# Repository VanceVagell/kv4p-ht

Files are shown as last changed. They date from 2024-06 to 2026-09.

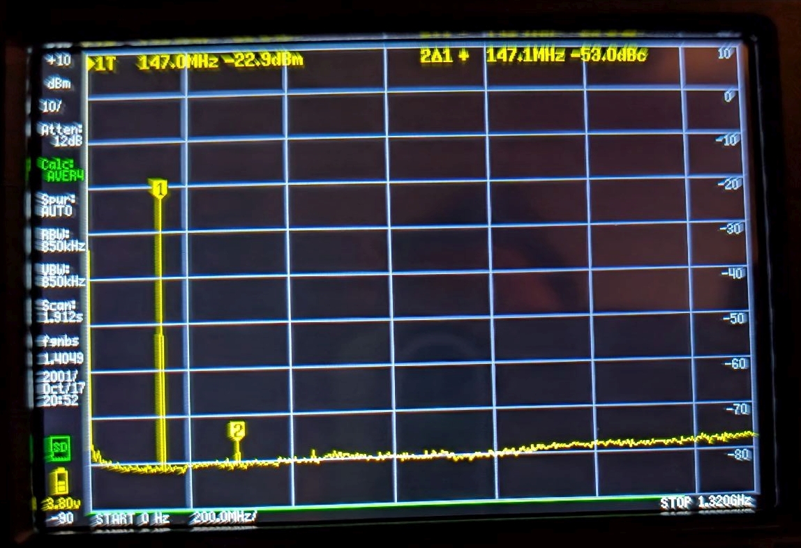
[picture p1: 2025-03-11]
website-src/img/spectral-purity-PCB-v1.8x.jpg

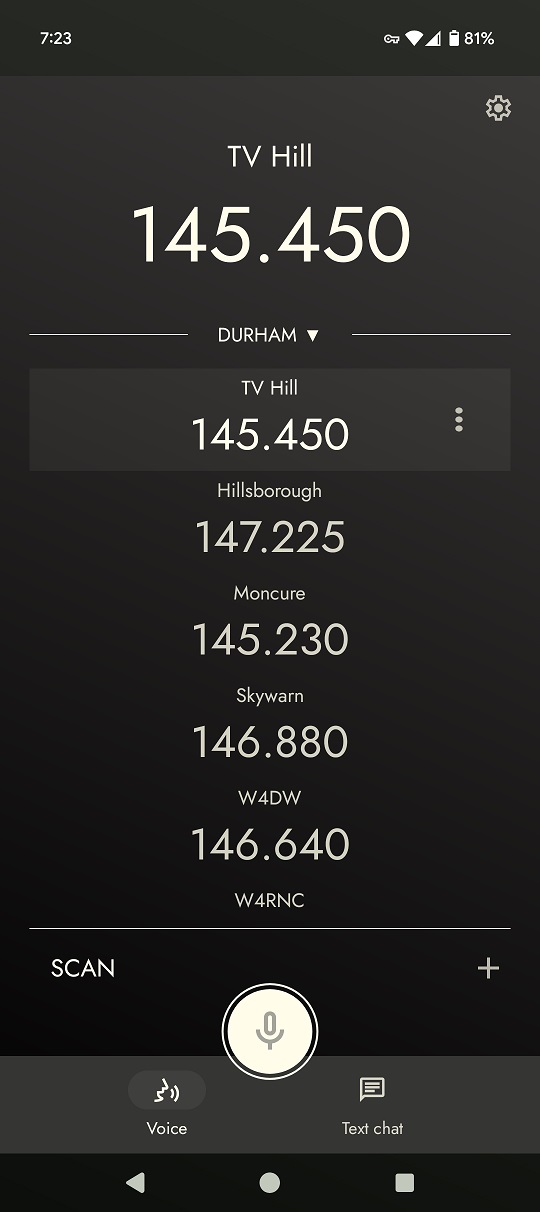
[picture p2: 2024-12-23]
website-src/img/kv4p-ht-voice.jpg

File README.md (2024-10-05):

# kv4p-ht
Open source handheld ham radio project kv4p HT

Please see the main project site: https://kv4p.com

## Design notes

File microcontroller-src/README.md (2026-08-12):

## Table of Contents

- [Table of Contents](#table-of-contents)
- [Getting Started](#getting-started)
   - [Install ESP32 Drivers](#install-esp32-drivers)
   - [Choose your build environment](#choose-your-build-environment )
- [Option 1: PlatformIO](#option-1-platformio)
   - [Install PlatformIO](#install-platformio)
   - [Opening the Project (PlatformIO)](#opening-the-project-platformio)
   - [Building the Project (PlatformIO)](#building-the-project-platformio)
   - [Uploading to the ESP32 (PlatformIO)](#uploading-to-the-esp32-platformio)
   - [PlatformIO Specific Notes](#platformio-specific-notes)
- [Option 2: Arduino IDE](#option-2-arduino-ide)
   - [Install Arduino IDE](#install-arduino-ide)
   - [Install ESP32 Board Support](#install-esp32-board-support)
   - [Install Required Libraries](#install-required-libraries)
   - [Opening the Project (Arduino IDE)](#opening-the-project-arduino-ide)
   - [Building the Project (Arduino IDE)](#building-the-project-arduino-ide)
   - [Uploading to the ESP32 (Arduino IDE)](#uploading-to-the-esp32-arduino-ide)
- [Additional Notes](#additional-notes)

## Getting Started

### Install ESP32 Drivers

1. **Download and Install the Appropriate Driver for Your System:**
   - **CP210x Drivers:** [Silicon Labs CP210x Drivers](https://www.silabs.com/developer-tools/usb-to-uart-bridge-vcp-drivers?tab=downloads)

   Ensure that the driver installation is successful:
   - **Windows:** Check the Device Manager for the COM port associated with your ESP32.
   - **macOS/Linux:** Verify the presence of `/dev/tty.*` devices corresponding to your ESP32.

### Choose Your Build Environment

You can use either Platform IO or Arduino IDE as your build environment. 

- **PlatformIO (Preferred):**
  - Our primary build environment, and the easiest way to get started.
  - Offers an integrated development environment with advanced features such as dependency management, project configuration, and integrated debugging.
  - Ideal for users who require more control and flexibility over their development workflow.
- **Arduino IDE:**
  - Provides a simpler interface that is beginner-friendly and widely used within the Arduino community.
  - Unfortunately for a larger project like `kv4p-ht`, the initial setup is less automated and more complex.

## Option 1: PlatformIO

### Install PlatformIO

1. **Download and Install VSCode:**
   - [Download VSCode](https://code.visualstudio.com/download) and follow the installation instructions for your operating system.

2. **Install PlatformIO Extension:**
   - Open VSCode.
   - Navigate to the Extensions view by clicking on the **Extensions** icon in the Activity Bar on the side of VSCode or pressing `Ctrl+Shift+X` (`Cmd+Shift+X` on macOS).
   - In the search bar, type **"PlatformIO IDE"**.
   - Locate the **PlatformIO IDE** extension by PlatformIO and click **Install**.

3. **Verify Installation:**
   - After installation, the **PlatformIO** icon (alien head) should appear in the VSCode sidebar.
   - Click the **PlatformIO** icon to open the PlatformIO Home interface.

### Opening the Project (PlatformIO)

1. **Open VSCode.**
2. **Open the Project Directory:**
   - Navigate to `kv4p-ht/microcontroller-src/`.
   - Open this directory in VSCode by selecting `File` > `Open Folder` and choosing the specified path.
   - Ensure that the directory contains the `platformio.ini` file to recognize it as a PlatformIO project.
   - *Note:* Opening the root directory may prevent VSCode from recognizing it as a PlatformIO project.
   - *Note:* After opening the project, if VSCode shows a notification bar at the top indicating restricted mode, click **Manage** and then **Trust** in the subsequent dialog to enable all capabilities.

### Building the Project (PlatformIO)

1. **Build the Project:**
   - Click the **Build** icon (checkmark) in the PlatformIO toolbar.
   - Alternatively, press `Ctrl+Alt+B` (`Cmd+Alt+B` on macOS).

2. **Monitor Build Process:**
   - The integrated terminal will display the compilation process.
   - Ensure there are no errors during the build.
   - A successful build will indicate that the firmware is ready for upload.

### Uploading to the ESP32 (PlatformIO)

1. **Connect Your ESP32:**
   - Use a USB cable to connect your ESP32 development board to your computer.
   - Ensure the board is recognized by your system:
     - **Windows:** Check the Device Manager for the COM port.
     - **macOS/Linux:** Check for `/dev/tty.*` devices.

2. **Select the Correct Serial Port:**
   - PlatformIO typically auto-detects the connected board.
   - If not detected, manually specify the serial port:
     - Click on the port icon in the PlatformIO toolbar.
     - Select the appropriate port from the list.

3. **Upload the Firmware:**
   - Click the **Upload** icon (right arrow) in the PlatformIO toolbar or press `Ctrl+Alt+U` (`Cmd+Alt+U` on macOS).
   - PlatformIO will compile (if not already built) and upload the firmware to the ESP32.

4. **Monitor Upload Process:**
   - Watch the terminal for messages indicating upload progress.
   - Upon successful upload, a confirmation message will appear.

### PlatformIO Specific Notes

- **Renaming the Main File for IntelliSense:**
   - ~~**For IntelliSense to work properly in PlatformIO**, rename the main project file from `.ino` to `.cpp`. For example, rename `kv4p_ht_esp32_wroom_32.ino` to `kv4p_ht_esp32_wroom_32.cpp`.~~
      - I don't think this is necessary anymore. My (@SmittyHalibut) PlatformIO does all the right things just editing a .ino file now (Jan 2025).
   - **Important:** Do **not** commit this renamed file to the repository. Keeping the file as `.ino` in the repository ensures compatibility with the Arduino IDE build process.
   - **Workflow Suggestion:**
      - When working locally in PlatformIO, perform the rename to benefit from IntelliSense.
      - Before committing changes, revert the file extension back to `.ino` to maintain Arduino IDE compatibility.

## Option 2: Arduino IDE

### Install Arduino IDE

1. **Download and Install Arduino IDE:**
   - Visit the [Arduino Software Page](https://www.arduino.cc/en/software) and download the latest version suitable for your operating system.
   - Follow the installation instructions provided on the website.

### Install ESP32 Board Support

1. **Open Arduino IDE.**

2. **Install ESP32 Boards:**
   - Go to `Tools` > `Board` > `Boards Manager`.
   - In the Boards Manager window, search for **"ESP32"**.
   - Find **"esp32"** by Espressif Systems.
   - Select version **2.0.17**. The code needs to be updated to support 3.X
   - Click **Install** and Wait for the installation to complete.

3. **Configure**
   - Go to `Tools` > `Events Run On` > Select `Core 0`
     - This is done so audio processing interrupts run on a separate thread for maximum stability.
   - Go to `Tools` > `Partition Scheme` > Select `Minimal SPIFFS (1.9MB APP with OTA/190KB SPIFFS)`
     - This optimizes partitions for large code.

### Install Required Libraries

1. Install DRA818:**

   > **Note:** The version of the DRA818 library available through the Arduino Library Manager is currently broken. To ensure proper functionality, you need to install it manually from the official GitHub release.

   - **Download the DRA818 Library ZIP:**
     - Visit this [commit of the DRA818 v1.0.1 library](https://github.com/fatpat/arduino-dra818.git#89582e3ef7bf3f31f1af149e32cec16c4b9e4cf2). It contains additional definitions needed for the `SA818_VHF` and `SA818_UHF` radio modules.
     - Click the green `Code` button and then `Download ZIP`.

   - **Add the DRA818 Library to Arduino IDE:**
     - Open the Arduino IDE.
     - Go to `Sketch` > `Include Library` > `Add .ZIP Library...`.
     - In the file dialog, navigate to the location where you downloaded the `arduino-dra818-master.zip` file.
     - Select the ZIP file and click **Open**.
     - A confirmation message should appear indicating that the library was added successfully.

2. **Install AudioTools:**

   - **Download the AudioTools Library ZIP:**
     - Visit the [AudioTools v1.2.3 Release Page](https://github.com/pschatzmann/arduino-audio-tools/releases/tag/v1.2.3).
     - Click on the **"Source code (zip)"** link to download the ZIP file of the library.

   - **Add the AudioTools Library to Arduino IDE:**
     - Open the Arduino IDE.
     - Go to `Sketch` > `Include Library` > `Add .ZIP Library...`.
     - In the file dialog, navigate to the location where you downloaded the `arduino-audiotools-1.2.3.zip` file.
     - Select the ZIP file and click **Open**.
     - A confirmation message should appear indicating that the library was added successfully.

3. **Install adpcm:**

   - **Download the adpcm Library ZIP:**
     - Visit the [adpcm v1.2.1 Release Page](https://github.com/pschatzmann/adpcm/releases/tag/v1.2.1).
     - Click on the **"Source code (zip)"** link to download the ZIP file of the library.

   - **Add the adpcm Library to Arduino IDE:**
     - Open the Arduino IDE.
     - Go to `Sketch` > `Include Library` > `Add .ZIP Library...`.
     - In the file dialog, navigate to the location where you downloaded the `codec-adpcm-1.2.1.zip` file.
     - Select the ZIP file and click **Open**.
     - A confirmation message should appear indicating that the library was added successfully.

4. **Install esp32-afsk:**

   - Navigate to `Sketch` > `Include Library` > `Manage Libraries`.
   - In the **Library Manager** window, enter **"esp32-afsk"** into the search bar.
   - Locate the **esp32-afsk** library by **Dmitry Kaukov** in the search results.
   - Click the **Install** button to add the library to your Arduino environment.

5. **Confirm All Libraries Are Installed:**

   - After completing the above steps, go to `Sketch` > `Include Library` and scroll down to the bottom where you will find the section labeled `Contributed Libraries` (light gray). Ensure that **adpcm**, **audio-tools**,  **DRA818** and **esp32-afk** are listed.
   - If any libraries are missing, revisit the installation steps to ensure they were added correctly.

### Opening the Project (Arduino IDE)

1. **Open the Project:**
   - Go to `File` > `Open`.
   - Navigate and open: `kv4p-ht/microcontroller-src/kv4p_ht_esp32_wroom_32/kv4p_ht_esp32_wroom_32.ino`.

### Building the Project (Arduino IDE)

1. **Select the ESP32 Board:**
   - Go to `Tools` > `Board` and select **"ESP32 Dev Module"**.

2. **Select the Correct Port:**
   - Connect your ESP32 to your computer via USB.
   - Go to `Tools` > `Port` and select the appropriate COM port (Windows) or `/dev/tty.*` device (macOS/Linux).

3. **Verify the Sketch:**
   - Click the **Verify** button (checkmark) in the Arduino toolbar or press `Ctrl+R` (`Cmd+R` on macOS).
   - The IDE will compile the sketch and display any errors or warnings in the output pane.
   - Ensure that the sketch compiles without errors.

### Uploading to the ESP32 (Arduino IDE)

1. **Upload the Firmware:**
   - Click the **Upload** button (right arrow) in the Arduino toolbar or press `Ctrl+U` (`Cmd+U` on macOS).
   - The Arduino IDE will compile (if not already done) and upload the firmware to the ESP32.
   - Monitor the output pane for upload progress and confirmation of success.

## Additional Notes

- **Consistent Project Structure:**
  - Ensure that any changes made in one environment (e.g., library installations, code modifications) are compatible with the other to maintain consistency across both build systems.

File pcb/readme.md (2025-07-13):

Build:
```
../scripts/nvs_partition_gen.py generate board-config.csv  board-config.bin 0x6000
```

Flash:
```
esptool.py  write_flash 0x9000 board-config.bin
```

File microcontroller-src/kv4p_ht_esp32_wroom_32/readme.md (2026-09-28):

# KV4P-HT Communication Protocol

## Overview

The KV4P-HT protocol defines the communication interface between the microcontroller and external systems. It specifies message structures and command types for data exchange.

## Protocol Changelog

### v2.0.0.2 (Unreleased, FW: 17)

* Live voice audio changed from Opus on command `0x07` to 16 kHz 4-bit ADPCM on command `0x0C`.
* Added FreeDV 2400B digital voice negotiation with `FEATURE_HAS_FREEDV_2400B` and `HOST_STATE_FREEDV_2400B`. When enabled, 7-byte Codec2 1300 frames use `COMMAND_HOST_TX_DIGITAL` and `COMMAND_RX_DIGITAL` (`0x0E`) instead of ADPCM audio.
* Added standard KISS `TXDELAY`, `PERSIST`, and `SLOTTIME` controls. Firmware performs CSMA/p-persistence channel access and queues up to two outbound AX.25 KISS DATA frames.
* Added `COMMAND_HOST_TX_AX25` (`0x0F`) for AX.25 transmission with a temporary TX frequency, bandwidth, and CTCSS configuration.

### v2.0.0.0 (FW: 17)

* Serial transport now uses KV4P KISS framing. The old `0xDEADBEEF` delimiter and top-level length field are removed.
* Standard KISS DATA frames carry AX.25 packets directly.
* kv4p-specific commands are carried in KISS SETHARDWARE vendor frames with payload prefix `"KV4P"` and protocol version `1`.
* `COMMAND_HELLO` now carries the version/status payload after firmware radio initialization completes.
* Android now sends `COMMAND_HOST_DESIRED_STATE` snapshots for radio config, filters, PTT, audio-open, high-power, and RSSI state.
* Firmware replies with `COMMAND_DEVICE_STATE` snapshots describing applied state.
* Legacy one-shot control commands were removed.

### v1.9.4 (FW: 14)

* Added `COMMAND_HOST_HL` (`0x08`) and `COMMAND_HOST_RSSI` (`0x09`).
* Changed the `COMMAND_HOST_CONFIG` payload from a radio-type byte to an `isHigh` boolean.
* Replaced the hardware field in the version payload with `rfModuleType` and a `features` bitmask.
* Added feature bits for high/low power control and physical PTT support.

### v1.8.0 (FW: 13)

* Introduced the unified framed host/firmware protocol and core command set in `protocol.h`.
* Frames use the four-byte `0xDEADBEEF` delimiter, a command byte, and a two-byte (`uint16_t`) payload length.
* Added `COMMAND_WINDOW_UPDATE` **(ESP32 → Android)**.
* The version payload includes firmware version, radio status, hardware version, and `windowSize`.
* Live voice audio uses Opus on command `0x07` in both directions.
* Window-based flow control applies to incoming commands.

## Packet Structure

Serial messages use KV4P KISS transport.

### AX.25 KISS DATA Frames

AX.25 packets are sent as standard KISS DATA frames:

```
FEND 0x00 <escaped AX.25 frame bytes> FEND
```

The AX.25 payload does not include a kv4p command byte, decoder ID, or top-level length field.

### KV4P Vendor Frames

Non-AX.25 kv4p commands are sent as KISS SETHARDWARE vendor frames:

```
FEND 0x06 "KV4P" 0x01 <kv4pCommand> <escaped command payload bytes> FEND
```

The payload prefix is ASCII `"KV4P"`, followed by `uint8 protocolVersion = 1`, the existing kv4p command byte, and the existing command payload bytes.

### Escaping

Inside KISS frame payloads, bytes are escaped as follows:

| Byte | Encoded as |
| ---- | --- |
| `0xC0` | `0xDB 0xDC` |
| `0xDB` | `0xDB 0xDD` |

All other bytes are written unchanged. The old `0xDEADBEEF` delimiter and top-level `uint16` length field are no longer present on the wire.

## Incoming KISS Frame Types (Android → ESP32)

| KISS Command | Name | Description |
| --- | --- | --- |
| `0x00` | KISS DATA frame | Transmit AX.25 packet bytes |
| `0x01` | KISS TXDELAY | Set TX lead time in 10 ms units |
| `0x02` | KISS PERSIST | Set p-persistence probability |
| `0x03` | KISS SLOTTIME | Set CSMA slot time in 10 ms units |
| `0x06` | KISS SETHARDWARE frame | Carry a kv4p vendor command frame |

Firmware queues exactly two outbound AX.25 jobs in FIFO order. A job waits for a clear carrier,
then immediately makes a PERSIST decision. A failed decision waits SLOTTIME before sensing again;
a busy channel restarts CSMA without blocking normal firmware work. A third job is dropped, so the
higher-level protocol/application must retry or pace traffic. Adjacent ordinary KISS DATA jobs are
sent under one PTT assertion after winning CSMA; frequency-override jobs are sent separately.
Defaults are TXDELAY 650 ms, PERSIST 63, and SLOTTIME 100 ms. TXDELAY currently uses the modem's
fixed flag preamble plus configurable carrier silence; the bundled esp32-afsk API cannot set a
variable flag preamble at runtime.
TXDELAY and SLOTTIME are one-byte 10 ms values (65 and 10 by default); PERSIST is a
one-byte p-persistence probability value from 0 to 255 (63 by default).

Channel busy is `ourTx || afskDcd || rfCarrierDetected`. `afskDcd` is the qualified AFSK flag
detector. `rfCarrierDetected` is SoftSQ's raw HF-noise decision, independent of CTCSS and UI
squelch settings.

## Incoming KV4P Vendor Commands (Android → ESP32)

Audio command ID `0x07` was used by the historical Opus voice stream. Current firmware uses `0x0C` for 4-bit ADPCM audio so hosts can keep compatibility code for both the old Opus stream and the current ADPCM stream.

| Command Code | Name | Description |
| --- | --- | --- |
| `0x0C` | `COMMAND_HOST_TX_AUDIO` | Receive Tx 4-bit ADPCM audio data (payload required, flow-controlled) |
| `0x0D` | `COMMAND_HOST_DESIRED_STATE` | Desired radio/control state snapshot |
| `0x0E` | `COMMAND_HOST_TX_DIGITAL` | Receive one 7-byte Codec2 1300 frame for FreeDV 2400B |
| `0x0F` | `COMMAND_HOST_TX_AX25` | Queue an AX.25 job with temporary TX configuration |

`COMMAND_HOST_TX_AX25` payload is packed as `float freqTx`, `uint8 bw`, `uint8 ctcssTx`, then
the AX.25 bytes. Before CSMA, firmware temporarily tunes both RX and TX to the target frequency,
waits 260 ms for the receiver and carrier detectors to settle, then senses and transmits on that
target. This preparation occurs only while the radio is idle and host TX remains allowed.
After its transmission, firmware restores the latest normal desired radio state.

## Outgoing KISS Frame Types (ESP32 → Android)

| KISS Command | Name | Description |
| --- | --- | --- |
| `0x00` | KISS DATA frame | Received AX.25 packet bytes |
| `0x06` | KISS SETHARDWARE frame | Carry a kv4p vendor command frame |

## Outgoing KV4P Vendor Commands (ESP32 → Android)

Audio command ID `0x07` was used by the historical Opus voice stream. Current firmware uses `0x0C` for 4-bit ADPCM audio so hosts can keep compatibility code for both the old Opus stream and the current ADPCM stream.

| Command Code | Name | Description |
| --- | --- | --- |
| `0x01` | `COMMAND_DEBUG_INFO` | Sends debug info message |
| `0x02` | `COMMAND_DEBUG_ERROR` | Sends debug error message |
| `0x03` | `COMMAND_DEBUG_WARN` | Sends debug warning message |
| `0x04` | `COMMAND_DEBUG_DEBUG` | Sends debug debug-level message |
| `0x05` | `COMMAND_DEBUG_TRACE` | Sends debug trace message |
| `0x06` | `COMMAND_HELLO` | Hello handshake message with version/status and initial device state |
| `0x0C` | `COMMAND_RX_AUDIO` | Sends Rx 4-bit ADPCM audio data (payload required) |
| `0x09` | `COMMAND_WINDOW_UPDATE` | Updates available receive window |
| `0x0B` | `COMMAND_DEVICE_STATE`  | Applied radio/control state snapshot |
| `0x0E` | `COMMAND_RX_DIGITAL` | Sends one demodulated 7-byte Codec2 1300 frame |

## Command Parameters

### `COMMAND_HELLO` Parameters

```c
struct version {
  uint16_t     ver;               // 2 bytes
  char         radioModuleStatus; // 1 byte
  uint32_t     windowSize;        // 4 bytes
  uint8_t      rfModuleType;      // 1 byte (enum)
  float        minRadioFreq;      // 4 bytes
  float        maxRadioFreq;      // 4 bytes
  uint8_t      features;          // 1 byte (bitmask)
} __attribute__((__packed__));
typedef struct version Version;

// features bitmask
#define FEATURE_HAS_HL      (1 << 0)
#define FEATURE_HAS_PHY_PTT (1 << 1)
#define FEATURE_HAS_ESP32_AFSK (1 << 2)
#define FEATURE_HAS_FREEDV_2400B (1 << 3)

struct hello {
  Version     version;
  DeviceState deviceState;
} __attribute__((__packed__));
typedef struct hello Hello;
```

Firmware sends `COMMAND_HELLO(Hello)` after boot-time radio initialization. Android validates the version/status fields, adopts `minRadioFreq`/`maxRadioFreq` as the module's usable RX range, and seeds its initial radio-module state from the appended `DeviceState`.

### `COMMAND_HOST_DESIRED_STATE` Parameters

```c
struct host_desired_state {
  uint32_t sequence;
  int32_t  memoryId; // -1 means VFO/no memory
  uint16_t flags;
  uint8_t  bw;
  float    freq_tx;
  float    freq_rx;
  uint8_t  ctcss_tx;
  uint8_t  squelch;
  uint8_t  ctcss_rx;
} __attribute__((__packed__));
typedef struct host_desired_state HostDesiredState;

#define HOST_STATE_RADIO_CONFIG_VALID (1 << 0)
#define HOST_STATE_PTT_REQUESTED      (1 << 1)
#define HOST_STATE_RX_AUDIO_OPEN      (1 << 2)
#define HOST_STATE_HIGH_POWER         (1 << 3)
#define HOST_STATE_RSSI_ENABLED       (1 << 4)
#define HOST_STATE_FILTER_PRE         (1 << 5)
#define HOST_STATE_FILTER_HIGH        (1 << 6)
#define HOST_STATE_FILTER_LOW         (1 << 7)
#define HOST_STATE_TX_ALLOWED          (1 << 11)
#define HOST_STATE_ENABLE_STATUS_REPORTS (1 << 12)
#define HOST_STATE_FREEDV_2400B          (1 << 13)
```

Android sends the full desired-state snapshot whenever one field changes. Firmware applies changed radio/filter/control fields, derives its mode, and marks device state dirty so `deviceStateLoop()` can report the result with `COMMAND_DEVICE_STATE`.

`HOST_STATE_TX_ALLOWED` is a persisted host-controlled safety flag that defaults off. Firmware only accepts transmit requests, including KISS DATA AX.25 frames and host PTT requests, while this flag is set.

`HOST_STATE_ENABLE_STATUS_REPORTS` is a non-persisted session flag that defaults off. kv4p HT Android sets it after HELLO so firmware sends `COMMAND_DEVICE_STATE`; generic KISS TNC hosts can leave it off to receive only standard KISS DATA frames.

`HOST_STATE_FREEDV_2400B` is a non-persisted global flag. When it and a session's `HOST_STATE_RX_AUDIO_OPEN` flag are set, firmware sends 7-byte Codec2 frames on `COMMAND_RX_DIGITAL` instead of ADPCM audio. During host-requested PTT, the host must continuously send 7-byte `COMMAND_HOST_TX_DIGITAL` frames. Each frame represents 320 speech samples at 8 kHz and 1,920 modem samples at 48 kHz (40 ms).

Android treats `DeviceState.appliedSequence` as the acknowledgement for the latest desired-state snapshot. If received device state does not match the last sent desired snapshot, Android may retry the exact same `HostDesiredState` with the same `sequence`. Retries are bounded; they are not new logical state changes and must not increment `sequence`.

### `COMMAND_DEVICE_STATE` Parameters

```c
struct device_state {
  uint32_t appliedSequence;
  int32_t  memoryId; // -1 means VFO/no memory
  uint16_t flags;
  uint8_t  bw;
  float    freq_tx;
  float    freq_rx;
  uint8_t  ctcss_tx;
  uint8_t  squelch;
  uint8_t  ctcss_rx;
  char     radioModuleStatus;
  uint8_t  mode;
  uint8_t  lastError;
  uint8_t  latestRssi;
} __attribute__((__packed__));
typedef struct device_state DeviceState;

#define DEVICE_STATE_PHYS_PTT_DOWN (1 << 8)
#define DEVICE_STATE_TX_ACTIVE     (1 << 9)
#define DEVICE_STATE_SQUELCHED     (1 << 10)
#define DEVICE_STATE_TX_ALLOWED     HOST_STATE_TX_ALLOWED
#define DEVICE_STATE_ENABLE_STATUS_REPORTS HOST_STATE_ENABLE_STATUS_REPORTS
```

When `HOST_STATE_ENABLE_STATUS_REPORTS` is set, firmware sends `COMMAND_DEVICE_STATE` from `deviceStateLoop()`. State producers such as desired-state reconciliation, RSSI changes, squelch changes, and physical PTT changes set a dirty flag instead of writing serial frames directly. The next loop pass flushes dirty state, so change reports are effectively immediate but still async and coalesced through one sender. Firmware also sends `COMMAND_DEVICE_STATE` every 500 ms as a heartbeat/state refresh while status reports are enabled. RSSI/S-meter data is reported through `latestRssi`; there is no separate S-meter report command.

Scanning remains Android-owned because Android owns the memory list, memory groups, skip-during-scan flags, offsets, and UI selection. Firmware reports the current squelch state with `DEVICE_STATE_SQUELCHED`; Android uses that received state to decide when to advance to the next memory.

Firmware persists stable radio settings in NVS and restores them on startup before sending `COMMAND_HELLO`: memory id, bandwidth, TX/RX frequencies, TX/RX tones, squelch level, high-power preference, RSSI preference, filter flags, and TX allowed. If NVS is empty, firmware loads safe defaults, marks radio config valid, and starts with TX disabled until the host sends an allowed TX frequency. If persisted TX/RX frequencies are outside the configured RF module's range, firmware clamps them into range and clears `memoryId` to `-1` before applying radio config. Transient state is not restored: sequence, PTT requested, RX audio open, and status-report enablement always start clear.

### `COMMAND_WINDOW_UPDATE` Parameters **(ESP32 → Android)**

```c
struct window_update {
  uint32_t windowSize; // 4 bytes
} __attribute__((__packed__));
typedef struct window_update WindowUpdate;
```

## Flow Control

A window-based flow control mechanism, inspired by HTTP/2, is used to regulate the amount of data sent from Android to the ESP32:

1. **Window Size Declaration**:

   * The ESP32 sends a "desired" initial window size in the `COMMAND_HELLO` payload.
   * This typically matches the size of its internal USB receive buffer.

2. **Window Consumption**:

   * Each incoming command from Android reduces the remaining window size by the size of the entire packet.
   * All commands, not just `COMMAND_HOST_TX_AUDIO`, are subject to this flow control.

3. **Blocking on Exhaustion**:

   * If the next packet does not fit in the remaining window, Android must wait until space is available.
   * Effectively, this blocks transmission when `windowSize < packet size`.

4. **Window Replenishment**:

   * Once the ESP32 finishes processing a packet, it sends a `COMMAND_WINDOW_UPDATE` message.
   * This increases the window size, allowing Android to resume transmission.

5. **Optional Implementation**:

   * Implementing flow control is optional.
   * A compliant implementation may ignore windowSize and COMMAND_WINDOW_UPDATE messages entirely.
   * This is primarily useful when dealing with fast data sources like APRS modems that can generate large amounts of audio data rapidly.
   * When audio is sourced from the ADC, it is inherently flow-controlled by the sampling hardware, making software flow control less necessary.

## Command Handling Strategy

* Android sends complete `COMMAND_HOST_DESIRED_STATE` snapshots instead of separate one-shot control commands.
* Firmware reports the applied runtime state through `COMMAND_DEVICE_STATE` snapshots.
* Firmware state producers mark device state dirty; only `deviceStateLoop()` sends `COMMAND_DEVICE_STATE`.
* Android compares desired and device state. If the device does not acknowledge the latest desired snapshot, Android may resend the same snapshot/sequence a small number of times.
* KISS DATA frames carry AX.25 packets directly, outside the kv4p vendor command namespace.
* Android-to-firmware vendor commands are subject to **window-based flow control**.

## Byte Order and Bit Significance

* All multi-byte fields are encoded in little-endian format.
* Bitmask values follow LSB-first ordering (bit 0 is the least significant).

## Example Packets

### Desired-state update

```
[ 0xC0, 0x06, 'K', 'V', '4', 'P', 0x01, 0x0D, ...state bytes..., 0xC0 ]
```

* `0xC0`: KISS FEND
* `0x06`: KISS SETHARDWARE
* `"KV4P" 0x01`: KV4P vendor prefix and protocol version
* `0x0D`: `COMMAND_HOST_DESIRED_STATE`

### Example Debug Message

```
[ 0xC0, 0x06, 'K', 'V', '4', 'P', 0x01, 0x01, 'E', 'r', 'r', 'o', 'r', 0xC0 ]
```

* `0x06`: KISS SETHARDWARE
* `"KV4P" 0x01`: KV4P vendor prefix and protocol version
* `0x01`: `COMMAND_DEBUG_INFO`
* `'Error'`: Debug message content

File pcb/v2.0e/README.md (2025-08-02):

# Ordering kv4p-HT v2 boards from JLCPCB

## Things you'll need:

Use Chrome.  For some reason, the JLCPCB order process is broken for me on FireFox.  Much sadness.

You'll need the following files:
* VHF:
  * <https://github.com/VanceVagell/kv4p-ht/blob/main/pcb/v2.0e/kv4p-ht/production-vhf/kv4p_HT_2.0e.zip>
  * <https://github.com/VanceVagell/kv4p-ht/blob/main/pcb/v2.0e/kv4p-ht/production-vhf/bom.csv>
  * <https://github.com/VanceVagell/kv4p-ht/blob/main/pcb/v2.0e/kv4p-ht/production-vhf/positions.csv>
* UHF:
  * <https://github.com/VanceVagell/kv4p-ht/blob/main/pcb/v2.0e/kv4p-ht/production-uhf/kv4p_HT_2.0e.zip>
  * <https://github.com/VanceVagell/kv4p-ht/blob/main/pcb/v2.0e/kv4p-ht/production-uhf/bom.csv>
  * <https://github.com/VanceVagell/kv4p-ht/blob/main/pcb/v2.0e/kv4p-ht/production-uhf/positions.csv>

## Order the PCB

* Go to <https://jlcpcb.com/>
* Click: "Add Gerber," and upload the `kv4p_HT_2.0e.zip` you downloaded before.
* JLCPCB will ask you a bunch of questions about the file.  The auto-loaded defaults are sufficient, but if you know you want to change something (solder mask color, etc) do it here.

**If all you want are the circuit boards** and you intend to **source all the parts and assemble it yourself**, then click Save To Cart here.  Check out, etc, you're done.

If you intend to use **JLCPCB to do assembly** for you (recommended), then **DO NOT (YET) CLICK Save To Cart** and proceed to the next section.

## Add PCB Assembly to the order

* Scroll to the bottom of the page, and toggle On the "PCB Assembly" option.
* I strongly recommend you click "Confirm Parts Placement: Yes".  You'll see why in a bit.  Otherwise, the defaults should be ok:
  * Economic
  * Top Side
  * 5 boards (or 2 if you want to save money on parts and only want 1 or 2 radios)
  * Tooling holes Added by JLCPCB
  * Parts selection by Customer
  * All the default "Advanced Options" are good too.
* NOW you click the big blue button, that now says "Next" instead of "Save to Cart." This enters the PCB Assembly stuff.

## Configure PCB Assembly

This next page has several tabs that you'll work your way through.

### PCB Tab

* There's not a lot here.  Feel free to look at the board and marvel at its tinyness, but really just click Next.

### Bill Of Material Tab

* Click "Add BOM File" and upload `bom.csv`
* Click "Add CPL File" and upload `positions.csv`
* Click "Process BOM & CPL".

This displays a list of parts, and quantities.  Scroll to the bottom; all the "problems" will be down there.

Things to look out for:
* "Parts Shortfall" and "Out of stock" means there aren't enough of this part in stock for your order.
  * Click on the Magnifier to search for a substitute part.  This is a complex topic that I won't try to cover here.
* Any part with a Yellow "!" is something you should look at.
  * It's known that SW3 and SW4 have !, you can ignore those (line items with the same part number.)
  * And J5 (USB-C) socket has a "special handling fee" because they're difficult to place.  This is also known.
* You can also leave a part completely unpopulated by un-checking it (far right column) if there's something you want to populate yourself for whatever reason.
* When the BOM looks good, click "Next".  If you left any parts unpopulated, it'll ask for confirmation.

### Component Placements Tab

This is the tricky part.  JLCPCB and KiCAD don't always agree on what "0 degrees" or "x=0, y=0" means for part placement.  So we need to nudge parts up/down/left/right, or rotate them, so JLCPCB knows how to assemble them correctly.

MOST passive parts don't require any adjustment.  But several ICs do, connectors typically do, and some polarized components (tantalum capacitors) do.

To use the tool on this page:

* You can zoom in and out using the scroll wheel.
* You can move the WHOLE BOARD around by right-clicking on it and dragging.
* You can select parts for adjustment by left-clicking on them, or clicking on the part in the BOM list on the right side of the screen.
* Once a component/components are selected, you can move them around using the arrow keys, and you can rotate them using the buttons along the top of the tool box.
* There are two pairs of Rotate buttons, one pair has a dot in the middle of it.  If you have multiple parts selected, use the rotate with the dot. Each part will rotate around its own axis.  The rotate without the dot will rotate everything around the group axis; almost certainly not what you want if you have multiple parts selected.
* For through-hole parts, position them by looking at the bottom of the board (Top and Bottom buttons in the upper right corner of the toolbox), and moving until the pins are lined up with the pads.  The pins will show through the board.

These are the parts that need adjustment, as of the time of this writing (2025-01-10):
* J1, the SMA.  90deg anti-clockwise.
* SW1, SW2, the PTT buttons. 180 deg, and line up pins to pads on bottom.
* J4, J6, the 2x pin headers: Rotate 90 deg.
* J5, USB-C: Line up pins and pads on bottom.
* U5, the ESP32.  90 deg clockwise, then line up pads.
* U4, USB serial chip: 90 deg clockwise. Purple dot by white arrow on board.
* C2, C16, tantalum caps: 180 deg.
* D1, the NeoPixel LED: 90 deg anti-clockwise. Purple plus by white plus on board.

Look around the board for any obviously mis-placed parts and fix them.  The black-and-white 2x2 checker board are parts that don't have 3D models.  Don't worry about these, JLCPCB will make sure they're placed right.  They also do a sanity check of the placements YOU make, and have caught mistakes I've made in the past. They're quite good.

When you're happy, click Next.

### Quote & Order tab

Here you see the costs, etc.

The only thing you need to select is "Product Description".  I usually use "Audio and Video Appliance" -> "Wireless Radio - HS Code 852990"

## Done

NOW you can click **Save To Cart**.  :-)

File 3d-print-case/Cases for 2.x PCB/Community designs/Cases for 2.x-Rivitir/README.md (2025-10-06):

> Filenames may vary—use the most recent release assets for printing.

---

## Case Options

### 1) Thin Case (full enclosure)

- **Purpose:** daily protection with a slim profile that still allows good grip and access to controls.
- **Lids:**  
  - **Solid Lid** (no magnets) — clean look, maximum rigidity.  
  - **Magnet Lid** — same geometry with Ø**12.5 mm** × **1.5 mm** pockets for disc magnets.
- **Fasteners:** **6× M3** screws into **M3 heat-set inserts** (install depth **5 mm**).
- **Access & cooling:** body shape preserves ventilation paths and control access (depends on radio model cutouts).

### 2) Cradle Case (radio + phone)

- **Purpose:** mount the HT and keep your **phone docked** for digital modes, logging, APRS maps, etc.
- **Radio interface:** same magnet pocket spec (Ø**12.5 mm**, **1.5 mm** depth) to attach to a radio-mounted backplate.
- **Phone shelf:** flat cradle surface with front lip; add thin foam or rubber tape for grip and to protect the phone.
- **Cable-friendly:** open edges accommodate common audio/PTT or data cables (model-dependent).

---

## Bill of Materials (per case)

| Item | Spec | Qty | Notes |
|---|---|---:|---|
| Heat-set inserts | M3, **5 mm** install depth (standard brass) | 6 | Thin Case only |
| Screws | M3×6–8 pan head | 6 | Match length to your printer’s fit |
| Magnets | Disc Ø**12.5 mm** × **1–1.5 mm** | up to pockets | Use N35–N52 neodymium |
| Adhesive for magnets | CA (super glue) or 5-min epoxy | — | CA is quick, epoxy is stronger |
| Foam/rubber tape (optional) | 1–2 mm thick | as needed | Phone shelf grip / anti-rattle |

> The magnet pockets are **1.5 mm deep**. If your magnets are 1.0 mm thick, add a thin CA layer or adhesive pad behind them to sit flush.

---

## Printing Guidelines

- **Material:** PETG recommended (tough and heat-resistant). ABS/ASA also good for outdoor use. PLA+ is acceptable indoors.
- **Layer height:** 0.20 mm (0.16–0.24 mm works).
- **Perimeters:** 3–4 walls for strength around inserts and magnets.
- **Infill:** 20–30% gyroid or grid (40% for the phone shelf if you prefer extra rigidity).
- **Top/Bottom:** 4–6 layers.
- **Supports:** Only if your printer struggles with the phone lip or specific overhangs (most parts are support-light).
- **Orientation:**  
  - **Thin Case body/lid:** print flat on the largest face.  
  - **Cradle body:** print flat on the backplate side; phone shelf flat.

---

## Assembly — Thin Case

1. **Test fit the printed parts.** Clean any brim/elephant’s foot so edges meet flush.
2. **Install heat-set inserts** (6× M3):  
   - Set a soldering iron to a temperature appropriate for your plastic (typ. **200–240 °C** for PETG; lower for PLA).  
   - Press inserts straight down to **5 mm** depth. Keep square—do not over-melt.
3. **(Optional) Install magnets** in the **magnet lid**:  
   - Dry-fit magnets into the Ø**12.5 mm** × **1.5 mm** pockets.  
   - **Mark polarity** before gluing so this lid matches your other magnet surfaces.  
   - Bond with a small drop of CA; press flush. Let cure.
4. **Mount the radio** in the case body; verify clearance for knobs, PTT, jacks, and battery latch.
5. **Fasten the lid** with M3×6–8 screws. Tighten snugly—no need to over-torque.

---

## Assembly — Cradle Case

1. **Dry fit** the cradle body and phone shelf; ensure your phone sits securely.
2. **Add grip**: apply 1–2 mm foam/rubber tape to the shelf to protect the phone and prevent sliding.
3. **Install magnets** (if used) in Ø**12.5 mm** × **1.5 mm** pockets. Keep polarity consistent with your radio backplate.
4. **Mate the cradle** to the magnetized radio backplate. Check cable clearance for your setup.

---

## Magnet Polarity Tips

- Choose a **standard**: e.g., “logo side = North.” Mark one face of all magnets before installation.
- Always **test polarity** against the mating part before gluing. Magnets are unforgiving once set.

---

## Compatibility & Remixes

- These enclosures are designed around the **KV4P open-source HT project version 2.0** geometry.
- PRs with alternate cutouts, belt-clip adapters, lanyard loops, or tripod-mount blocks are welcome.

---

## Case Types

- Phone Cradle Case - This design allows you to cradle your phone and gives you a pocket where you can place items such as your USB cable. Tested with a Google Pixel 5a phone.
- Thin Case - This is a case to fully enclose your radio while keeping the footprint as small as possible. Has built-in PTT switch that doesn't protrude.

---

## Hardware Needed

- 1.5 mm thick x 12mm diameter neodymium magnetic discs. This is needed if you want to use a magnet mount on the back of your phone. Example Part on Amazon: https://amzn.to/4mEPLiD
- M3 8mm long bolts with Button Heads - Example Part on Amazon https://amzn.to/4oXybrI
- M3x5x4.2 Heat inserts - Example Part On Amazon: https://amzn.to/41qj5kE

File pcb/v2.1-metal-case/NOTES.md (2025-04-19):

# Things to fix

v2.1a was the first version made for the metal case.  I removed some hardware, a bit too much.

## Metal Case Only:
* **DONE** Add pull-ups on the PTT switch pins, even though we don't have switches.  Means the software won't get errant PTT signals if it doesn't enable internal pull-ups.
  * I put buttons on them anyway, since we have the space on the board.  Might as well, it's all cheap parts.

* Move the SMA closer to the edge of the board.  Not enough of it sticks out the panel.

## Both Boards:
* The NeoPixel isn't lighting up, don't know why.  Yet.  Working on it.
  * **DONE** Metal Case
  * TODO Main board
  * R4, 100R, combined with C13, 2.2nF, probably rolled off the data.  Replacing R4 with 0R (like in HaliKey v2) makes it work again.
  * -3dB at 723kHz.  Yeah, that'll make a 400kHz square wave VERY round.  And an 800kHz basically gone.  It originally used 800kHz, but I dropped that to 400kHz to see if it worked.  It didn't.
  * Since removing both works in HaliKey v2, I'll do that.  Remove both R4 and C13.
  * Shoot.  The main board is this same way.  The LED on that one must be more tolerant.  I should probably fix those too.

* Put a CMCC on the USB line.  Reports from people that poorly shielded USB cables are getting RF into them and causing USB disconnects on transmit.
  * **DONE** Metal Case
  * TODO Main Board
  * https://www.we-online.com/components/products/datasheet/744232222.pdf looks like a decent part, and it's got plenty in stock.
  * We're operating at 12MHz, not 480MHz.

* Add LTCC footprint to LPF outline?
  * TODO Metal Case
  * TODO Main Board
  * Added LTCC between LPF and antenna port, with a 1206 0R to bypass it.
  * Added 0603 0R to bypass the discrete filter.
  * Documented which parts to DNP for which design.

* Add 220pF Murata tuned UHF filters.
  * TODO Metal Case
  * TODO Main Board
  * Document to DNP either VHF or UHF, depending on the build.

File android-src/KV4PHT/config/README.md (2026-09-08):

# CI debug signing key

`debug.keystore` is an intentionally public signing key used only for
PR and nightly debug APKs. Keeping this key stable lets one CI build update a
previous CI build without uninstalling the app first.

This key provides no authenticity: anyone with the repository can sign an APK
with it. Never use it for a production release, an app store upload, or any
build presented as trusted. Production signing keys must remain private.

- Store password: `android`
- Key alias: `kv4p-ci-debug`
- Key password: `android`
- SHA-256 certificate fingerprint:
  `24:5E:4C:B9:A6:AC:EA:30:C1:2F:8E:FA:11:2F:3B:64:EB:69:FD:E9:43:59:75:22:FA:24:F7:AA:FA:6E:B9:5C`

Gradle uses this key for every `debug` build, including Android Studio, PR, and
nightly builds. This shared certificate lets those builds update each other.

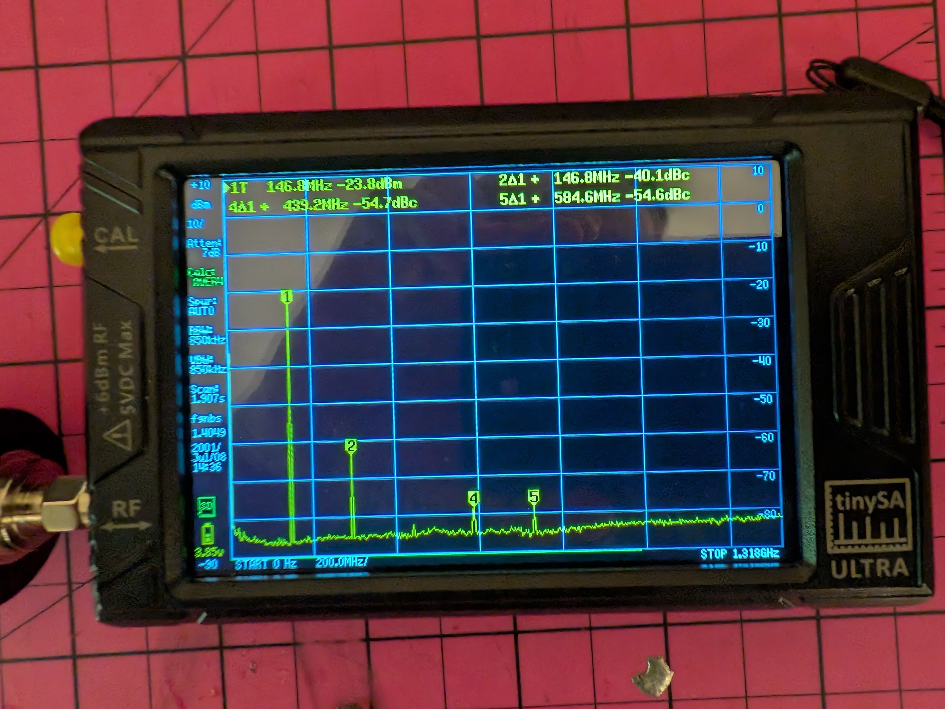
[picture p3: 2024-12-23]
website-src/img/tinysa-spurious.jpg

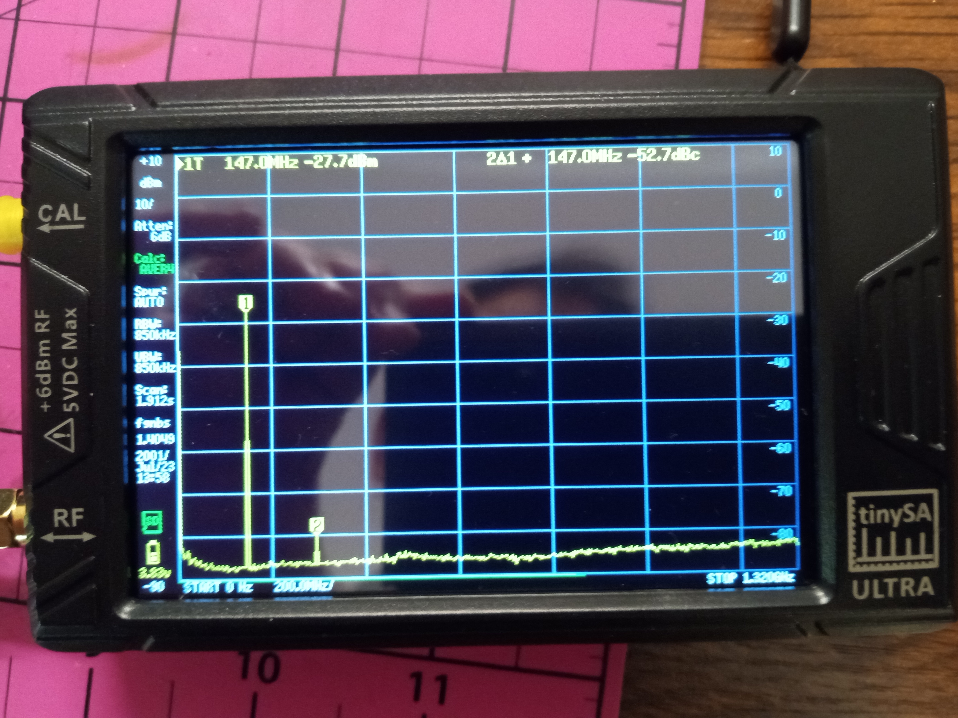
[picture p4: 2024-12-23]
website-src/img/tinysa-spurious-v1.7.jpg

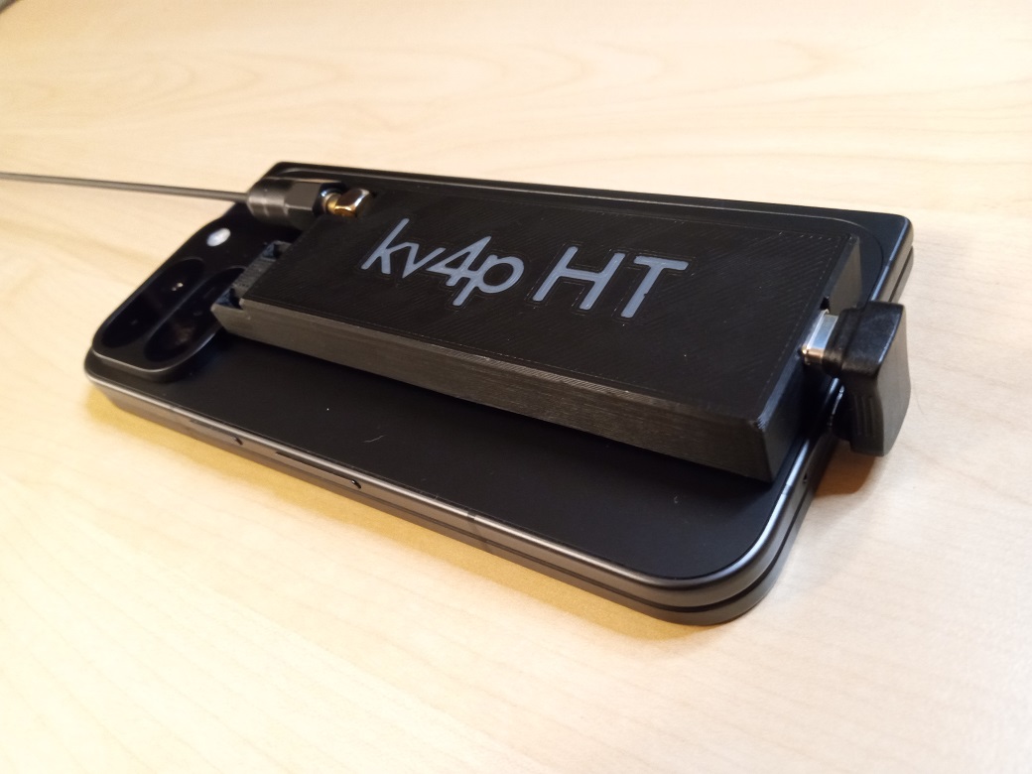
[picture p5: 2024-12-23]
website-src/img/kv4p-ht-on-desk.jpg

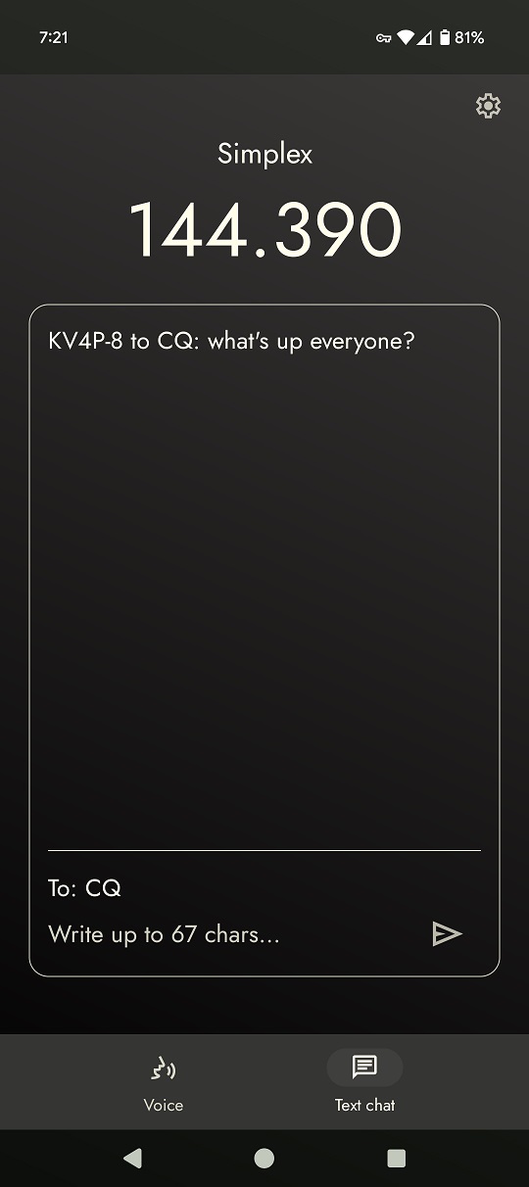
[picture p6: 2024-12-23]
website-src/img/kv4p-ht-chat.jpg

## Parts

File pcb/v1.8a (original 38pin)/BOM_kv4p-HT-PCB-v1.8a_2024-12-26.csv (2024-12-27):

ID | Name | Designator | Footprint | Quantity | Manufacturer Part | Manufacturer | Supplier | Supplier Part | Price
1 | SMA | J1 | CON-SMA-RA | 1
2 | DRA818V | U1 | DRA818V_DORJI_DRA818V | 1
3 | ESP32-WROOM-32 DEVELOPMENT BOARD | U5 | ESP32-WROOM-32 DEVELOPMENT BOARD | 1
4 | 1MΩ | R1 | R0805 | 1 | ERJ6ENF1004V | PANASONIC(松下) | LCSC | C413339 | 0.005
5 | 36pF | C3,C2 | C0603 | 2 | QCCP501Q360J1GV001T | Johanson Technology Inc. | Digi-Key | 712-QCCP501Q360J1GV001TTR-ND
6 | 20pF | C4,C1 | C0402 | 2 | GJM1555C1H200GB01D | Murata Electronics | Digi-Key | 490-8090-2-ND
7 | 62nH | L3,L1 | L1608 | 2 | HBWS1608-62NJ | Max Echo | Digi-Key | 5262-HBWS1608-62NJTR-ND
8 | 68nH | L2 | L1608 | 1 | HBWS1608-68NJ | Max Echo | Digi-Key | 5262-HBWS1608-68NJTR-ND

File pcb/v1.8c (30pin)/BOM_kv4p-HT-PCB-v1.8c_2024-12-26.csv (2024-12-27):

ID | Name | Designator | Footprint | Quantity | Manufacturer Part | Manufacturer | Supplier | Supplier Part | Price
1 | SMA | J1 | CON-SMA-RA | 1
2 | DRA818V | U1 | DRA818V_DORJI_DRA818V | 1
3 | 1MΩ | R1 | R0805 | 1 | ERJ6ENF1004V | PANASONIC(松下) | LCSC | C413339 | 0.005
4 | 36pF | C3,C2 | C0603 | 2 | QCCP501Q360J1GV001T | Johanson Technology Inc. | Digi-Key | 712-QCCP501Q360J1GV001TTR-ND
5 | 20pF | C4,C1 | C0402 | 2 | GJM1555C1H200GB01D | Murata Electronics | Digi-Key | 490-8090-2-ND
6 | 62nH | L3,L1 | L1608 | 2 | HBWS1608-62NJ | Max Echo | Digi-Key | 5262-HBWS1608-62NJTR-ND
7 | 68nH | L2 | L1608 | 1 | HBWS1608-68NJ | Max Echo | Digi-Key | 5262-HBWS1608-68NJTR-ND
8 | ESP_WROOM_32_30PIN | U2 | ESP32-WROOM-32-30PIN | 1

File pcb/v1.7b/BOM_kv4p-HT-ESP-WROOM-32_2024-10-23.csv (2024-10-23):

ID | Name | Designator | Footprint | Quantity | Manufacturer Part | Manufacturer | Supplier | Supplier Part | Price
1 | 24pF | C1,C4 | C0603 | 2 | 0603CG240J500NT | FH(风华) | LCSC | C1654 | 0.004
2 | 75nH | L1,L3 | L0402 | 2 | MLG1005S75NJT000 | TDK | LCSC | C880710 | 0.008
3 | 82nH | L2 | L0603 | 1 | SDCL1608C82NJTDF | Sunlord(顺络) | LCSC | C23473 | 0.009
4 | 43pF | C2,C3 | C0402 | 2 | GJM1555C1H430FB01D | muRata(村田) | LCSC | C415393 | 0.024
5 | SMA | J1 | CON-SMA-RA | 1
6 | DRA818V | U1 | DRA818V_DORJI_DRA818V | 1
7 | ESP32-WROOM-32 DEVELOPMENT BOARD | U5 | ESP32-WROOM-32 DEVELOPMENT BOARD | 1
8 | 1MΩ | R1 | R0805 | 1 | ERJ6ENF1004V | PANASONIC(松下) | LCSC | C413339 | 0.005

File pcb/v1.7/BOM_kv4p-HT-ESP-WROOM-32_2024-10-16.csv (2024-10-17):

ID | Name | Designator | Footprint | Quantity | Manufacturer Part | Manufacturer | Supplier | Supplier Part | Price
1 | 47pF | C1,C4 | C0603 | 2 | C1608NP0470JGTS | DARFON(达方) | LCSC | C725574 | 0.115
2 | 24pF | C5,C6 | C0402 | 2 | C1005NP0240JGTS | DARFON(达方) | LCSC | C147433 | 0.005
3 | 75nH | L1,L3 | IND-SMD_L2.9-W2.5 | 2 | HEC1008-75NJ-T | EMTEK(兆欣) | LCSC | C251931 | 0.104
4 | 82nH | L2 | IND-SMD_L2.9-W2.8 | 1 | FEC1008CP-82NG-LRH | PSA(信昌电陶) | LCSC | C346434 | 0.061
5 | SMA | J1 | CON-SMA-RA | 1
6 | DRA818V | U1 | DRA818V_DORJI_DRA818V | 1
7 | ESP32-WROOM-32 DEVELOPMENT BOARD | U5 | ESP32-WROOM-32 DEVELOPMENT BOARD | 1
8 | 1MΩ | R1 | R0805 | 1 | ERJ6ENF1004V | PANASONIC(松下) | LCSC | C413339 | 0.005

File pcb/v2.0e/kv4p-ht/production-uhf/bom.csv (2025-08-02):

Designator | Footprint | Quantity | Value | LCSC Part #
C10, C17, C9 | 0603 | 3 | 1uF | C15849
C11, C18, C7 | 0603 | 3 | 100nF | C14663
C13, C26, C28, C30, C32, C33, C34, C35, C37 | 0603 | 9 | 220pF Tune UHF | C388907
C16, C2 | CP_EIA-3528-21_Kemet-B | 2 | 100uF 6.3v | C16133
C19, C20 | 0805 | 2 | 10uF | C15850
C25, C36 | 0603 | 2 | 100pF | C14858
C38 | 0603 | 1 | 22nF | C21122
D1 | LED_WS2812B-2020_PLCC4_2.0x2.0mm | 1 | SK6812-EC20 | C2909058
D3, D4 | 0603 | 2 | Red | C2286
F1, F2 | 0603 | 2 | 100mA | C369142
FB1 | 0603 | 1 | Ferrite Bead, 1A | C160982
FL1 | Filter_Mini-Circuits_FV1206 | 1 | LFCN-490+ | C3008205
J1 | SMA_Amphenol_901-143_Horizontal | 1 | Antenna | C496551
J5 | USB_C_Receptacle_HCTL_HC-TYPE-C-16P-01A | 1 | USB-C Socket | C2894897
L7 | L_CommonMode_Wurth_WE-CNSW-1206 | 1 | CMCC | C5199874
Q1, Q2 | SOT-23 | 2 | SS8050 | C2150
Q3 | SOT-23 | 1 | AO3400A | C20917
R1, R16, R21 | 0603 | 3 | 100k | C25803
R10, R11, R12, R13, R14, R2, R20, R9 | 0603 | 8 | 10k | C25804
R15, R18, R19, R3 | 0603 | 4 | 1.2k | C22765
R17, R22, R4 | 0603 | 3 | 0R | C21189
R25 | 0805 | 1 | UHF | C17477
R5 | 0603 | 1 | 100R | C22775
R7, R8 | 0603 | 2 | 5.1k | C26000
SW1, SW2 | SW-Push-SPST-Horizontal-C455252 | 2 | PTT | C455252
SW3 | SW_SPST_TL3342 | 1 | Reset | C318884
SW4 | SW_SPST_TL3342 | 1 | Program | C318884
U2 | SOT-223-3_TabPin2 | 1 | AZ1117H-3.3TRG1 | C110474
U4 | QFN-24-1EP_4x4mm_P0.5mm_EP2.6x2.6mm | 1 | CP2102N-A02-GQFN24 | C969151
U5 | ESP32-WROOM-32D | 1 | ESP32-WROOM-32E-N4 | C701341

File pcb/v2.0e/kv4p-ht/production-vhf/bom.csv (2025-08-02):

Designator | Footprint | Quantity | Value | LCSC Part #
C1 | 0402 | 1 | 18pF | C1549
C10, C17, C9 | 0603 | 3 | 1uF | C15849
C11, C18, C7 | 0603 | 3 | 100nF | C14663
C12, C14, C15, C21, C22, C23, C24, C3, C8 | 0603 | 9 | 2.2nF Tuned VHF | C2168957
C16, C2 | CP_EIA-3528-21_Kemet-B | 2 | 100uF 6.3v | C16133
C19, C20 | 0805 | 2 | 10uF | C15850
C25, C36 | 0603 | 2 | 100pF | C14858
C27 | 0402 | 1 | 2.7pF | C1561
C29 | 0402 | 1 | 13pF | C393681
C31 | 0402 | 1 | 11pF | C527000
C38 | 0603 | 1 | 22nF | C21122
C4 | 0402 | 1 | 16pF | C77590
C5 | 0402 | 1 | 10pF | C32949
C6 | 0402 | 1 | 5.1pF | C60220
D1 | LED_WS2812B-2020_PLCC4_2.0x2.0mm | 1 | SK6812-EC20 | C2909058
D3, D4 | 0603 | 2 | Red | C2286
F1, F2 | 0603 | 2 | 100mA | C369142
FB1 | 0603 | 1 | Ferrite Bead, 1A | C160982
J1 | SMA_Amphenol_901-143_Horizontal | 1 | Antenna | C496551
J5 | USB_C_Receptacle_HCTL_HC-TYPE-C-16P-01A | 1 | USB-C Socket | C2894897
L1 | 0805 | 1 | 27nH | C1330812
L2 | 0805 | 1 | 30nH | C3221803
L3 | 0805 | 1 | 43nH | C1330253
L7 | L_CommonMode_Wurth_WE-CNSW-1206 | 1 | CMCC | C5199874
Q1, Q2 | SOT-23 | 2 | SS8050 | C2150
Q3 | SOT-23 | 1 | AO3400A | C20917
R1, R16, R21 | 0603 | 3 | 100k | C25803
R10, R11, R12, R13, R14, R2, R20, R9 | 0603 | 8 | 10k | C25804
R15, R18, R19, R3 | 0603 | 4 | 1.2k | C22765
R23 | 0805 | 1 | VHF | C17477
R24 | 1206 | 1 | 0R | C17888
R5 | 0603 | 1 | 100R | C22775
R7, R8 | 0603 | 2 | 5.1k | C26000
SW1, SW2 | SW-Push-SPST-Horizontal-C455252 | 2 | PTT | C455252
SW3 | SW_SPST_TL3342 | 1 | Reset | C318884
SW4 | SW_SPST_TL3342 | 1 | Program | C318884
U2 | SOT-223-3_TabPin2 | 1 | AZ1117H-3.3TRG1 | C110474
U4 | QFN-24-1EP_4x4mm_P0.5mm_EP2.6x2.6mm | 1 | CP2102N-A02-GQFN24 | C969151
U5 | ESP32-WROOM-32D | 1 | ESP32-WROOM-32E-N4 | C701341

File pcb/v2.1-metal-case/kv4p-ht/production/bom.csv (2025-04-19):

Designator | Footprint | Quantity | Value | LCSC Part #
C10, C17, C9 | 0603 | 3 | 1uF | C15849
C11, C18, C26, C7 | 0603 | 4 | 100nF | C14663
C13, C30, C32, C33, C34, C35, C36, C37, C39 | 0603 | 9 | 220pF Tune UHF | C388907
C14, C19, C20 | 0805 | 3 | 10uF | C15850
C15, C25 | 0603 | 2 | 100pF | C14858
C16, C2, C40 | CP_EIA-3528-21_Kemet-B | 3 | 100uF 6.3v | C16133
D1 | 0603 | 1 | Red | C2286
D2 | LED_SK6805_SIDE | 1 | SK6812SIDE-4020 | C5378721
F1, F2 | 0603 | 2 | 100mA | C369142
FB1 | 0603 | 1 | Ferrite Bead, 1A | C160982
FL1 | Filter_Mini-Circuits_FV1206 | 1 | LFCN-490+ | C3008205
J1 | Conn_SMA_Close-to-board-edge | 1 | Antenna | C496551
J2 | PinHeader_2x03_P2.54mm_Vertical_SMD | 1 | SAO v.69bis | C192301
J3 | PinHeader_2x04_P2.54mm_Vertical_SMD | 1 | GPIO Header | C192300
J5 | USB_C_Receptacle_HCTL_HC-TYPE-C-16P-01A | 1 | USB-C Socket | C2894897
L7 | L_CommonMode_Wurth_WE-CNSW-1206 | 1 | CMCC | C5199874
Q1, Q2 | SOT-23 | 2 | SS8050 | C2150
Q3 | SOT-23 | 1 | AO3400A | C20917
R1, R16, R21 | 0603 | 3 | 100k | C25803
R10, R11, R13, R15, R2, R5, R9 | 0603 | 7 | 10k | C25804
R12, R14, R17 | 0603 | 3 | 0R | C21189
R18, R19, R20, R3, R6 | 0603 | 5 | 1.2k | C22765
R23 | 1206 | 1 | UHF | C17888
R7, R8 | 0603 | 2 | 5.1k | C26000
SW1, SW2 | SW-Push-SPST-Horizontal-C455252 | 2 | PTT | C455252
SW3 | SW_SPST_TL3342 | 1 | Reset | C318884
SW4 | SW_SPST_TL3342 | 1 | Program | C318884
U2 | SOT-223-3_TabPin2 | 1 | AZ1117H-3.3TRG1 | C110474
U4 | QFN-24-1EP_4x4mm_P0.5mm_EP2.6x2.6mm | 1 | CP2102N-A02-GQFN24 | C969151
U5 | ESP32-WROOM-32D | 1 | ESP32-WROOM-32E-N4 | C701341

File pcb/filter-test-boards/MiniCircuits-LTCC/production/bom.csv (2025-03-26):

Designator | Footprint | Quantity | Value | LCSC Part #
FL1 | Filter_Mini-Circuits_FV1206 | 1 | LFCN-160 | C879890
FL2 | Filter_Mini-Circuits_FV1206 | 1 | LFCN-490+ | C5333288

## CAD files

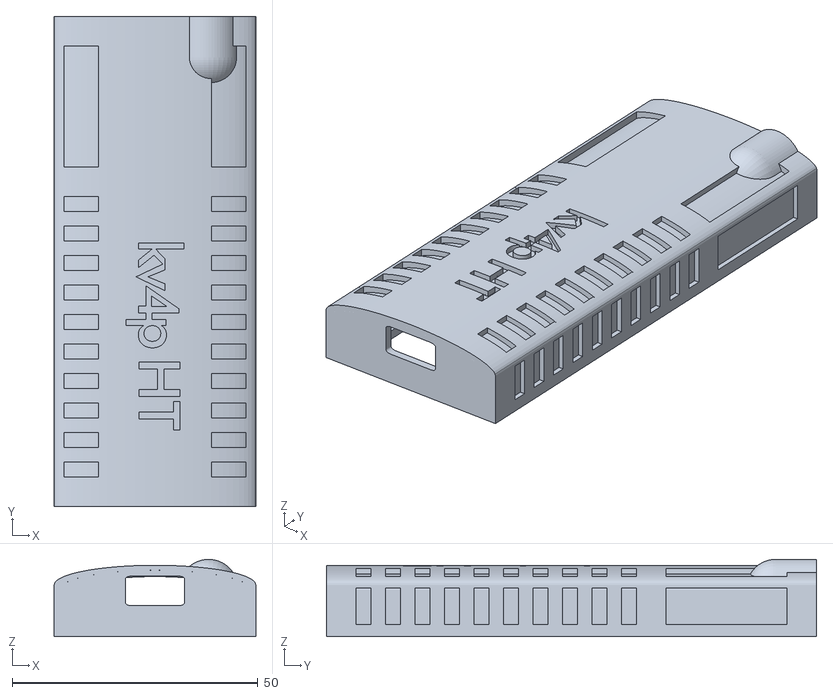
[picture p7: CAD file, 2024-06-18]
3d-print-case/Cases for 1.x PCB/alternate case designs/PCB slide-in case with stand/KV4P HT Case v1.6 - MAIN BODY.stl
41.0 x 99.6 x 15.7

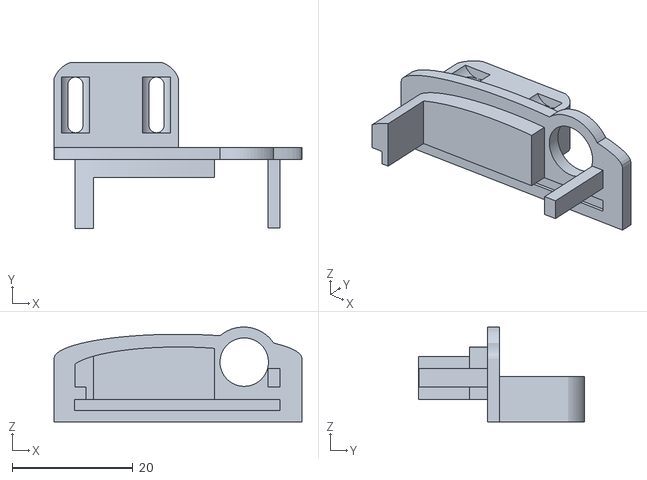
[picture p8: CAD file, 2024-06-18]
3d-print-case/Cases for 1.x PCB/alternate case designs/PCB slide-in case with stand/KV4P HT Case v1.6 - TOP.stl
41.0 x 27.4 x 15.7

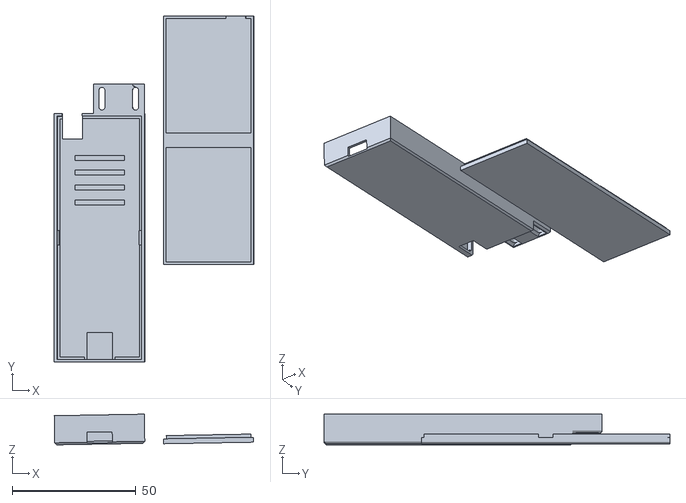
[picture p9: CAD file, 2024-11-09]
3d-print-case/Cases for 1.x PCB/alternate case designs/Quad lock case/KV4P-HT Quad Lock Add-Ons.stl
80.6 x 139.8 x 12.4

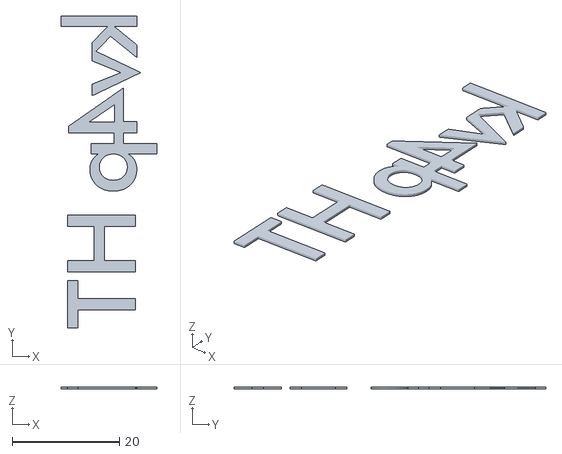
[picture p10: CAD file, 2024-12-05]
3d-print-case/Cases for 1.x PCB/alternate case designs/Sleek without USB connector holder/Sleek KV4P HT inlay.stl
18.0 x 58.3 x 0.4

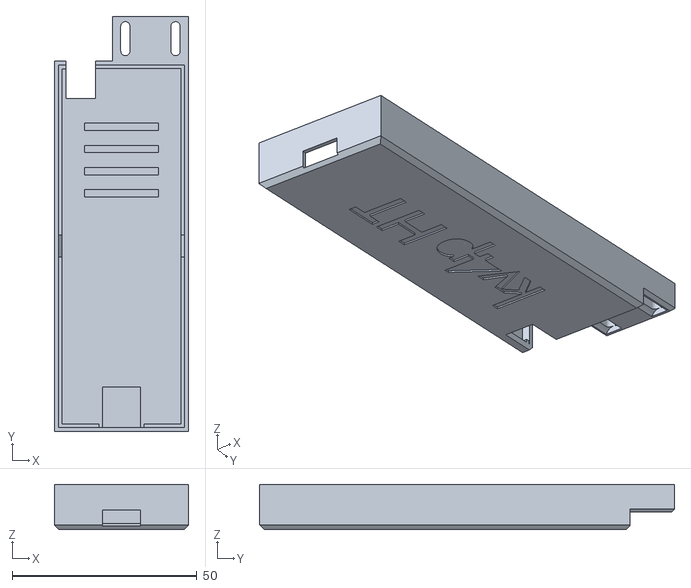
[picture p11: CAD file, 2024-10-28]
3d-print-case/Cases for 1.x PCB/alternate case designs/Thicker body (JLCPCB compliant)/KV4P HT Case Thicker Body.stl
36.4 x 112.4 x 12.2

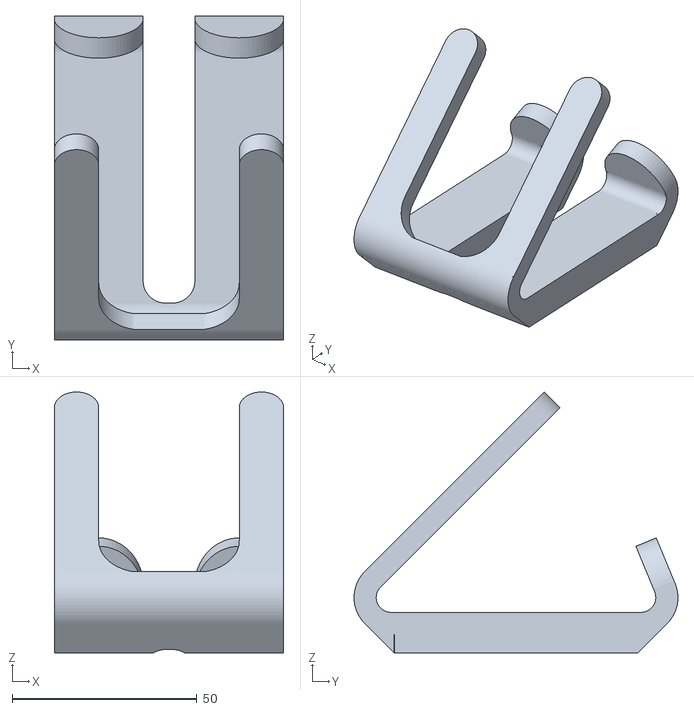
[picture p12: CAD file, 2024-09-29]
3d-print-case/Cases for 1.x PCB/Sleek KV4P HT stand.stl
62.0 x 87.6 x 70.6

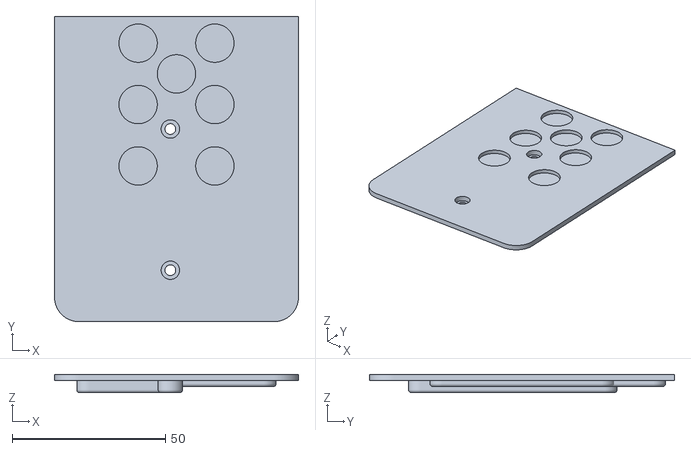
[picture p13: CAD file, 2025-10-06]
3d-print-case/Cases for 2.x PCB/Community designs/KB9VQQ Design/Phone Cradle Case/kv4p-Phone-Lid.stl
79.5 x 99.5 x 6.00

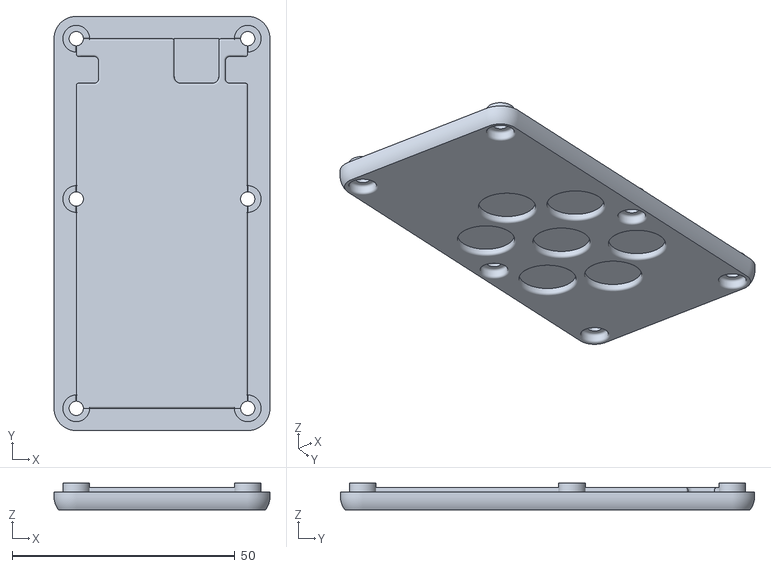
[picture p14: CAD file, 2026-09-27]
3d-print-case/Cases for 2.x PCB/Community designs/KB9VQQ Design/Thin Case/kv4p-ThinCase-Lid-Magnets.stl
48.5 x 93.0 x 6.00

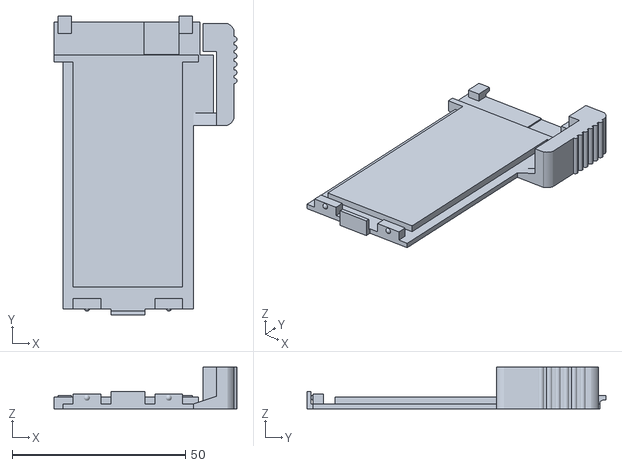
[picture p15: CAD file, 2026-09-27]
3d-print-case/Cases for 2.x PCB/Rugged (official)/Rugged KV4P HT case (for PCB 2.x) - front.stl
52.8 x 86.2 x 12.1

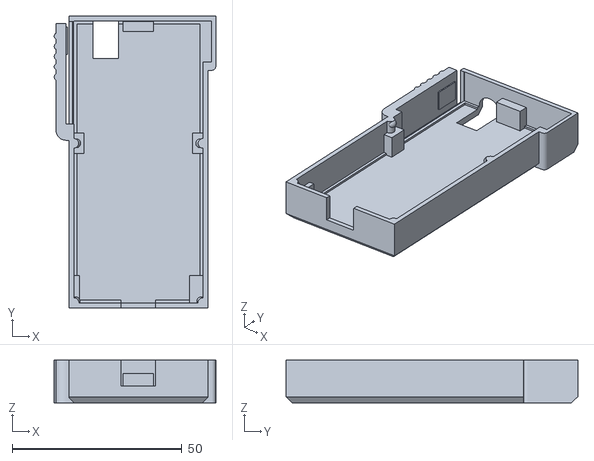
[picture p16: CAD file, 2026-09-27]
3d-print-case/Cases for 2.x PCB/Sleek (official)/Sleek KV4P HT case (for PCB 2.x) - case.stl
47.6 x 86.0 x 12.6

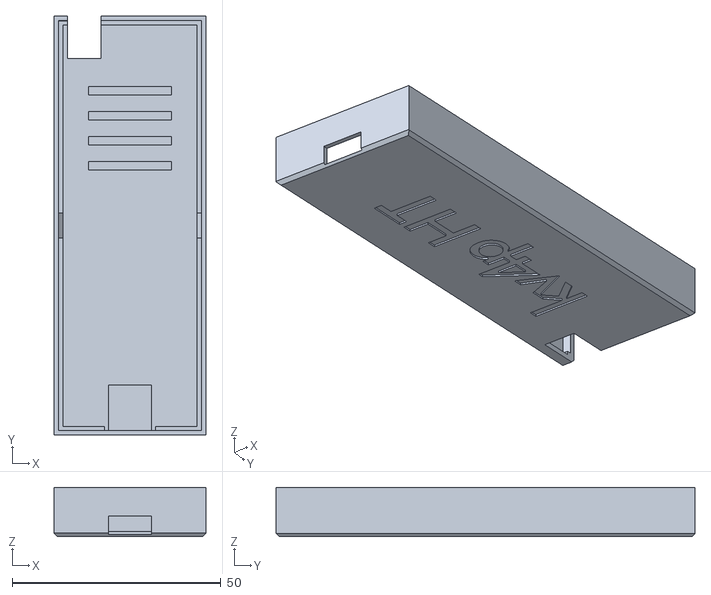
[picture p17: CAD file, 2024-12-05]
3d-print-case/Cases for 1.x PCB/alternate case designs/Sleek without USB connector holder/Sleek KV4P HT case.stl
36.4 x 100.4 x 11.8

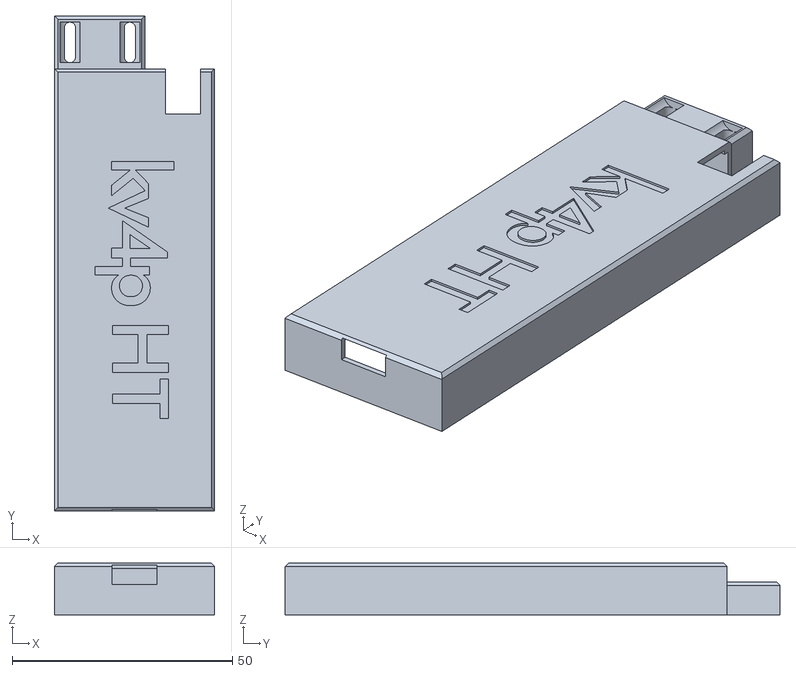
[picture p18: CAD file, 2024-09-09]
3d-print-case/Cases for 1.x PCB/Sleek KV4P HT case - BODY.stl
36.4 x 112.4 x 11.8

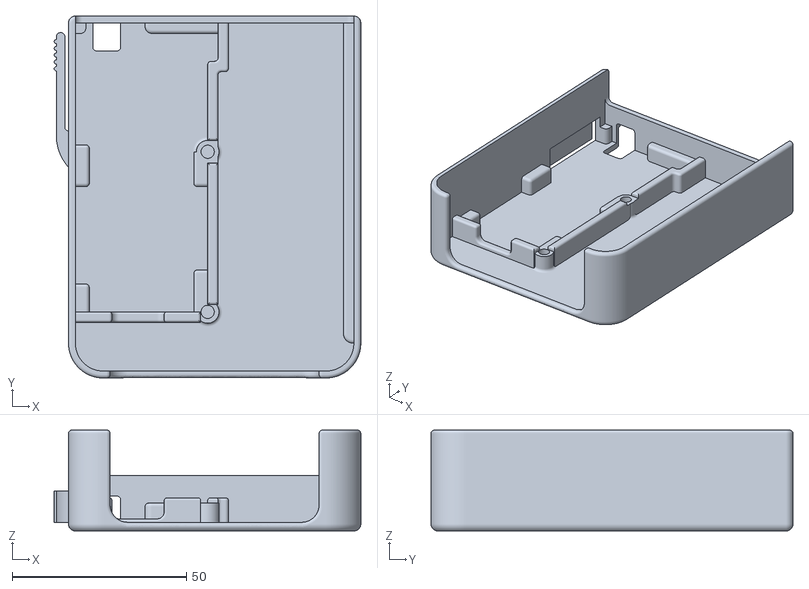
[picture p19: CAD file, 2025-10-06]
3d-print-case/Cases for 2.x PCB/Community designs/KB9VQQ Design/Phone Cradle Case/kv4p-Phone-Body.stl
88.1 x 104.0 x 29.0

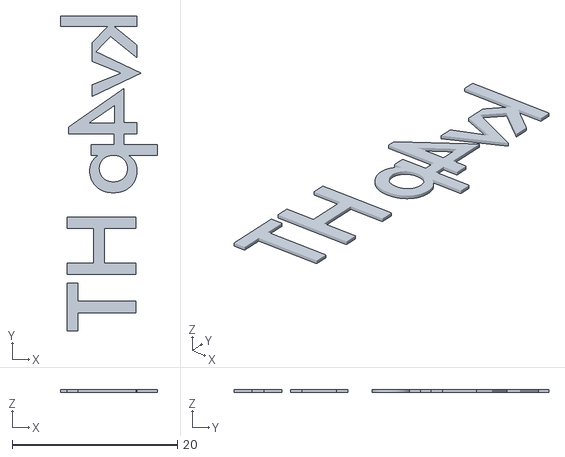
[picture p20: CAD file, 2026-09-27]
3d-print-case/Cases for 2.x PCB/Rugged (official)/Rugged KV4P HT case (for PCB 2.x) - logo inlay.stl
11.8 x 38.1 x 0.342

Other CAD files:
3d-print-case/Cases for 2.x PCB/Community designs/KB9VQQ Design/Thin Case/kv4p-ThinCase-Lid.stl
3d-print-case/Cases for 2.x PCB/Sleek (official)/Sleek KV4P HT case (for PCB 2.x) - logo inlay.stl
3d-print-case/Cases for 1.x PCB/alternate case designs/PCB slide-in case with stand/KV4P HT Stand.stl
3d-print-case/Cases for 1.x PCB/Sleek KV4P HT case - TEXT INLAY.stl
3d-print-case/Cases for 2.x PCB/Community designs/KB9VQQ Design/Thin Case/kv4p-ThinCase-Body.stl
3d-print-case/Cases for 2.x PCB/Rugged (official)/Rugged KV4P HT case (for PCB 2.x) - back.stl

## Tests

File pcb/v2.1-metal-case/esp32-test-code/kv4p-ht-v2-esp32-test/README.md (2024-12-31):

# Firmware burning automation

Requirements:

* You can build and upload code from PlatformIO to the ESP32 boards.  Both projects:
  * `pcb/KiCAD/esp32-test-code/kv4p-ht-v2-esp32-test/`
  * `microcontroller-src/`
* I think parts of `showmeconsole.ph` require a POSIX platform, specifically the `select()` call.  Unknown what this will do on a non-POSIX platform (looking at you, Windows)

## Burning firmware

### Configure the script

* Open `pcb/KiCAD/esp32-test-code/kv4p-ht-v2-esp32-test/scripts/program.sh` in your editor of choice.
  * If you use VScode, open `pcb/KiCAD/esp32-test-code/kv4p-ht-v2-esp32-test/` as a PlatformIO project.
* Update `KV4P_ROOT` to the path of the root of the [kv4p-ht git repo](https://github.com/VanceVagell/kv4p-ht) you have checked out on your system.
* You might need to update `PIO_BIN` to the path of your `platformio` executable if it can't be found with `which platformio`.

### Run the script

```bash
cd pcb/KiCAD/esp32-test-code/kv4p-ht-v2-esp32-test/scripts/
./program.sh
```

It does everything with absolute paths, so it shouldn't matter where you are when you run it.

It will:

* Find the first instance of `/dev/ttyUSB*`.  If you don't have a board plugged in yet, it retries.
* Program the test code to the ESP32.
* Go into test mode.
    * In this mode, the computer will:
        * Output from the ESP32 is shown on the screen.
        * Pressing `r<cr>` (r and Enter) will toggle RTS
        * Pressing `d<cr>` (d and Enter) will toggle DTR
        * Pressing `q<cr>` or just `<cr>` will exit test mode.
    * While in test mode, the ESP32 will:
        * Blink the "Main" LED, 500ms on, 500ms off.
        * Cycle the NeoPixel through its colors: Red, Green, Blue, dark, dark.  900ms per state (Intentionally not sync'd with the main LED.)
        * Print an approximate voltage reading of the +5v line, every 5 seconds.
        * If an SA818 is installed, it will print the RSSI every 5 seconds.
    * Pressing the different buttons will:
        * Print on the console that a button has been pressed, and which one.
        * Left PTT will light the Red LED on the NeoPixel
        * Right PTT will light the Green LED on the NeoPixel
        * Program will light the Blue LED on the NeoPixel
    * Watch for:
        * Boot up messages.
        * If an SA818 is installed, it will perform a Handshake and Group.  You'll see whether they succeed.
        * Messages when buttons are pressed.
        * A voltage reading every 5 seconds.  It should be somewhere around 5v, give or take 0.2v  (Turns out, the ADC on the ESP32 is not very linear at all!)
        * An RSSI reading every 5 seconds.
* If any tests fail:
    * Press Ctrl-C to quit `program.sh`
    * Document the failure on a post-it and stick it to the board, put the board aside.
    * Restart `program.sh` and move on to the next board.
* Assuming all tests succeed, press `<Enter>` to proceed.
* Program the production code to the ESP32.
* Go into test mode (again).
    * The computer operates the same as the test mode above, but the ESP32 behaves differently.
    * Wait 10 seconds.
    * The ESP32 watchdog timer will expire and cause a reboot.  You'll see the failure and restart messages.
    * Yes, a "ZOMG WDT EXPIRED FAIL!" is a success criteria here.  It means the new code is programmed and running.  It won't stop rebooting until both an SA818 is connected, and the Android app is running to give it commands.
* Assuming all tests succeed, press `<Enter>` to proceed.
    * It will sleep for 15 seconds before starting again, to give you a chance to remove the programmed board and reconnect a new fresh board.
* Loop around to the beginning and do it all again.

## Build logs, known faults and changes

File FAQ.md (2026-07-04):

# Q: My radio works, but when I transmit it crashes. How do I fix this?
**A:** This is almost always because RFI is getting into the USB cable or connector. If you have a dummy load, transmit into that and if it doesn't crash you've confirmed that's the problem. Here are ways people have fixed this:

  - Try a different antenna.
  - Add a ferrite bead to the USB cable.
  - Switch to a better-shielded higher-quality USB cable.
  - Reduce tx power from "High" to "Low" in settings.
# Q: The kv4p HT Android app flashed new firmware onto my radio but it still says it needs to flash the firmware. What's wrong?
**A:** Sometimes it's as simple as closing the kv4p HT app completely, unplugging the kv4p HT radio, and plugging it back in. A full reboot of everything sometimes causes the new firmware to be detected. If that doesn't work, try installing the firmware via the web-based firmware flasher tool, this almost always works:

  - Open the [Firmware page on kv4p.com](https://kv4p.com/firmware.html) in your computer's web browser (not your phone's)
  - Plug your kv4p HT into your computer's USB port
  - Follow the steps on the page

If it doesn't detect your device while trying to flash, you may need to hold down the "Reset" button on the front of your PCB as it looks for your device. You can release the button once your device is detected and flashing begins. 
# Q: Is there an iPhone version of kv4p HT?
**A:** No, and the core contributors of this project don't currently have the skillset to build one. However, several community members have expressed interest in working on this, and have started exploring what's possible. The main sticking-point (besides iOS app programming skills) is that iPhone does not allow USB devices to just work, you have to pay an expensive licensing fee, and since this is a free open source project that's not going to happen! The people looking into this are working on getting the kv4p HT device to connect via Bluetooth instead of USB. If you're interested in helping with this, please hop into contributors and share your skills!

**Update:** Some people working on it and they have a working prototype,they're updating the [firmware to use Bluetooth instead of USB](https://github.com/VanceVagell/kv4p-ht/issues/107).
# Q: When I plug my kv4p HT into my phone, none of the lights turn on and it doesn't seem to work. The kv4p HT app asks if the radio is plugged in. What gives?
**A:** This is most common with v1.x versions of kv4p HT, since the ESP32 dev boards available on the market are often missing a couple resistors that tell Android to power it (computers ignore this and just send power). The most common solutions:

* Try plugging your USB cable or adapter the other way around. OTG cables are directional, meaning one side is for the host and one is for the device (sometimes the wire or connector will actually say this on each plug).
* You might be using a USB c to USB c cable that's not an OTG cable. Try a different cable, or buy one that's known to be an OTG cable (people in [#General on Discord](https://discord.com/channels/1290074006908829746/1290074006908829749) can recommend some).
* Upgrade to a v2.x version of the PCB, which permanently fixed this issue by not using an ESP32 dev board.
# Q: I paid money for this, and I'm frustrated it doesn't work the way I expected. What's the deal?
**A:** This Discord is for the free open source version of the project, filled with thousands of people who use or contribute to kv4p HT because of their passion for ham radio, and they want to help make something cool. If you paid money for a kit or pre-built kv4p HT, it was not from this community, it was from either a company or an individual selling kits to make it easier for people to get started. 

You should first reach out to any merchant you bought it from explaining your issue, and they might be able to help or send a replacement. If that doesn't work, the community here would be happy to help figure it out too, but please be kind and be aware we're all volunteers here in this Discord, doing this for free!
# Q: APRS doesn't decode consistently, or at all. How can I improve this?
**A:** APRS works best when you disable squelch, and turn off all 3 audio filters. This ensures that the full over-the-air audio reaches the APRS decoding logic. You can turn your phone's volume down and it will still work (you don't need to listen to the static!).
# Q: How can I improve the sensitivity of my kv4p HT? It doesn't seem as good as my other radios.
**A:** You can dramatically improve the sensitivity of your radio by adding a full-length antenna (such as a 19.5" whip like the Signal Stick linked on the [KV4P site](https://kv4p.com/)). You can improve it even more by using a 3 foot (1 meter) USB cable instead of a short cable or connector. When doubled-back on itself, a 3 foot USB cable is a nicely-tuned VHF counterpoise! Personally, if I'm out-and-about and just want basic radio usage I don't bother with a big antenna or long wire. But if I'm sitting down to play around with APRS, I usually go with both and I get a ton more decodes. 
# Q: The VHF/UHF setting in the Android app disappeared, how do I get my UHF kv4p HT radio to work again?
**A:** This happened because we changed how the Android app determines if the device is VHF or UHF. Instead of configuring it manually in settings, the manufacturer of the kit or homebrew builder of the device needs to do a one-time Non-Volatile Storage (NVS) flash to the device.

This NVS tracks not just VHF/UHF but which features are on the board, such as the presence or absense of a physical PTT button, and so we can add new things in the future without the Android app getting really complicated.

You can find and install the appropriate NVS for your device at the bottom of this page, just plug your kv4p HT into your computer and use the [web flasher](https://kv4p.com/firmware.html).
# Q: The kv4p HT app can't find my radio, and I also use the RepeaterBook app, what's wrong?
**A:** The RepeaterBook app tries to access the kv4p HT radio's serial connection to your phone, and this prevents the kv4p HT app from making a connection. You might see a dialog like the attached image, when this happens. If you see this dialog, select "Cancel", which may be enough to get your kv4p HT radio to connect properly.

If not, as a temporary workaround, you may need to uninstall the RepeaterBook app to properly use your kv4p HT. We've contacted the RepeaterBook developers to alert them to this conflict, and hope to have a fix in the future.
RepeaterBook requesting access to KV4P HT

# Q: My kv4p HT won't flash and/or works inconsistently, what's wrong?
**A:** Some unknown manufacturers of kv4p HT modified the hardware design and their changes do not work properly. If your kv4p HT PCB looks like the photo attached here, you have one of these problematic units. The telltale signs are: a giant QR code with a thin plus-sign overlaid on it, and the kv4p HT logo is squished and surrounded by a thick white border. The official PCB design does not look like this.

Unfortunately, the best option is to build or buy a kv4p HT that uses the official design. You can always find the official design (and trusted kit manufacturers who are using it) onthe [KV4P site](https://kv4p.com/).

A problematic PCB

# Q: I think I have a dual band kv4p HT, why can I only use VHF or UHF and not both?
**A:** There are no dual band kv4p HTs, they are all either VHF or UHF but never both. 

Some vendors who sell the kits or pre-made units have misleading titles for their products, such as "kv4p HT VHF/UHF", which they intend to mean "you can choose either VHF or UHF when you buy it" but many people take to mean "dual band". If you don't notice the drop-down to choose the band you want, it's easy to make this mistake when ordering.

Confirm whether you have a VHF or UHF unit from the receipt of where you bought it, and ensure you have the appropriate non-volatile storage (NVS) flashed onto it, using the [web flasher](https://kv4p.com/firmware.html), so that your radio shows up on the proper band in the kv4p HT app. If you attempt to transmit on the incorrect band, you may damage your radio.

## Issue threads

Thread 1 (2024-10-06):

[PCB] Explore smaller ESP32 options

puterboy, 2024-10-06:
1. For smaller size, you might want to consider the ESP32-Devkit module which has only 30 pins vs. 38 pins on the ESP32-WROOM. I thinks it's also a little cheaper.
This should require only a trivial change to the PCB since presumably you are only using a small subset of the GPIOs anyway.

2. Even better, how about designing a board that avoids the module and just uses the ESP32-S3 chip plus the CP2102 USB chip plus/minus a couple of other passive components to make an even smaller device. The assembly would be a little harder and you might not even save on cost, but you would have a more compact/integrated board.

3. Finally, how about adding an option to the firmware to use wireless connectivity between the phone and the ESP32 using the ESP32 in AP-mode. Then you wouldn't need to use a USB connector and could place the PCB board anywhere. This could be especially useful if you want to use a larger fixed antenna.

VanceVagell, 2024-10-06:
Thanks for the ideas, puterboy! I'd welcome any PCB design contributions, as I'm very new at that and it took a lot of experimentation and learning to reach the point the project is at.

That said, I did have several earlier prototypes, which used different ESP32 modules. The smallest was Adafruit QT Py ESP32-S2, which is really rather tiny. I did get it to work, but it wasn't up to par with what I wanted the project to do -- in particular it does not have a hardware UART and the software one failed unpredictably. Also, the audio was limited to 8kHz because the processor was just too slow, and single-core. I also built an earlier version around the DORHEA ESP32 D1 Mini NodeMCU, which is a bit more compact but it doesn't have pin headers for easy soldering so it's harder for people to work with.

In terms of #3, one major goal is to keep the kv4p HT battery-less, since a major benefit is just throwing it in a bag or glove compartment or whatever and knowing that as long as your phone is charged you can use it (don't have some other battery you need to keep topped-off). That's why I didn't go with something like a Bluetooth link to the phone (also, there are other radios that have this). But again, if you're interested in contributing a variant that has those features, I'd love to include it!

One thing related to #3 I do really want to offer, is to update the Android app to allow you to pair your phone to a laptop, and use the kv4p HT as a modem so you can do whatever arbitrary amateur radio data experiments you want, like SSTV etc. I actually think this would be fairly easy.

Thanks for the ideas!

puterboy, 2024-10-07:
Here is an Amazon link to the 30 pin devkit ESP32 module
https://www.amazon.com/AITRIP-ESP-WROOM-32-Development-Microcontroller-Integrated/dp/B0CR5Y2JVD

It has the same power & functionality of the 38 pin model -- just smaller/fewer pin so it is missing a couple of the GPIOs which obviously are not needed in your project.

Adopting your project to the smaller board should be almost trivial.

Also, if you want to really cut the price suggest that people look on Aliexpress - you can get the ESP32 modules for about $3.50 . You can probably get all the parts for not much more than $10-$15 max. Shipping is free if you spend more than $10 in Choice Delivery items. Delivery times is under 2 weeks to the US.

wolrah, 2024-10-12:
> One thing related to #3 I do really want to offer, is to update the Android app to allow you to pair your phone to a laptop, and use the kv4p HT as a modem so you can do whatever arbitrary amateur radio data experiments you want, like SSTV etc. I actually think this would be fairly easy.

Would it perhaps be simpler to directly connect the unit to the laptop over USB?  As I understand it the hardware is basically operating as a SDR, so maybe a SoapySDR driver could be implemented without any changed to the microcontroller side, or alternatively maybe a "sound card SDR" mode that has the microcontroller expose a USB Audio Class device and a serial port device for control.

esev, 2024-10-12:
For #3, could the app be entirely web-based and hosted on the esp32? Then it wouldn't be tied to any one platform (Android).

thekalinga, 2024-10-14:
I have no knowledge about micro controllers & radio perse, but if not tying software portion to any platform, kotlin-multiplatform (or) flutter are two options I am aware of.

VanceVagell, 2024-10-16:
I'm updating this to focus on the smaller ESP32 recommendations. If you're interested in the other ideas, could you please file them as separate enhancement requests, one per idea? Thanks!

seanauff, 2024-10-16:
Looking at the Espressif [comparison table](https://products.espressif.com/#/product-selector?names=&filter={%22Status%22:[%22Mass%20Production%22],%22Core%22:[%22Dual%20Core%22]}), the only ESP32 variant that meets the requirements of this project is the original ESP32, assuming the requirements are:

- Dual Core
- Hardware UART
- ADC
- DAC

The ESP32-S3 has everything but the DAC, and is available in a small form factor from [Wemos](https://www.wemos.cc/en/latest/s3/s3_mini.html). Looks like there is a [workaround](https://www.atomic14.com/2024/01/05/esp32-s3-no-pins) for the lack of DAC, though it requires some more external components.

I agree it would be nice to have this in a smaller size but might not be worth it if the PCB design gets more complicated as a result.

puterboy, 2024-10-16:
The module I mentioned above, the 30-pin ESP32-Devkit is identical to the model currently being used (same ESP chip) but 8 fewer pins so about 20% smaller. Should require only very trivial changes to the PCB design since only a few GPIO pins are used anyway.

seanauff, 2024-10-16:
I just found 2 even smaller options, both with the Pico variant of the ESP32 chip. The differences look minor.

https://shop.pimoroni.com/products/tinypico-v2?variant=39285089534035

https://www.adafruit.com/product/5395

The Adafruit looks by far the smallest

puterboy, 2024-10-19:
Not sur how popular the Pico variant is.
The 30-pin devkit one I mention is very common - arguably more common than the 38 pin one that the current model uses (based on Amazon and Aliexpress purchases)

Jonty, 2024-10-20:
A quick note about Bluetooth: I don't think you need to worry about changing the hardware to support this, it's reasonable to say that the module must receive power from a USB battery bank or similar if not connected to a phone. This is purely a matter of implementing the ability to connect to the ESP32 serial interface over Bluetooth instead of USB.

Having worked with ESP32 Bluetooth serial before this should be relatively straightforward, my only concern might be if it can support a baud rate high enough for your needs!

Given you lack a screen to display a pin, I'd suggest that the way to implement this would be to automatically go into bluetooth pairing mode if there is no USB data connection and use a default pin, then turn that off once a connection has been established.

DrFrankReade, 2024-10-21:
I'll add that soldering castellated vias is a very easy thing to do with even basic soldering equipment, and you can also include thru-holes for people who want to do headers. Castellated vias allows a really shallow build and a flat back to the PCB. Nothing but your SMA sticking out the back, and even that's up for debate.  As to which ESP is better, I can't say. I just love me some castellated vias. I have no attachment to the board below.
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

SmittyHalibut, 2024-10-31:
In #63 I intend to do away with the dev boards entirely and put an ESP32 directly on the main board.

m1geo, 2024-11-02:
Finding it hard to get 38 pin ESP32 WROOM boards that fit the PCB. I've brought several including those linked on the project page, but, the ESP32 board is too narrow! 😕

I'd suggest just adding the parts to the main PCB as then whoever makes the PCB with the LPF can just make the entire thing.

SmittyHalibut, 2024-11-04:
# NOTE: Must be ESP32, NOT ESP32-[extension]

I started working on an ESP32-S3 on-board direct replacement for these dev modules and @VanceVagell correctly pointed out that it doesn't have an on-board DAC.  It appears that only the original ESP32 does.

Yes, adding an off-ship I2S CODEC is an option, but @VanceVagell has requested we not do that now.  That's something we can work on at a later date/revision.  For now, I'm going to stick to ESP32 (no extension) modules.

SmittyHalibut, 2024-11-04:
https://products.espressif.com/#/product-selector?names=&filter={%22Wi-Fi%22:[%222.4%20GHz%20802.11%20b/g/n%22,%222.4%20GHz%20802.11%20ax%22],%22Bluetooth%22:[%22BR/EDR%20+%20Bluetooth%20LE%20v4.2%22,%22Bluetooth%20LE%20v5.0%22,%22Bluetooth%20LE%20v5.0%20(v5.3%20certified)%22],%22Products%22:[%22Module%22],%22Status%22:[%22Mass%20Production%22],%22Core%22:[%22Dual%20Core%22],%22Antenna%22:[%22PCB%22,%22Solder%20pad%20for%20external%20monopole%20antenna%22]}

Looks like we have 17 options, and really only:
* ESP32-WROOM-32E with various memory/flash options
* ESP32-WROVER-E with various memory/flash options
* ESP32-MINI, ESP32-PICO, and ESP32-PICO-MINI

All previous development has been done with ESP32-WROOM, so I'll go with that.  I'll make sure not to use the PSRAM pins so any memory option remains available, and swappable/upgradable in the future.

Proceeding with https://jlcpcb.com/partdetail/EspressifSystems-ESP32_WROOM_32EN4/C701341

SmittyHalibut, 2024-11-05:
> Finding it hard to get 38 pin ESP32 WROOM boards that fit the PCB. I've brought several including those linked on the project page, but, the ESP32 board is too narrow! 😕
>
> I'd suggest just adding the parts to the main PCB as then whoever makes the PCB with the LPF can just make the entire thing.

See #63 This is done for v2.0 that I'm working on now.

I'm pretty sure the footprint for that board was ... off...

Magnum164, 2024-11-05:
So question. Can the board be split into 2 parts?

The main board simply having a connector for pin outs to a daughter pcb
holding the ESP32?

My eps32 is shy width wise for the 1.7b. I plan to simply run wires from
the pcb to a separate device board holding the  esp32.

Yea, different case but it is still just a open source project.

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

SmittyHalibut, 2024-11-09:
It can? But that's kinda what the ESP dev boards already do. Adding yet another layer of abstraction seems overkill.

VanceVagell, 2024-11-17:
Tracking this in issue #59 going forward

Closed 2024-11-17.

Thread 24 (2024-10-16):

[PCB] Improve VHF harmonic suppression

VanceVagell, 2024-10-16:
Improve the VHF filtering, I'd like the second harmonic to be even more supressed (currently it's just over -40dB, which is the minimum for part 97).

VanceVagell, 2024-10-16:
I already have a v1.6 design that is meant to fix this, should have test boards soon to confirm.

nhendin, 2024-10-16:
I've just ordered a v 1.6 PCB,  and have access to decent spectrum analyzers at work.  (Keysight portable as well as an Rohde & Schwarz FSV3 series).

What's your test setup?  I assume it's  just transmit into an appropriate attenuator (or coupler to a dummy load) and measure 2nd harmonic suppression?

I can attempt to duplicate the test that when I get my boards and parts set up (I just ordered a set of stuff from Amazon / Aliexpress / Signal Stuff) yesterday so it will be a little while.

VanceVagell, 2024-10-16:
Thanks for the offer, more testing is always welcome. I test with a TinySA spectrum analyzer, transmitting through a 30dB attenuator (the TinySA usually adds a few more dB of attenuation as it figures out the graph, something like 37dB total usually). I'm expecting the v1.6 PCBs to be delivered today and will update here after my own testing.

If you have any PCB design experience, I'd really love any help improving it overall. I suspect there are many RF-related improvements that could be made (e.g. better via stitching, impedence matched traces, etc.). I'm fairly new to PCB design.

nhendin, 2024-10-16:
What's the spec you are trying to hit for harmonic suppression?
If it's relative (like -40dBc) then the total attenuation doesn't matter as
long as the level is low enough to not cause non-linearities (e.g. more
harmonics) in the spectrum analyzer itself.
If it's an absolute spec, (e.g. less than -45 dBm) then calibration of the
attenuation might matter.

--Neil.

On Wed, Oct 16, 2024 at 10:39 AM VanceVagell ***@***.***>
wrote:

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

nhendin, 2024-10-16:
AFAIK, it looks like 47 CFR, Chapter I, subchapter  D, part 97, section 307(e) is the relevant document:

_The mean power of any spurious emission from a station transmitter or external RF power amplifier transmitting on a frequency between 30-225 MHz must be at least 60 dB below the mean power of the fundamental. For a transmitter having a mean power of 25 W or less, the mean power of any spurious emission supplied to the antenna transmission line must not exceed 25 µW and must be at least 40 dB below the mean power of the fundamental emission, but need not be reduced below the power of 10 µW. A transmitter built before April 15, 1977, or first marketed before January 1, 1978, is exempt from this requirement._

[Link](https://www.ecfr.gov/current/title-47/section-97.307)

VanceVagell, 2024-10-16:
@nhendin I just tested the v1.6 PCB design and unfortunately the 7th-order Chebyshev lowpass filter I designed is barely working at all, it's FAR worse than the v1.5 PCB design. The new filter is only around -11dB from the first harmonic which is atrocious.

Could you please take a look and see if you can help figure out what's wrong, and how to properly improve filtering?

I used this modeling tool:
https://markimicrowave.com/technical-resources/tools/lc-filter-design-tool/

Attached is a screenshot of the values for the filter I designed, and I confirmed the BOM matches these.
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

So I'm not sure why there's such a major discrepency from the model and what I'm measuring. Could it be something about the actual component layout, e.g. the inductors too close together or something? Seems unlikely...

nhendin, 2024-10-16:
I'd have to take a look at the layout.  Do you have access to a network analyzer?  We could measure the filter frequency response by itself -- I don't have my boards yet.

nhendin, 2024-10-16:
Not having the board, the things I could think are possible, are coupling across the PCB that is bypassing the filter, parasitcs from the PCB changing the values, though the caps are large enough that I would not think that was a  factor.

A VNA measurement of just the filter response would be really interesting.

kiavash-at-home, 2024-10-18:
The frequency of the 7th order harmonic is high enough that the parasitic capacitance of the inductors may start to impact the response. It is possible to simulate the design including these parasitic values and compare with the measurements.

SmittyHalibut, 2024-10-23:
I'm looking at this a bit today.  I used Elsie to model the filter in https://github.com/VanceVagell/kv4p-ht/pull/50 (which are the same values as in https://github.com/VanceVagell/kv4p-ht/issues/24#issuecomment-2417839814).

The other thing to note is that the attenuation at the harmonic in the filter is ON TOP OF the attenuation in the transmitter itself.  So even if the filter is only -30dB, if the harmonic coming out of the radio is -35dBc, that's -65dBc total.

I have simulated a better filter in Elsie, but let me pick some actual Murata components, download their s2p files, and simulate the Real filter in Qucs.  (I really should be working right now, but this is way more fun.)

SmittyHalibut, 2024-10-23:
Simulation:
* Cap input lowpass
* Chebyshev
* Cutoff: 150MHz
* 7 order
* 50ohm term
* Passband ripple: 0.1dB

Perfect values:
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

Real values:
* C1, C4: 24pF, GQM1875C2E240GB12D C2336887
* C2, C3: 43pF, GQM1875C2E430GB12D C2336730
* L1, L3: 75nH, LQW18AN75NG8Z C2042760
* L2: 83nH, LQW18AN83NG80D C2050394

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

Not quite as good as the exact values, but not terrible. SWR is below 1.2 for the pass band, and the 2nd harmonic is down 53dB or more.  That's pretty good.

SmittyHalibut, 2024-10-23:
Qucs, using the S2P files from Murata for those very components.  This isn't NEARLY as pretty as "perfect" components.  Go figure...

Schematic:
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

Simulation:
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

SmittyHalibut, 2024-10-23:
For component selection: https://ds.murata.co.jp/simsurfing/mlcc.html?lcid=en-us&jis=false

You can pick components from their parameters, then see their |Z| and R+jX graphs right on the web page to pick components that are self resonant at useful frequencies, like picking decoupling capacitors that resonate (lowest impedance) at specific values you want to remove from power.

You can also download S2P files for components for use when simulating filters.  If you use Qucs, go to File Components and put 2-Port components into your schematic and point it at the S2P file you downloaded for that component.  Make sure you ground the "third" pin of your 2-port device (the one sticking out the bottom; see above for an example.)

In this way, you can iterate on the design until you optimize the parameters you care about and get as close to a perfect filter as possible.

kiavash-at-home, 2024-10-23:
Excellent amount of RF investigation, both in this post and #50. I totally and fully agree with improvements suggested at https://github.com/VanceVagell/kv4p-ht/pull/50#issuecomment-2433150162 .

> Qucs, using the S2P files from Murata for those very components. This isn't NEARLY as pretty as "perfect" components. Go figure...

The lower inband S21 is caused by the Q of the inductors. Instead of using downloaded S-paramets, I used QUCS with SRF/Q data from the datasheet and got very similar results as yours with S2P files. Especially, the inductors used in v1.6 boards have SRF=1GHz which impact the filter response in higher frequency (7th harmonic issue). As @SmittyHalibut recommended, this LPF filter needs high quality LC components (Murata/Coilcraft come to my mind) or an RF ceramic filter. Low Quality (pun intended) inductors won't cut it at the higher frequency.

SmittyHalibut, 2024-10-23:
Coilcraft are fantastic parts, but somewhat awkward values.  If there are Coilcraft parts at the values we need, I recommend those over the Murata equivalents where possible.

Though, not sure what JLCPCB has for Coilcraft.

VanceVagell, 2024-10-24:
Resolving this bug because commit a49a82e8b16274b702f880dea71af087a66782ba addresses this issue for the immediate need of new users. Here are the harmonic suppression results of v1.7 (which should also apply to v1.7b which has same layout, but more readily available components):

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

More substantial updates to future-proof the PCB design are being worked on in issue #50 by community members with professional electronics engineering experience.

SmittyHalibut, 2024-10-31:
Even though you've closed the ticket, I'm still planning to use my design above (which isn't much different than your design) in the 2.0 board.

Closed 2024-10-24.

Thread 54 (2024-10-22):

[PCB] Add extra LED(s)

VegaDeftwing, 2024-10-22:
Copied from discord

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

VegaDeftwing, 2024-10-23:
This may relate to #1 to be sure that the pins are still accessible on other boards.

SmittyHalibut, 2024-10-26:
I'll add this in the work I'm doing.  See #63

Bakermonitor1932, 2024-10-27:
RGB smd mount and header pin breakout for relocating to another location with strip light or a discrete version.

SmittyHalibut, 2024-10-28:
Fun Fact:  All the Neopixel style RGB LEDs are spec'd for 5v power, even if they're 3.3v tolerant on the data line.

I have used WS2812s successfully on 3x AAA batteries, even after the batteries sag, so probably closer to 3.7 to 4v.

I'll put a WS2812 on this board to test how well it does.  I'll also jumper it so it can be powered from the Vin on the ESP32, but Vin is only available on one of the two ESP32 variants (the other one, Vin is one of the pins hanging off the bottom of the board.)

I'll also put a normal 0805 diode outline on the data pin so if the WS2812 doesn't work out, we can easily swap it out for a single color LED.

SmittyHalibut, 2024-10-31:
I'm doing away with the dev boards, and putting USB-C directly on our board.  See #63

This means we'll definitely have access to 5v, which makes this a lot easier.

SmittyHalibut, 2024-11-09:
This is done in #86.

Closed 2024-11-26.

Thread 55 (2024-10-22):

[PCB] Bring out spare GPIO

VegaDeftwing, 2024-10-22:
Bringing out some of the unused GPIO - especially a pair of I2C lines - would be great for hackability so people can experiment with adding things like small OLED screens, extra buttons, etc. This probably just means bringing a trace out from the header and leaving some unpopulated holes. Maybe just steal the [SAO](https://hackaday.com/2019/03/20/introducing-the-shitty-add-on-v1-69bis-standard/) standard?

CSSvcarlson, 2024-10-22:
This may be related to #37 as well, since it may be possible to attach a second board with a LORA module via this interface.

VegaDeftwing, 2024-10-22:
This may be related to #37 as well, as you should be able to use these pins for a seperate LORA board.

VegaDeftwing, 2024-10-22:
This also may need to spawn a new issue to add a method of sending arbitrary commands to the pins that are brought out. I don't know what support in the app would look like for this. Most likely anybody wanting anything beyond a simple glowing light on these pins would have to maintain their own fork, but that sounds reasonable to me.

VegaDeftwing, 2024-10-23:
This may relate to #1 to be sure that the pins are still accessible on other boards.

VegaDeftwing, 2024-10-28:
Yeah, this looks like a good solution to make it much more hackable. I still would've liked to see a [SAO](https://hackaday.com/2019/03/20/introducing-the-shitty-add-on-v1-69bis-standard/) header, as I think it would be fun but it looks like the board is pretty packed already now.

VegaDeftwing, 2024-10-29:
Being handled in #63

SmittyHalibut, 2024-10-31:
This is becoming more relevant as I'm planning to do away with the dev boards and put an ESP32 directly on the board.  I'll bring out unused pins to headers, and also make an SAO header.

SmittyHalibut, 2024-11-08:
Done in #86.  Resolve please (it won't let me.)

Closed 2024-11-09.

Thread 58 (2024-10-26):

Case not 3D Printable by JLC3DP

m1geo, 2024-10-26:
As I was having a batch of PCBs made for my radio club, I figured I'd get JLCPCB 3DP to SLA print nice cases. However, they are unable to print the cases.

I know this isn't the intended use case, but thought others may try and so it may be worth collating their feedback.

Below is the JLCPCB 3DP email reply:

[QUOTE]

Hello,

Hope this email finds you well.

Sorry to bother you, but there are some details that we need to confirm with you about your 3D printing order before proceeding.

1, As shown below, several separate shells are detected in your file, sorry to tell you that each file can only support 1 shell (1 model) print.

The different shells are shown in Green color. Please kindly unify all the separate shells into one shell.

Sorry for the inconvenience, but please advice, shall we activate the replace file button or you can cancel it?

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

2, The wall thickness of the indicated red area is not enough which has a high risk of deformation, crack and loss, could you please kindly increase it to be at least 0.8mm to proceed? 1.5mm will be much better for the final print.

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

3, The depth of the texts are not enough, which could not be fully printed out and the texts could be very blurry.

Could you please kindly increase the depth of the texts to be more than 0.8mm to get a better print?

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

Your early reply will be highly appreciated !

Best Regards

JLC3DP Team

[END QUOTE]

Cheers for a cool project!
George M1GEO.

Magnum164, 2024-10-26:
I volunteered with ASME on the 3D printing standard a few years back and a
lot of these comments are not uncommon.

For #1 the shells, they appear to be drawn in the CAD software as separate
objects and should be extruded and joined together. generally that is not
an issue but it is a reject for most certified 3D printing mfg sites. It
does indicate there is a gap between the solids.

#2 Really is picky and impacts design intent. With a .4mm nozzle .2mm is
not uncommon for a single slice. Not sure what the thickness is as I had my
friend print the case and can't find where I hid it right now. Their
concern may be it curling on them during printing and the cost of remakes,
which again goes to the machines they have, not the design and they should
have clarified that.

#3 again, you can respond that it has been printed fine, I did not see any
issues with the printed text on the ones we made.

It's been a long time since I was a Technical  Drawing Checker, But I have
no idea what the Concentricity Datum they have shown means on a flat
surface. Generally that surface since it is on the bed of the machine would
simply be Datum A. I would have to ask my experts if I am missing something
there.  https://www.gdandtbasics.com/concentricity/

If there are native files though for Fusion 360 they can easily be fixed.
For me I am ordering a new machine next week or I would offer to print and
send one to you.

Randy KB4CQ

On Fri, Oct 25, 2024 at 9:37 PM Dr. George Smart ***@***.***>
wrote:

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

Magnum164, 2024-10-27:
Have you contacted JLCP on this? As an update someone else has recently ordered the case and if approved by JCL would give a better understanding if this is just a new person who doesn't understand, or they truly do have an issue.

But so far have not heard any issues ordering the case, have you tried PCBway? I can print my own cases, but I just placed an order for giggles and they approved the STL file.

Magnum164, 2024-10-28:
I made a new version of the case and uploaded. It provides a thicker top that is 1.6mm and deeper text that is about .8mm, which is what the requirements for JCLP needs. So hopefully once it is approved you can submit the new case.

VanceVagell, 2024-10-28:
Should be fixed by PR #65

d3m3vilurr, 2024-10-30:
I try to order a case to JLC.
- stl is https://www.thingiverse.com/thing:6813368 and i pretty sure it could be same as pr version.

sadly, they are still rejected.

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

d3m3vilurr, 2024-10-30:
I agree. contribution is not free.

If you can provide a fixed design file to me, I'll volunteer testing & ordering to JLC

I also have 3d printing experience long time ago, I can't understand why commercial printing service doesn't accept it.
so.. I have a plan to buy new 3d print as soon as possible.
imo, this would be better solution in current time that multiple HAMs design multiple good cases :)

73
SU, DS1UFX

Magnum164, 2024-10-30:
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

Yea, I was involved in the Commercial Standards for 3D printing, which helped create these checking tools. had these designs gone through a traditional Drawing review cycle (Model Based Definition Requirement) they would have been rejected as well. I just didn;t think I needed to go that far into checking on a standard non-commercial file where no stress and you are not worried about it bringing an airplane down.

Can you do me a flavor? Can you create a new PR report with this new info so we can track that?

d3m3vilurr, 2024-10-30:
> Can you do me a flavor? Can you create a new PR report with this new info so we can track that?

I just ordered default SLA option and usually just use PLA filaments.(no flavor? :p)
anyway I made a new issue for this #67

thank you for supporting!

Closed 2024-10-28.

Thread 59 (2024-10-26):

[PCB] Design several variants of PCB for different size ESP32-WROOM dev boards

VanceVagell, 2024-10-26:
Some are 30-pin, some are 38-pin, and even within those there are narrow and wider widths.

It would be good to have 3 or 4 variants of the PCB that support all of these (with an associated list of known ESP32 vendors each one supports). Amazon has started selling out of the original ESP32 dev kit we've been using, so we need to offer some options.

SmittyHalibut, 2024-10-26:
Post links to the pinouts of the modules you want to support.

VanceVagell, 2024-10-26:
Here are the modules we should probably support, for ease of building / giving people options:

1. https://www.amazon.com/gp/product/B0CDRLLTHD (this is the existing one used in the PCB design, including it for completeness)
2. https://www.amazon.com/dp/B0CNYK7WT2 (this is very similar to above, but slightly narrower. I measure 25.6mm from center of pin on left to center of pin on right)
3. https://www.amazon.com/AITRIP-ESP-WROOM-32-Development-Microcontroller-Integrated/dp/B0CR5Y2JVD (this one is a 30 pin variant, instead of 38 pin -- the PCB for this can be shorter and this might even be the new preferred mcu because of that)

The pinout for 1 and 2 are identical.
I've attached an image of what I believe is the correct pinout for 3, although I can't be 100% sure. It has same chip layout.
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

VanceVagell, 2024-10-26:
I edited my prior comment, the space between the pins on the 2nd ESP32 module is actually 23mm from center of pin to center of pin (I just re-measured).

SmittyHalibut, 2024-10-26:
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
Looks like the first one isn't available anymore?  I suppose that's why you also include the second one.  :-)

SmittyHalibut, 2024-10-26:
>  I've attached an image of what I believe is the correct pinout for 3, although I can't be 100% sure. It has same chip layout.

It matches the silkscreen in the pictures on the Amazon product page, so I'm going with it.

SmittyHalibut, 2024-10-26:
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

That's the pinout of the other two modules.  Now we have both outlines to match up.  On it.

SmittyHalibut, 2024-10-26:
This isn't going to work, not with a single board.  It'll take multiple variants of the board to make this work.

This is what a single footprint would look like with the pins in the easiest-to-route position:
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

That makes the USB-C not centered, and not at the bottom edge of the board, but the pins are as close to their counterparts as possible.

This one, they're all centered, but the pins are WAY too close to other pins that would be far too easy to solder bridge:
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

I have one more thing I want to try, but I suspect we'll have to make multiple boards.

SmittyHalibut, 2024-10-26:
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

Ok, this worked.  The bottom of the 38pin module hangs off the bottom of the board, but the 30pin module is flush.  And wiring isn't a complete disaster.

loopmasta, 2024-10-28:
Great work. But I still can't see the layout for variant 2.  https://docs.ai-thinker.com/en/esp32/boards/nodemcu_32s
38 pins, exact same pin layout, but with 22. 86mm width. Am I missing something?

SmittyHalibut, 2024-10-28:
Woop!  Thank you @loopmasta for pointing this out.  I had the spacings reversed.  The 38pin module is only 1.0" wide, 0.9" pin spacing.  The 30pin module is 1.1" wide, 1.0" pin spacing.

I have updated the outline accordingly.  Again, thank you for catching this.

SmittyHalibut, 2024-10-31:
@VanceVagell Is this ticket still relevant?  I'm intending to do away with the dev boards, and put the ESP32 module and support hardware directly on the board, on the assumption that JLCPCB is doing the board assembly.  Do you want me to make sure to ALSO support these dev boards?  Or should I just remove their outlines entirely?

SmittyHalibut, 2024-11-04:
# NOTE: Must be ESP32, NOT ESP32-[extension]

I started working on an ESP32-S3 on-board direct replacement for these dev modules and @VanceVagell correctly pointed out that it doesn't have an on-board DAC.  It appears that only the original ESP32 does.

Yes, adding an off-ship I2S CODEC is an option, but @VanceVagell has requested we not do that now.  That's something we can work on at a later date/revision.  For now, I'm going to stick to ESP32 (no extension) modules.

SmittyHalibut, 2024-11-08:
Done in #86.  Resolve please (it won't let me.)

VanceVagell, 2024-11-09:
I would like to continue supporting the 1.7 line for people who want to build it themselves. I don't think #86 adds support for these other dev board sizes, it just obsoletes them if you use the all-in-one board, right?

If so, we'll leave this open and I'd like to update 1.7 to have one or two variants for the other size dev boards of ESP32-WROOM.

SmittyHalibut, 2024-11-09:
Correct. Very good, that's reasonable.

You can see the KiCAD libraries in the new stuff for a footprint that accepts multiple different dev boards, like pictured above.

SmittyHalibut, 2024-11-19:
I'll work on a v1.7c (or would you prefer v1.8?)

roberthadow, 2024-12-22:
The proposal is "Design several variants of PCB for different size ESP32-WROOM dev boards"

I reject this proposal. Here's why.

One KV4P project design principal is that there will be a single main branch of released code.  This implies that every new PCB design supports the latest code release. Conversely, if a new PCB design includes a new hardware feature, the hardware designer must negotiate with, and get the approval of the software developer.  For now, KV4P promises backward compatitbility of code to older HW configurations.  This will not always be the case.   Eventually, users with old boards will have to stop upgrading software or see features on-screen that they cannot use.

From a user's perspective (the owner of PCB v x.x), the latest software from the Play Store will have three conditions:
*  the latest SW fully exercises my radio [full support]
*  the latest software works in my radio, but some features are not available [limited support]
*  the latest software does not work in my radio [EOL]

Different PCBs with different numbers of pin headers will inevitably require lots of switch case constructs in the code.  This will lead to lots of code that should be redacted once a particular board is EOL. When a software developer is faced with a new version, there is twice the work: developing the new feature and dumping the old code, less the code length tends to infinity.

Worse is the issue of clone boards that _**almost**_ copy the Espressif reference.  We are having enough trouble today getting 38-pin boards to work.  Some have 5.1 k ohm resistors to negotiate USB power, others don't.

The design right now implies a 38-pin ESP32 module. Is there a compelling reason to support a 30-pin module?  I can't see it.

On a related topic, there is a request to develop an IOS version.  That one I also reject.  The design rule is One Branch of Production software.  Unless there is a compile-time switch for IOS or Android, the code will be different.  That's a violation.  I understand that there are plenty of iPhones out there.  The decision was already made to support Android.

VanceVagell, 2024-12-22:
The 30 pin dev boards have the same GPIO numbering as the 38 pin boards.
The "lost" pins are redundant power and ground, so we can certainly support
30 pin with no code modifications (PCB only).

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

roberthadow, 2024-12-22:
I stand corrected that a 30-pin board would require code changes. My apologies.

I ordered 38-pin modules from Samirob as suggested by the quck_start page.  Just now I looked carefully at the photos in the AliExpress listing. I got exactly what the photo shows: between the SILABS CP2102 chip and the USB jack is one K24 device.  The photo of the 30-pin type-C module shows two devices between the SILABs CP2102 chip and the USB jack.

My assertion about the value of accomodating 30-pin boards stands.  The difference in price is pennies.  Yes, it will make for a smaller footprint.  A 30-pin board requires another Kicad project.  It will require a new case design for 3-D printing.

This is an example of scope creep that diverts us from the key mission, building a KV4P radio that works and then improving it.

SmittyHalibut, 2024-12-22:
The 30 pin and 38 pin boards are functionally equivalent in every way that matters. The code can’t even tell the difference between them. The reason to support the 30 pin dev board is to give the user options when sourcing parts. Having said that, we need to design a SINGLE variant that supports ALL the boards. There’s a ticket for that somewhere. On Dec 22, 2024, at 6:17 AM, Robert Hadow ***@***.***> wrote:
I stand corrected that a 30-pin board would require code changes. My apologies.
I ordered 38-pin modules from Samirob as suggested by the quck_start page.  Just now I looked carefully at the photos in the AliExpress listing. I got exactly what the photo shows: between the SILABS CP2102 chip and the USB jack is one K24 device.  The photo of the 30-pin type-C module shows two devices between the SILABs CP2102 chip and the USB jack.
My assertion about the value of accomodating 30-pin boards stands.  The difference in price is pennies.  Yes, it will make for a smaller footprint.  A 30-pin board requires another Kicad project.  It will require a new case design for 3-D printing.
This is an example of scope creep that diverts us from the key mission, building a KV4P radio that works and then improving it.

—Reply to this email directly, view it on GitHub, or unsubscribe.You are receiving this because you were assigned.Message ID: ***@***.***>

VanceVagell, 2025-01-26:
This is done with the v1.8x PCBs, which are now available on the Quick Start page of kv4p.com.

And Bill (N8KHN) is working on v1.9 which is a unified PCB for all ESP32 footprints, which will be cool.

Closed 2025-01-26.

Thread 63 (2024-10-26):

[PCB] Board v2.0

SmittyHalibut, 2024-10-26:
Taking notes of what else needs doing.

This is in addition to
* https://github.com/VanceVagell/kv4p-ht/issues/20 (RF best practices)
* https://github.com/VanceVagell/kv4p-ht/issues/24 (Improve harmonic suppression)
* https://github.com/VanceVagell/kv4p-ht/pull/50 (PR for the two above)
* https://github.com/VanceVagell/kv4p-ht/issues/59 (ESP32 variants)
* https://github.com/VanceVagell/kv4p-ht/issues/55 (Expose unused GPIO pins for hacking)

TODO:
* **DONE** Add physical PTT button
* **DONE** Add WS2812 for RGB indication
* **DONE** Do the DC blocking caps in pull/50
* **DONE** Add MOSFET to H/L power pin.
* **DONE** Switch to 4 layer, optimize layout.
* **DONE** GPIOs to SAO
* **DONE** Connect LED to 13 or 23.
* **DONE** Add Reset and Program buttons.
* **DONE** Add Via stitching around RF paths, and general ground stitching.
  * **DONE** +5v via stitching (inner layers)
* **DONE** Add headers for unused GPIO (optional; we've already got the SAO.)
* **DONE** Clean up silkscreen.
* ADD MORE HERE

SmittyHalibut, 2024-10-26:
Used the tuned Murata 2.2nF for the DC blocking RF cap.  It's got the lowest |Z| at 146MHz.

SmittyHalibut, 2024-10-26:
# WIP
## Schematic
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

## Board
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

Breaking for now, there's BBQ to be had.

DefProc, 2024-10-27:
What's the width of the board with the 818 module rotated? A new board size will need a revised enclosure, so it's worth specifiing this size so any other layouts can fit (as much as possible) to the same outline.

Is it worth adding some mounting holes, now there's a little more space around the ESP32? I prefer to put these on whole mm spacings in the corners. I like M3 (or M2.5) but I haven't looked at space/clearance here.

If you're adding a WS2812, make sure you add a low pass RC filter to the Din and Dout lines. These are known to be noisy from the square wave signal, and transmit data on the Dout even when it's unconnected.

The two long unconnected pads on the 818 short edge are connected to the module GND and the top shield. I'd choose to connect these to ground instead of leaving them unconnected.

Similarly, if the via array in the square under the module is for heat transfer, it will conduct heat better if the is uncovered. It also looks to be connected to module ground, and is exposed copper.

SmittyHalibut, 2024-10-27:
@DefProc:
It is not the same dimension, I'll get you new dimensions in a bit.

Mounting holes: Ooo, good idea.  I'll see what I can fit in there.  Might need to be M2.5 or M2. It's still pretty tight.

RC Filter on WS2812: Good call, will do.

I know those pads are connected to shield on the SA868 (I've measured them), but the documentation doesn't say this.  Is it safe to assume that they are on ALL of the variants of this module?  This question stands for both the two skinny ones at the end, and the heat sink.

bseidenberg, 2024-10-28:
I have a DRA818 off of EBay at home that arrived yesterday - I can try to do a continuity test tonight, otherwise tomorrow night.

SmittyHalibut, 2024-10-28:
https://github.com/VanceVagell/kv4p-ht/issues/55  I'd argue that the alternate footprint for the two different ESP32 modules accomplishes this (bringing out unused GPIO to headers for hacking.)

VanceVagell, 2024-10-29:
A few (mainly silkscreen) feedback items here:
https://docs.google.com/presentation/d/11wXF1arb39-JXauc_9uMlvpnXMmWPpcHpaZTU2xlOMI/edit?usp=sharing

bseidenberg, 2024-10-29:
> I have a DRA818 off of EBay at home that arrived yesterday - I can try to do a continuity test tonight, otherwise tomorrow night.

I can confirm that the continuity meter says there is "BEEEEP" between the pad on the bottom, the case, pins 9 and 10, plus a few other pins.

adoeller, 2024-10-29:
Are PTT buttons to the side the right design, if the pcb is smaller than the phone and connected to it via a hard u-shaped adapter?

SmittyHalibut, 2024-10-29:
That’s a question for Vance. I’m just implementing a request. On Oct 29, 2024, at 3:14 AM, adoeller ***@***.***> wrote:
Are PTT buttons to the side the right design, if the pcb is smaller than the phone and connected to it via a hard u-shaped adapter?

—Reply to this email directly, view it on GitHub, or unsubscribe.You are receiving this because you authored the thread.Message ID: ***@***.***>

SmittyHalibut, 2024-10-30:
I've pushed my CURRENT changes to my Fork: https://github.com/VanceVagell/kv4p-ht/commit/c2e4d8ef30743d2d082a17083104f3358ebfe66d

Paging @Magnum164 ^^

The board is likely to stay roughly the same size, and the sticky-uppy bits (apologies to Sam Collins) will be in roughly the same locations, though I reserve the right to adjust things if necessary.  In fact, I'm nearly 100% sure the SAO header (currently lower right corner) will move, and likely no longer be sideways like that.  Everything else will be roughly where it is now.

After talking with @VanceVagell, my intention is to go all the way with this redesign:
* 4 layer board.  (It's not much more expensive, and will clean up the layout A WHOLE LOT)
* All 0603 components.  If we aren't assembling by hand, there's no reason not to go small.
* Probably do away with the separate ESP32 modules, and just have JLCPCB assemble an ESP32 directly to the board, with all the support hardware: Vreg, USB interface, etc.

Given all those changes, this is likely to be become 2.0 instead of 1.9.

Having said that, I'm on the road for the rest of this week and weekend.  I'll be "back at work" on Monday, November 4th, and intend to work on this then.  So don't expect a lot of progress between now and Nov 4.

puterboy, 2024-11-01:
I think it would still be nice to allow hand assembly... 805's are not that much bigger...

SmittyHalibut, 2024-11-01:
@VanceVagell This is the ESP32 I'm planning to use, unless you tell me otherwise:

https://wmsc.lcsc.com/wmsc/upload/file/pdf/v2/lcsc/2310071156_Espressif-Systems-ESP32-S3-WROOM-1-N4_C2913197.pdf

gx1400, 2024-11-04:
the SAO is a silly addition, bravo

i like the edge mount SMA as well

SmittyHalibut, 2024-11-04:
# NOTE: Must be ESP32, NOT ESP32-[extension]

I started working on an ESP32-S3 on-board direct replacement for these dev modules and @VanceVagell correctly pointed out that it doesn't have an on-board DAC.  It appears that only the original ESP32 does.

Yes, adding an off-ship I2S CODEC is an option, but @VanceVagell has requested we not do that now.  That's something we can work on at a later date/revision.  For now, I'm going to stick to ESP32 (no extension) modules.

SmittyHalibut, 2024-11-05:
Work in progress.  The schematic is pretty much done, except for the extra headers for hacking (#55).  Started work on the board, but have to break for the evening.  I suspect the board layout will keep me occupied tomorrow... *sigh*

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

SmittyHalibut, 2024-11-05:
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

Not ready to order boards just yet, but getting a lot closer.

SmittyHalibut, 2024-11-05:
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

SmittyHalibut, 2024-11-05:
Updated the original post with new **DONE** and Todo items.

SmittyHalibut, 2024-11-05:
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

This morning's progress:
* Added Reset and Program buttons
* Added Power LED, and GPIO2 LED (from the dev board modules, just for feature parity.)
* Added a GPIO header that exposes all unused GPIOs, and also the NeoPixel Data output, with +5 and Ground surrounding it.  So the top-left three pins of the 2x4 header is: +5, Data Out, Gnd, which is a common pinout for NeoPixel strips.

Still a fair bit of cleanup work to do.

gx1400, 2024-11-05:
@SmittyHalibut could putting the PTT buttons right next to the RF transmission line and RF connector possibly result in some coupling?

SmittyHalibut, 2024-11-05:
Yes.  HOwever, note that they have decoupling caps immediately next to them.  Those are the 2.2nF Murata caps with a self resonant frequency of 145MHz, with a |Z| of below 0.05ohm.  ie: They're optimized to decouple the 2m ham band.  The whole thing will look like ground to 145MHz RF.

Spoiler: The 220pF version of the same line of caps is resonant at 436MHz, 0.1ohm.  :-)

Reference: https://ds.murata.co.jp/simsurfing/mlcc.html?lcid=en-us&jis=false   Search for GCM1885C1H222, click Frequency Characteristic, and look at the |Z| graph.
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

And GCM1885C1H221:
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

SmittyHalibut, 2024-11-05:
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

Something I'm willing to put a "v2.0a" on.

SmittyHalibut, 2024-11-05:
> A few (mainly silkscreen) feedback items here: https://docs.google.com/presentation/d/11wXF1arb39-JXauc_9uMlvpnXMmWPpcHpaZTU2xlOMI/edit?usp=sharing

The only one that's still relevant is the "RF GOES HERE" comment.  Do you want me to remove it?  Same question for the "Write your secrets here" text under the 818 module.  Yes, they're just for the chuckle.

SmittyHalibut, 2024-11-06:
When ordering 5 boards, with only one part not available:
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

So we're still around $20 per board, including the ESP32, NOT including the 818, SMA, or case.

SmittyHalibut, 2024-11-06:
Option: Add tabs for a non-USB-C power source.

SmittyHalibut, 2024-11-06:
Updated issue title to be more representative of what I'm actually doing.

SmittyHalibut, 2024-11-06:
Feedback from @trainman419 after design review:
* **DONE** Add Test points.
* **DONE** Move the 2812 bypass 0R to skip the second filter.
* **DONE** Length match on USB
* **DONE** Rotate bypass cap between Vreg and ESP32.

SmittyHalibut, 2024-11-08:
PR: #86 accepted.
#88 is where any future work will be done.  Resolving this ticket.

Closed 2024-11-08.

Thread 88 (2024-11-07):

[PCB] Test v2.0b and improve v2.0c boards

SmittyHalibut, 2024-11-07:
Receive prototypes from #63 and test.  Find any changes needed.

Also: Add any additional feature requests here:
* **DONE** Current limiting/fusing on GPIO and SAO headers power pins
* **DONE** Pull-ups on I2C bus.  Oops.
* **DONE** Add board revision detection. I'm REALLY mad I didn't get that in v2.0.  Bleh.
* **VERIFYING** Raise cutoff frequency of LPF, lower insertion loss.
* **DONE** More sturdy PTT buttons
* **DONE** Add M3 scallops on the board edge.
* **DONE** Add a voltage detector to the VBUS from USB.
  * It's on GPIO15, with a 100k/100k voltage divider. So 5v will stay in range, and the pin can be used for other things instead if you don't care about measuring voltage.
* ADD MORE HERE (or, if you can't edit, just post to this ticket.)

SmittyHalibut, 2024-11-19:
Received boards from JLCPCB!  On to testing.

adoeller, 2024-11-22:
> On to testing.

did it explode? could you fill us in on the progress?

SmittyHalibut, 2024-11-22:
I'm keeping a list of things that need changing on the next revision in the top post of this thread.  So far, it's just fusing/current limiting some things, and adding pull-ups on the I2C bus on the SAO.  Nothing that impacts the functionality of the radio.

SmittyHalibut, 2024-11-23:
* Added 1.2k pull-ups on I2C
* Added 100mA resettable fuses to +5v on headers.
* Added 10k pull-downs on Sensor_VP and _VN, GPIO36 and GPIO39 for version detection pins.

SmittyHalibut, 2024-11-26:
Last thing I want to do is look at the LPF.

too long, didn't document: I want to switch from a Cheb to Cauer filter.  This involves adding capacitors in parallel with the series inductors.  Not a huge change, but it is a change to the board.  So now's the time to do it.  It's also a backwards compatible change; if you want to stick with the current design, just leave the caps unpopulated.

Using SVC Filter Designer https://tonnesoftware.com/svcfilter.html, I went with these design parameters:
* Order: 7
* Inductor Q: 30   (doesn't impact the design, only how realistic the simulation is.)
* Bandwidth (ripple): 208MHz   (aka, the cut off frequency.  See below for why this frequency exactly.)
* Impedance: 50
* Topology: C-input lowpass
* Family: Cauer
* Passband ripple: 0.01dB
* Stopband depth: 40dB

Produces the following:
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

A few things to note:

The cursor is hovering over the top of the 2m band, and shows less than 0.5dB insertion loss.

The resonant frequency of the third filter element is 292MHz, which is right at the first harmonic of the 2m band: 144-148 -> 288-296.  That's what causes that dip in the graph at that frequency, providing ~50dB of attenuation of the second harmonic.

This is a result of how Cauer filters are calculated, and is based on the "bandwidth" (aka cut-off frequency.)  I found this configuration by trial and error.  I played with several cut-offs: 160, 170, 180, and 200.  At 200MHz, I noticed that one of the resonant dips was CLOSE to the harmonic, so I fiddled with the "Down 1%" and "Up 1%" buttons until I landed at 208, which a resonant dip at 292MHz.

SO!  We are going with the following values, in order from left to right:
* Shunt Capacitors: 10pF, 18pF, 16pF, 5.1pF
* Series Inductors: 43nH, 30nH, 27nH
* Series Capacitors: 2.7pF, 13pF, 11pF

SmittyHalibut, 2024-11-26:
I simulated the above design in Qucs to verify voltage and current maximums.  This is simulated at 5W:
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

The absolute maximums over 100MHz to 200MHz, into a 50+j0 load, are 41.4v, and 1.1A.  That doesn't give me warm fuzzies with 50v capacitors.

Dropping that to 1W makes things more reasonable:
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

18.2V and 483mA.  I'm using those, and hoping for some overhead, when spec'ing components.

SmittyHalibut, 2024-11-26:
Ok.  So.  Capacitors are easy to find in 50v (hard to find in less than 50v).

Inductors are a little different.  I'm specing: LQW2BANxxN (where xx is the inductance in nH) which are good for at least 1.5A (depending on the value.)  Most other small inductors in this inductance are in the 200mA to 600mA range, which is cutting it awfully close for comfort.

Having said that, the 43nH and 30nH aren't in stock right now.  I've pre-ordered them, and one has been quoted; still waiting on the other quote.  So hopefully I can use the real components when I go to a production run.

For the v2.1a prototypes, I'm going with alternate components with 600mA limits.  They'll WORK, they just won't be ideal.

SmittyHalibut, 2024-11-27:
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

Really the only change that I feel needs testing is the LPF design.  So I'm ordering test boards for just the new LPF design, which is a whole lot cheaper than ordering 5 whole v2.1 boards.  Once I validate the LPF design, then I'll order a larger quantity of v2.1 boards.

My hope is to design a UHF filter tomorrow and get those boards ordered too.  Lets see if I can actually make that happen or not.

SmittyHalibut, 2024-12-05:
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

[2024-12-05 v1.0a 001 1M to 2G.s2p.txt](https://github.com/user-attachments/files/18029605/2024-12-05.v1.0a.001.1M.to.2G.s2p.txt)

That's looking pretty good!

SmittyHalibut, 2024-12-05:
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

Scallops.

SmittyHalibut, 2024-12-06:
https://github.com/VanceVagell/kv4p-ht/pull/129 is a thing now.  :-)

adoeller, 2024-12-06:
Nice.

Please provide the production files so Santa can bring one on time.

SmittyHalibut, 2024-12-06:
> Nice.
>
> Please provide the production files so Santa can bring one on time.

https://github.com/VanceVagell/kv4p-ht/pull/129

SmittyHalibut, 2024-12-11:
Bloody hell, I didn't update the LCSC column for the new PTT buttons.  New PR incoming.

gx1400, 2024-12-18:
Suggestions for next revision:
1. Change SAO header to thru hole (a cantilevered SAO could break off copper pads). Feedback from BadgePirates
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
SmittyHalibut, 2024-12-22:
v2.0 already has an ESP32 (with internal DAC) and serial chip. That’s not likely to change. It has the fewest changes from existing v1 boards and is functionally equivalent. v2.1 or v3 is likely to be an ESP32-S3 with an external I2S CODEC (there are MANY options.) Ideally using the native USB interface on the -S3 to the phone instead of an external serial chip. The only thing that’s likely to change here is the ESP32. We aren’t using any of the features that make the ESP32 unique and might be able to swap it for something smaller and less expensive, but that’s not the biggest priority.On Dec 21, 2024, at 8:29 PM, gx1400 ***@***.***> wrote:

The ESP32-S3 features native USB support, I guess it doesn't have a DAC - somebody's hacked a PDM pulse density modulation scheme to do audio output, but given the (apparently?) ugly state of serial chips, why not use an I2S DAC? You'd be getting rid of the CH340.
Tangent: As for the CM108, yeah it works more or less in radios, I brought this up in the APRSDroid repository because the AIOC (All In One Cable) people use the CM108 and it works great in Direwolf TNC, but PTT doesn't work in APRSdroid, and there's some howling that it never will unless the phone is rooted. People have feelings. Nothing was done about it as far as I know.

For what its worth the AIOC doesn't use a CM108, it implements a stm32 that presents itself as an HID device that looks like a CM108 and responds to CM108 GPIO control commands for toggling IO for PTT
I want to experiment with an esp32s3 and the tinyusb libraries to see if I can get an esp32s3 to appear like either two VCPs (one for command & control, one for audio) or one VCP and one audio interface
I thought the Everest ES8388 looks like a usable codec chip

—Reply to this email directly, view it on GitHub, or unsubscribe.You are receiving this because you were mentioned.Message ID: ***@***.***>

SmittyHalibut, 2024-12-29:
Received v2.0c boards today.  Initial testing of two modules shows that the NeoPixel is ... fragile.  Both of them failed very quickly on the two boards I pulled first.  I'm not optimistic with the components selected.  These are a completely new feature, so we might just ignore them.  At least for this version.  Dunno.

SmittyHalibut, 2024-12-31:
Update: Nope!  NeoPixels were fine!  Some software issue or other.  I had problems today with RTS and DTR in indeterminate states, keeping the ESP32 in Reset.  My GUESS is that this is what I saw the other day.

(RTS = True, DTR = False) will hold the ESP32 in reset.  Changing either one releases reset.  Ask me how I know.  ;-)

I wrote some scripts to help the automation of programming these boards (commit incoming.)  These scripts EVOLVED over the day, and show it.  If I knew all the requirements going into it, I'd probably have started in Python and stayed there.  As it is, its a BASH script that does a lot of the process logic and calls out to PlatformIO to do the actual programming, and a Python script that talks to the Serial ports, called by the BASH script.  (You'd think there was a utility that does this already, but I couldn't find it.)

Anyway.  I have 46/50 boards programmed, tested working (as well as my test code can test anyway), and wrapped ready for shipment (almost.)

There were 4 (of 50) bad boards:
* 3 had loose USB-C connectors.  Wiggling the cable caused the connection to drop.
* 1 had a bad NeoPixel.  Truly!  Not the "bad" from the previous post!  :-)

8% failure rate isn't far off from expected.  I usually expect somewhere between 5 and 10%.

VanceVagell, 2025-01-20:
@SmittyHalibut I think this one is done? If so, could you please close it?

Closed 2025-01-21.

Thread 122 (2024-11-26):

[ESP32] Detect board version, and adjust config accordingly

SmittyHalibut, 2024-11-26:
With v2, I've added a way for the ESP32 to detect which version of the board it's running on.  This allows you to build a single image that will work on multiple boards.

The detection pins are GPIO36 and GPIO39 (aka: Sensor_VP and Sensor_VN).
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

Each pin can be in one of three Config States:
* LOW: tied to ground
* HIGH: tied to Vcc
* Hi-Z: completely disconnected.

The code detects which state each pin is in by configuring the pin with an internal pull-up, and read its state.  Then configure it with an internal pull-down, and read its state again.  The mapping from Pin State to Config State is:

| Config State | Pull-Up Pin State | Pull-Down Pin State |
|--------------|-------------------|---------------------|
| LOW | LOW | LOW |
| HIGH | HIGH | HIGH |
| Hi-Z | HIGH | LOW |
| *error* | LOW | HIGH |

The Board Version is a 2-digit base-3 number, for a total of 9 trackable versions.  The only valid Board Versions right now are:

| Board Version | GPIO36 | GPIO39 | Comment |
|---------------|--------|--------|---------|
| v1.x | Hi-Z | Hi-Z | All old versions did nothing with the Sense pins |
| v2.0b | HIGH | HIGH | v2.0b requires a bodge: pins 4 and 5 on ESP to immediately adjacent 3.3v test pad. |
| v2.0c | HIGH | HIGH | The first board with this actually implemented in the board. Electrically similar to v2.0b, so same Board Version. |

We'll add more to that table as we make more boards that require software changes.

Let me know if you have any questions.

SmittyHalibut, 2024-12-03:
Shoot.  Hi-Z/Hi-Z will make v2.0 indifferentiable from v1.x.

OK.  SO.  Here's the plan.  We only need to support v2.0b for a short time.  Once v2.0c is verified, we can send all our v2.0b hardware to the e-waste, so we don't need to support it long term going forward.

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

Pins 4 and 5 are the sense pins.  Currently, they're shown disconnected, Hi-Z state.  This is what's on the v2.0b boards.  This is electrically the same as the v1.x boards, hence the problem.

My proposal for v2.0b is to bodge pins 4 and 5 to the immediately adjacent 3.3v test point.  I'll connect v2.0c to GND.  This will make the following table:

* v1.x: Hi-Z/Hi-Z
* v2.0b: HIGH/HIGH
* v2.0c: LOW/LOW

Once v2.0c is stable and we move on to v2.1 or whatever, when we're willing to ditch support v2.0b hardware, then we can reclaim the HIGH/HIGH state for another hardware rev.

I'll update the table above with the current values.

dwillmore, 2024-12-03:
There are other options as well. You can put a resistor/cap combo with different time constants on the pins and use the pullup/pulldowns to test them.  That gives you a very wide range of values.  If these pins can be analog inputs, you can use a resistor ladder to generate a variety of voltage which the A/D can sample.  You can get quite a few bits that way.

This is one of those problems that woke me up at 4am one day and filled a page in my bedside notebook.

SmittyHalibut, 2024-12-03:
Hehe.  All very true, and the sense pins can be analog inputs as well.  They're specifically designed to be a precise differential analog input, so we're well suited for options in the future.

For now though, 9 non-backward-compatible board revisions are enough to get us started.  We can add more options in the future as necessary.  KISS.

VanceVagell, 2025-01-25:
I don't think I need to do anything with this enhancement request, right? Closing. Please reopen if something is needed.

SmittyHalibut, 2025-01-28:
Dang it!  I knew there were already issues for these things I've been doing!  Yes, this is duplicate of https://github.com/VanceVagell/kv4p-ht/issues/203

Closed 2025-01-25.

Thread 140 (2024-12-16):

Clicking and processor noise in the audio while on RX

rovinnaki, 2024-12-16:
We are getting  what sounds like processor noise over the rec audio when the squelch is open and with the squelch closed it is a load clicking sound. I have attached a short video of the issue. can anyone help please We have built 2 units and have tried them on 3 different samsung phones with the same results.

https://github.com/user-attachments/assets/a84f557e-0495-4267-afc4-f02130b927c9

VanceVagell, 2024-12-16:
Some other community members have this issue as well, we think it might be
a certain ESP32 dev board that has some kind of issue.

Could you please attach a close up photo of the esp32 dev board you are
using?

Is this the esp32 provided by PCBway? Some people have reported similar
issues with that one.

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

rovinnaki, 2024-12-17:
Hi Vance

The chips are from the link in your site and PCBWay.

Regards

Dave Sargent

ZL2TLF

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

gx1400, 2024-12-17:
> We are getting what sounds like processor noise over the rec audio when the squelch is open and with the squelch closed it is a load clicking sound. I have attached a short video of the issue. can anyone help please We have built 2 units and have tried them on 3 different samsung phones with the same results.
> Audeo.issue.KV4P.RX.mp4

Could you please post a photo of your esp dev board in #139

dkaukov, 2024-12-17:
for experiment, I`ve forced firmware to always send zeros:
```
       ....
        // Apply attenuation to the sample
        int adjustedSample = (((int)sampleValue - 128) * attenuation) >> 8;
        adjustedSample += 128;
        buffer8[i] = 0; //(uint8_t)adjustedSample;
      }
```
And it still clicking. ;(

gx1400, 2024-12-17:
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

Are you familiar/comfortable with android studio?

dkaukov, 2024-12-19:
@gx1400  It seems like problem not in ESP32 after all.. Using simple python script, i was able to play this audio stream on laptop. And it plays fine, while clicking and popping on Android. ;(

VanceVagell, 2024-12-19:
It is likely the cable or connector you're using.

Please try a well shielded USB cable, or multiple different ones. Since
you've confirmed it's not the esp32, the other major cause of audio issues
is RFI getting into the connector or cable and disrupting the audio stream
when connected to a phone.

On Thu, Dec 19, 2024, 7:28 PM Dmitry Kaukov ***@***.***>
wrote:

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

rovinnaki, 2024-12-20:
Hi Vance

We have tried 2 different cable and also an OTG jumper but will try a shielded cable and maybe a ferrite core around the usb cable and see what happens.

Regards

Dave

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

dkaukov, 2024-12-20:
@VanceVagell Everything possible, but I'm using exactly the same and fairly good quality cables: https://www.youtube.com/watch?v=Yrz4vTQjWPw

dkaukov, 2024-12-20:
Hi @VanceVagell,
 I have a question regarding the configuration of buffer sizes in the RadioAudioService class.

At [line 840](https://github.com/VanceVagell/kv4p-ht/blob/75a48a2629889d743e3930fabb2c125302364911/android-src/KV4PHT/app/src/main/java/com/vagell/kv4pht/radio/RadioAudioService.j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), the ReadBufferSize is set to 4096, causing the driver to collect 4096 bytes of data before triggering the callback. However, at [line 670](https://github.com/VanceVagell/kv4p-ht/blob/75a48a2629889d743e3930fabb2c125302364911/android-src/KV4PHT/app/src/main/java/com/vagell/kv4pht/radio/RadioAudioService.j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), the AudioTrack is configured with the minimum buffer size, which is approximately 150 bytes.

This seems to result in a mismatch: when we write to the AudioTrack buffer at [line 1171](https://github.com/VanceVagell/kv4p-ht/blob/75a48a2629889d743e3930fabb2c125302364911/android-src/KV4PHT/app/src/main/java/com/vagell/kv4pht/radio/RadioAudioService.j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), it blocks due to the difference in buffer sizes. When exiting, the system waits for another 4096 bytes of data, which leads to an underrun.

Could you clarify the intent behind these buffer configurations? Was this approach chosen to handle a specific use case, or is there an optimization opportunity here?

dkaukov, 2024-12-20:
This seems to be fixing clicks for me: https://github.com/VanceVagell/kv4p-ht/pull/142/files

- Buffer is 3x chunk size
-  We priming it with 2 chunks

VanceVagell, 2024-12-20:
Thank you! I will test this in a few different esp32 versions when I'm home
in a few days and then merge it.

On Fri, Dec 20, 2024, 3:54 AM Dmitry Kaukov ***@***.***>
wrote:

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

dkaukov, 2024-12-26:
Hi everyone and @rovinnaki,

If anyone is interested in testing the proposed solution and can manually install the .apk and flash the firmware, I've created a test release here: [Test Release - click-fix-01](https://github.com/dkaukov/kv4p-ht/releases/tag/click-fix-01).

Let me know if you encounter any issues or need further instructions. Your feedback is appreciated!

rovinnaki, 2024-12-27:
Good Evening Dmitry

We will start with the firmware that we flashed onto the device, when used with the new software on the phone the ESP LED  flash every 2 seconds and there noise burst with the flashes with or without the squelch control on.

We may installed the firmware correctly but this on 2 different devices with the same results. When loading the bin file it noted that the file may not be a bin file but completed the loading okay.

With the new software (APK) installed, we used the flash function to reflash the ESP then we retested the device and the audio was clean about 90% better. There are now no clicks when the squelch is enabled but had very faint distortion in the audio but as I say 90% better.

I trust this helps you with your testing.

Regards

Dave Sargent / Elton Sargent

ZL2TLF/ZL3LT

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

dkaukov, 2024-12-27:
Hi @rovinnaki,
Thank you for the detailed feedback! It's great to hear that reflashing the ESP improved the audio quality significantly. Regarding the faint distortion, I suspect it might be due to the absence of ADC bias in the setup. Could you confirm if this part of the circuit was implemented?
Here’s the schematic for reference:

```
    DRA818 AOUT-+---- GPIO34 (ADC Input)
                |
               [R1] 22kΩ
                |
 GPIO26 (DAC2) -+
                |
               [C1] 0.1µF
                |
               GND
```
(effectively you just need 22k resistor between GPIO34 and GPIO26)

rovinnaki, 2024-12-27:
Good Morning Dmitry

No we haven’t done that mod, we will carry out this change and get back to you. Thanks for all the help for this great little project.

We want to get this right as we have bought 10 of these units with the thought of building them as a radio club project.

Have a great New Year.

Dave Sargent

ZL2TLF

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

rovinnaki, 2024-12-27:
Hi Dmitry

Maybe a stupid question but does C1 need to be added as well or is it already installed

Regards

Dave

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

dkaukov, 2024-12-27:
Hi @rovinnaki ,

Good question – not stupid at all!

C1 (the filtering capacitor) isn't installed and needs to be added manually. It helps filter out noise from the 1.1V DAC output on GPIO26 (not used in the original kv4p design), providing a more stable bias for the ADC input.

For a quick test, you can skip installing C1 and see if the audio distortion is gone. If you notice noise, adding a 0.1µF capacitor between GPIO26 and ground should help improve performance.

rovinnaki, 2024-12-28:
Hi DmitryThanks that clears it up we willtry that tomorrow and get back to youYou help is much appreciated. RegardsDaveSent from my Galaxy
-------- Original message --------From: Dmitry Kaukov ***@***.***> Date: 28/12/24  11:28 am  (GMT+12:00) To: VanceVagell/kv4p-ht ***@***.***> Cc: rovinnaki ***@***.***>, Mention ***@***.***> Subject: Re: [VanceVagell/kv4p-ht] Clicking and processor noise in the audio
  while on RX (Issue #140)
Hi @rovinnaki ,
Good question – not stupid at all!
C1 (the filtering capacitor) isn't installed and needs to be added manually. It helps filter out noise from the 1.1V DAC output on GPIO26 (not used in the original kv4p design), providing a more stable bias for the ADC input.
For a quick test, you can skip installing C1 and see if the audio distortion is gone. If you notice noise, adding a 0.1µF capacitor between GPIO26 and ground should help improve performance.

—Reply to this email directly, view it on GitHub, or unsubscribe.You are receiving this because you were mentioned.Message ID: ***@***.***>

rovinnaki, 2024-12-31:
Good Afternoon Dmitry

Thanks for all the help, we have now got a clear audio with no clipping or interference. I have found if we use a OTG cable between the phone and the device the program will lock up on TX but if we use the moulded jumper between the phone and the device all is okay. I will look for a ferrite clip to put around the short jumper cable and see if that stops the looking on of the TX. I will let you guys know once I have the ferrite bead.]

Regards and have a great New Year.

Dave

ZL2TLF

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

VanceVagell, 2024-12-31:
v1.6 was just released to public today and has some significant additional
audio improvements. Dmitry could you please see if it fixes the problem in
this bug? Thanks

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

VanceVagell, 2024-12-31:
It will likely roll out throughout the day, please confirm you actually
have 1.6 when testing. (Or just do a git pull and deploy it manually)

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

VanceVagell, 2025-01-12:
This issue is fixed in v1.6.5 which will be going to a public launch later today.

rovinnaki, 2025-01-12:
Good Morning Vance

Thanks for your help to fix this issue it is appreciated, have a great New Year.

Regards

Dave

Zl2TLF

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

Closed 2025-01-12.

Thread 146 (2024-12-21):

[PCB] Filter change to improve performance (v1.8)

BillH63, 2024-12-21:
The following changes improve the performance of the HT as follows:
Power out of 1.7b at 144MHz is .40W, at 146 MHz it's .42W and at 148MHz it's .40W. The 1.7b mod version is .58W, .61W and .63W respectively. Squelch set to one step up from the bottom opens on 1.7b at -121DBm and for 1.7b mod at -157.5DBm. The 2nd harmonic of both are just over 50DBm down from the fundamental with the 1.7b mod just slightly more.

Components used in updated filter https://www.digikey.com/en/mylists/list/FDT7DIPB02

Updated schematic of LPF filter
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

NanoVNA performance 140MHz to 150MHz (light purple color lines are 1.7b reference measurements, darker are mod)
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

NanoVNA performance 100MHz to 300Mhz (light purple color lines are 1.7b reference measurements, darker are mod)
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

Power out of 1.7b at 146MHz
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

Power out of 1.7b with mod at 146MHz
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

roberthadow, 2024-12-21:
Nothing at all to do with the filter--I used it to build three radios yesterday. Thanks.

Vance, probably the right person, needs to define the versioning scheme for boards, assembled boards. and Android app. Things are already complicated by 1.7b, which can be built in two ways.

The app is straightforward.  There will be only one branch of released software.  What goes on under the sheets of development is a developers' GitHub problem.  The implication is this: An enhancement or fix goes only one place, the next or some future release.  When that enhancement or fix takes advantage of an Android feature not available to some current user, that user gets two choices: (1) stick with the last relase that worked or (2) upgrade Android or phone.  The matter is made stickier because at the Play store you can have any version you want, as long as it's the last one.

This is a relatviely straighforward configuration management problem.

roberthadow, 2024-12-25:
@BillH63 How much work was the development of the 1.7b.2 LPF?  How long did it take you to test?  Would it be worth the effort to specify a set of devices to fit on 1.7b to accomdate UHF? It shouldn't be too much work for @VanceVagell to give us a version of the Andoird app to accomodate the higher frequencies output by DRA818U.

VanceVagell, 2024-12-27:
Thanks for the hard work improving the filter! I'm working on applying it to a new PCB version 1.8.

To the question of a UHF variant, I'm happy to make the app updates if someone could supply the appropriate filter values. My understanding is that things like trace length become important at UHF, so I wonder if the current layout would even work or needs more significant changes (I'm all ears, and open to a complete board submission!).

I believe SmittyHalibut is working on a UHF variant, but I think it will be based on the v2.0 PCB (which will be great for more users, but some people want to do more of the building).

VanceVagell, 2025-01-19:
Confirmed this new filter is working on v1.8 PCBs, thanks!

Closed 2025-01-19.

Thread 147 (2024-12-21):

[PCB] Remove solder mask under DRA818 heatsink connection

BillH63, 2024-12-21:
In future revisions of 1.7b please remove the solder mask on the ground plain under the DRA818 P1 pad so that it can be soldered to board for head dissipation.

Per email from DORJI
> Thank you for your interest in our products.  P1 is the heat dissipating copper for the PA so it must be connected to ground. On the side of P2 and P3, there is no pin pads so it might be helpful to fix the product on the mother board.

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

roberthadow, 2024-12-21:
The folks at home will have a helluva time with a rework gun trying to heat up Pad 1 to reflow the solder.  The alternative is to throw the unit in a toaster oven.  With the shield on top, cooking time will be forever.  There was already a guy on Discord who discribed how hard it was to flow Pads 2 and 3.  If he did it with an iron, I say, "Hats off to him."

**Even If** the top layer under Pad 1 on the 1.7 board is a ground pour and bared of mask, **and if** the point is heat dissipation, then no additional electrical connection is required, just some heat sink compound. Like Brylcreem, "A little dab will do you."

The drawing above does not represent the board as delivered.  There are no castellations on the west end of the board. Figure 2 on page 2 of the datasheet is correct. Figure 4 on page 9 (the one above) is incorrect.

BTW, the Dorji data sheet is silent as to the mechanicals of the pads, or the other four unidentifed pads.  I suspect, without evidence, that the four are for testing. If heat were an issue, I suspect someone would have added a paragraph.

BillH63, 2024-12-21:
The four other dot pads are for programming the module at the factory. I asked.

roberthadow, 2025-01-07:
If cooling is an issue, one alternative to solder or thermal grease is TGON-805 under Pad 1.  It has twice the thermal conductivity of thermal grease.

BrucePerens, 2025-02-21:
Use chip quik (indium solder) on that pad. Goes on and comes off really easily. Of course you can use normal solder paste for production.

SmittyHalibut, 2025-07-30:
v2 boards, starting with v2.0d, have exposed copper, with very large holes to fit a large soldering iron tip through.

Having said that, even with my MetCal on the hottest, highest energy tip, I STILL can't get anything to flow in there.  Soldering that pad is next to impossible without an entire heat-soak oven.  But at the very least, exposed copper/solder will conduct heat better than solder-mask.

Resolving.

Closed 2025-07-30.

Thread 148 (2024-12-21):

[PCB] Connecting Audio to ADC is Problematic

dkaukov, 2024-12-21:
### Issue
The current approach of directly connecting an AC audio source (±1V) to the ESP32 ADC input can lead to:

- Clipping: Audio signals may exceed the ADC’s 0-1.1V range, causing distortion.
- Biasing Issues: Without proper DC bias, the ADC cannot correctly sample the audio waveform.
- Noise Sensitivity: Floating or improperly biased inputs can pick up noise, leading to inaccurate readings.

### Suggestion
A simple way to improve this is to use GPIO26 (DAC2) to output the internal 1.1V reference. This can be used to bias the audio input, ensuring the signal stays within the ADC's measurable range.

```
  dac_output_enable(DAC_CHAN_1);  // GPIO26 (DAC1)
  dac_output_voltage(DAC_CHAN_1, 85 / 2);  // ~1.1V / 2
```
When we can feed this voltage to ADC_IN (GPIO34) through 10k resistor.

This method leverages the ESP32's built-in Vref, reducing the need for external components while ensuring more accurate audio sampling.

VanceVagell, 2024-12-21:
Thanks Dmitry, this is all new information to me and very interesting. I
will have to bodge this in and test it out.

On Sat, Dec 21, 2024, 7:28 PM Dmitry Kaukov ***@***.***>
wrote:

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

dkaukov, 2024-12-22:
This is what we have currently:

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

Closed 2025-01-09.

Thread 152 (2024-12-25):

The ESP32 board the main website links to does not work with USB-C to USB-C cables.

orsty3001, 2024-12-25:
I think the link to the Aliexpress site for the ESP32 dev boards isn't the same as when the link was added to the main website. I received four boards in the mail yesterday (Dec 24th, 2024). None of these boards work with USB-C to USB-C cables. I can only program them using a USB-A to USB-C cable. None of my Android devices can see these boards since they all have USB-C ports.

Probably need to find a new link or at least warn people that there is a possibility that the ESP32 board they ordered might not work at all for this application.

VanceVagell, 2024-12-25:
I'm sorry to hear it's not working for you! On the Quick Start page, we
only link to two cables/connectors that will work.

Perhaps you ordered from an earlier version of the site before we found the
cables and connectors with the missing resistors.

I'm not aware of any current source in the US for esp32-wroom dev boards
with the resistors (required for a normal USB c to c cable to work).

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

orsty3001, 2024-12-25:
No need to apologize, I know it's not your fault.

So I have several ESP32 dev boards that I've used for other projects. I have another one that works but has an audio issue. I figured it was the UART controller not being up to spec so I ordered the ones suggested on your website plus the USB-C "U" connector.

This is a picture of what I received yesterday. I'm not sure what resistor I'm looking for. It's completely different from the boards I have so comparing them is difficult for me since I don't know enough about how these boards are made.

I have a USB-C to A converter that I tested. That works but the USB-C cables or the "U" doesn't work.

After testing it, really it didn't answer any questions it just raised more. It could be my cables, but these cables work on my other ESP32 dev boards with USB-C.

Or Maybe I ordered the wrong thing?

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

VanceVagell, 2025-03-09:
This dev board should work fine. Since you opened this bug, many improvements were made to the app and firmware to better support more dev boards.

There's also now a PCB v1.8 that comes in three footprints for different ESP32 dev boards (normal, narrow, or short). You can find those on the kv4p.com Quickstart page if you need one.

Closing this issue because I think it is likely resolved in the latest software and hardware, but please reopen with more details if you continue to have issues! Thanks.

Closed 2025-03-09.

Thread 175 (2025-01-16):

[pcb] v2.0d updates

SmittyHalibut, 2025-01-16:
I'm ordering another batch of v2 boards and want to make a few minor updates:

* Move the Reset and Program buttons further apart.  My sausage fingers can't press the buttons at the same time.
* SA818 is too hard to solder. Make the pads larger.
* Can't solder the SA818 heatsink. Larger holes might help this.
* I removed a few DNP components that were for build options, but were never used. Just cleaned up the layout.
* Labeled the pins on the SA818 to make it easier to poke at it with a volt meter or oscope to test what's up.
* Add the ADC auto biasing circuit.

Also:
* I'm not going to populate the headers. They are far and away the tallest part on the board.

The Bad News(tm):
* I had to move the LEDs.  The NeoPixel is in the same place, but the Power and User LEDs

SmittyHalibut, 2025-01-16:
I'm also looking at biasing the ADC input from the radio.  See https://github.com/VanceVagell/kv4p-ht/issues/148 and related tickets.

SmittyHalibut, 2025-01-19:
ADC Bias stuff:
* Issue: https://github.com/VanceVagell/kv4p-ht/issues/148
  * Other issue that this should address: https://github.com/VanceVagell/kv4p-ht/issues/140
* Pull Request: https://github.com/VanceVagell/kv4p-ht/pull/159
* Original author, who did the debugging and designing of this issue: https://github.com/dkaukov

Summary:
## v1 hardware
v1 hardware has no ADC biasing.  Audio is DC coupled from radio to microcontroller. Not sure how this ever worked.  I can believe that the output from the radio is AC coupled, but the ADC input to the ESP32 is not likely to have any DC path to ground, power, or internal bias.  This leaves it floating and indeterminate.  This could be why some people have issues and others don't.

## v2 hardware
v2.0c hardware is biased in hardware to 0.57v (47k/10k voltage divider from +3.3v).  This was chosen to be (about) the middle of the ADC native range of about 0.1v to 1.1v.  The analog audio needs to be about 1v p-t-p.

Software to make this work:
* `ADC_ATTEN_DB_0` at https://github.com/VanceVagell/kv4p-ht/blob/main/microcontroller-src/kv4p_ht_esp32_wroom_32/kv4p_ht_esp32_wroom_32.ino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 instead of `ADC_ATTEN_DB_12`.
* `dra->volume(4);` at https://github.com/VanceVagell/kv4p-ht/blob/main/microcontroller-src/kv4p_ht_esp32_wroom_32/kv4p_ht_esp32_wroom_32.ino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 to keep the output audio from the 818 within the range of 0.1 to 1.1v.

This works, however if the radio has fixed level audio noise output (noise that isn't affected by adjusting `dra->volume();`, that noise will be maximized by this setup.  Instead, we'd prefer to use a larger voltage range signal.

This could be done by hardware attenuation of the signal before feeding to the ADC, instead of using the volume control on the 818.  Any fixed noise would also be attenuated.  It could also be done by using the current `ADC_ATTEN_DB_12` setting, which increases the voltage input range to 150 mV to 2450 mV (see https://github.com/VanceVagell/kv4p-ht/pull/159#discussion_r1903800651), and biasing to 1375mV.

This biasing could be done in hardware the same way the current 0.57v bias is done.  The way that @dkaukov suggested we do this allows us to set all of this in software:  Use the unused DAC to generate a bias voltage.  I like this because it lets us adjust everything in software: volume output from the radio, input range to the ESP32, and the bias voltage.  The only thing it can't do is change hardware attenuation.

To do this, the software would need to detect v2.0c and v2.0d hardware and set the attenuation, dra volume, and bias voltage appropriately.

The question is: Are we ready to "burn" a hardware revision for this change?  We have 9 revisions, 2 of which are already in use.

VanceVagell, 2025-01-19:
What would be the user perceived difference in doing this in hardware versus doing this in software (per PR #168 which was merged earlier today)? And would it break anything for people with 1.x PCBs?

dkaukov, 2025-01-20:
Hi @SmittyHalibut @VanceVagell,
I think, The HAM community can probably handle soldering a 22k resistor between GPIO34 and GPIO26 without breaking a sweat.  From this perspective, "burning" a hardware revision, that might be a tad dramatic. ;)

VanceVagell, 2025-01-20:
There are already over 1000 people with a kv4p HT, or in the process of getting one. So we need to be careful changes don't break existing PCB versions they have, and it's not possible to contact them all and ask them to change the components on the PCB.

But I agree we can certainly make future versions (like 2.0+) more capable. I just need to understand the impact on prior releases, so I can try to mitigate them for backwards compatibility as long as possible.

In this case, my main question is whether I need to query the 2.0 PCB for its version and do something different, or if it will play nicely with the firmware as-is.

dkaukov, 2025-01-20:
Hi @VanceVagell ,
I don’t think we need to add any "detection" for the ADC bias issue—these changes don’t make things worse for old PCB revisions, so it should be fine.

Also, I think the info about the 22k resistor between GPIO34 and GPIO26 for older PCBs should be made public so people know what to do if they have an older board.

SmittyHalibut, 2025-01-20:
> @dkaukov said: I think, The HAM community can probably handle soldering a 22k resistor between GPIO34 and GPIO26 without breaking a sweat. From this perspective, "burning" a hardware revision, that might be a tad dramatic. ;)

I agree "burn" is a bit dramatic ;-)  However, I wish I could agree with you about "most ham radio operators."  There probably is some self selection of hams who would be an early adopter for a project like this that suggests they can, but the v2.0c hardware is mostly owned by people who'd prefer to throw money at a commercial manufacturer, than go through the trouble of sourcing their own hardware and building it themselves.  Read: People who want the Product, not the Project.  These are the folks we should be targeting.

The good news is, I think we can do this.

I just hacked the hardware change that @dkaukov proposed: I put a 100k between the second DAC output and the AF input to the microcontroller, after my DC blocking cap.  See the video in discord to see the results (can I post short videos to github?)
https://discord.com/channels/1290074006908829746/1290074125553111143/1330696789241630730

And (not surprisingly) it worked exactly as he designed and I expected:  Audio centered around 1.70v, ranging from about 2.6v to 0.8v. Very rough numbers.  The 2.6v is a bit above the theoretical ideal spot, but we can adjust the bias in software with this change.

As for "Do we have to undo any software changes?"  There are two PRs I see:

* https://github.com/VanceVagell/kv4p-ht/pull/168/files
  * This one can (and should) definitely stay in the code.  This removes any DC from the sample data, which is a good thing regardless.
* https://github.com/VanceVagell/kv4p-ht/pull/159/files
  * This one actually implements the software changes for the hardware changes that I'm applying.  So this needs to stay too.  Though, I will be modifying this for different hardware revisions.  That change will be part of my PR.
* Did I miss any?

When I make this change, the software will have to detect hardware versions, and configure things accordingly:

* v1.x: Leave the software exactly as is, because y'all say this works the best.  I'm pretty sure there's some more fine tuning that could be done here, but we can do that over time.  My PR won't make any changes to v1 hardware.
* v2.0c: `ADC_ATTEN_DB_0` and `dra->volume(4);`.  This brings the audio output from the 818 down into the 1.1v range of the ADC, and the 0.57v bias voltage that's set in hardware on the v2.0c boards.
* v2.0d: `ADC_ATTEN_DB_12` and `dra->volume(8);`.  (Which is how the software is currently set.)  This will hopefully give us the best signal to noise ratio from the radio.  We can fine tune the bias voltage point using https://github.com/VanceVagell/kv4p-ht/blob/main/microcontroller-src/kv4p_ht_esp32_wroom_32/kv4p_ht_esp32_wroom_32.ino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

I will submit a PR that includes all the above.

dkaukov, 2025-01-20:
Hi @SmittyHalibut
I get your point about the "Product" vs. "Project" crowd. Targeting the folks who want a ready-made product definitely makes sense.

I don’t fully agree with leaving the v1.x software as-is. Generating the bias voltage on an unused pin doesn’t break anything, and switching to `ADC_ATTEN_DB_12` even won’t reduce the overall volume. It would make sense to apply this adjustment across all versions, simplifying things. For `v2.0c`, an exception might be necessary, but other revisions could benefit from this change to keep things clean and straightforward.

SmittyHalibut, 2025-01-20:
To be clear: The DB12 and bias code is already released.  So "do nothing" has that code in.  I'm saying we don't have to pull it out.  :-)

VanceVagell, 2025-01-20:
Your proposed code change PRs above sound good to me @SmittyHalibut , please let me know if you run into issues or have questions.

dkaukov, 2025-01-20:
@SmittyHalibut Sorry, looks like I've missed your point. Why you want to reduce volume (`dra->volume(8)`)?  With ADC_ATTEN_DB_12 we fit in range. If we want to attenuate more, probably easiest solution is to reduce bias resistor to something like ~10k.

SmittyHalibut, 2025-01-20:
> Your proposed code change PRs above sound good to me [@SmittyHalibut](https://github.com/SmittyHalibut) , please let me know if you run into issues or have questions.

#181  :-)

SmittyHalibut, 2025-01-21:
@dkaukov I see an email with a post to this ticket, but the post isn't here anymore.  I assume you deleted the post.  Did you get your question answered satisfactorily?

SmittyHalibut, 2025-01-28:
See https://github.com/VanceVagell/kv4p-ht/pull/202 now.  This is just the hardware changes, removing all the code changes.  I'll implement them in their own tickets and PRs.

SmittyHalibut, 2025-01-28:
v2.0d hardware changes are done.  Resolving.

Closed 2025-01-28.

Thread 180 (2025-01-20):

[ESP32] Fine tune the ADC bias voltage

SmittyHalibut, 2025-01-20:
https://github.com/VanceVagell/kv4p-ht/blob/main/microcontroller-src/kv4p_ht_esp32_wroom_32/kv4p_ht_esp32_wroom_32.ino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

(Line number may change after I submit my PR here soon.)

138 was determined experimentally, but I'm not convinced its the right value to be in the center of the ADC's range.

Look at samples from the ADC, without any DC adjustments of the normal code, and see how close to the center we are.  Alternatively, look at the DC offset adjustment, see how far off it is.  Adjust this 138 value to get that DC offset as close to 0 as possible.

Actually, that's a good point.  We can do this dynamically.  Hmm.  Anyway, this is a nice-to-have.

dkaukov, 2025-01-20:
@SmittyHalibut
```
#define DAC_PIN 26                   // GPIO26 is DAC_CHANNEL_2 (Bias voltage output)
#define ADC_PIN 34                   // GPIO34 is ADC1_CHANNEL_6 (Input-only ADC pin)
#define TARGET_ADC_VALUE 2048        // Midpoint for 12-bit ADC (ideal bias point)
#define TOLERANCE 5                  // Allowable error margin for ADC value
#define ADC_SAMPLES 100              // Number of ADC samples to average

#include <Arduino.h>

uint16_t average_adc() {
    uint32_t total = 0;
    for (int i = 0; i < ADC_SAMPLES; i++) {
        total += analogRead(ADC_PIN); // Read ADC
        delayMicroseconds(50);        // Short delay between reads
    }
    return total / ADC_SAMPLES;       // Return average ADC value
}

uint8_t calibrate_bias() {
    uint8_t low = 0, high = 255, mid;
    while (low <= high) {
        mid = (low + high) / 2;        // Binary search midpoint
        dacWrite(DAC_PIN, mid);        // Set DAC voltage
        delay(10);                     // Allow signal to stabilize
        int adc_value = average_adc(); // Get averaged ADC reading
        if (abs(adc_value - TARGET_ADC_VALUE) <= TOLERANCE) {
            return mid;                // Found suitable bias value
        } else if (adc_value < TARGET_ADC_VALUE) {
            low = mid + 1;             // Increase DAC value
        } else {
            high = mid - 1;            // Decrease DAC value
        }
    }
    return mid;                        // Return last tried value
}

void setup() {
    Serial.begin(115200);
    uint8_t bias_value = calibrate_bias();  // Calibrate bias voltage
    Serial.printf("Calibrated DAC value: %d\n", bias_value);
}

void loop() {
}```

You'll need to adjust delays according to your caps values, though..

dkaukov, 2025-01-20:
Mine: 137 and 138

SmittyHalibut, 2025-01-20:
This is what the v2.0d circuit finally looked like:

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

Differences from yours:
* I put a DC blocking cap between the 818 and the biasing circuit so we aren't back-feeding any DC into the radio.  I'm PRETTY sure it's already DC blocked internally, but its better to be safe.
* C1 is my specially selected Murata part that's self resonant (read: minimum impedance) at 145MHz, for optimal decoupling at the RF we are generating.
* R1 is 100k.  We already have 100k on the board so no extra component to the BOM.  It's also what I bodged onto a v2.0c board for testing, and it worked a charm.

dkaukov, 2025-01-21:
Hi @SmittyHalibut

1) Since the 818 module already has a DC blocking cap, no need for an additional one.
2) I remember the 100k resistor causing Vmin to drop below the ADC range, but if it works in your setup, that’s fine.
3) I disagree with using 145MHz for C1 decoupling. Ideally, the anti-aliasing filter should be at half the sampling rate.

dkaukov, 2025-01-21:
Something like:
```
    DRA818 AOUT-+----[R2] 10k---+---- GPIO34 (ADC Input)
                |               |
               [R1] 22kΩ        |
                |               |
 GPIO26 (DAC2) -+              [C2] 1.6nF
                |               |
               [C1] 0.1µF       |
                |               |
               GND             GND
```
Should have Fc around 10Khz, but I did not validated that.

dkaukov, 2025-01-28:
Hi @SmittyHalibut,

Just checking in—did you have a chance to run the sketch I posted on your set of boards? Curious to hear if you found anything interesting.

Closed 2025-07-30.

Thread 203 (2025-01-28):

[ESP32] Add Hardware Version detection

SmittyHalibut, 2025-01-28:
Read Sense_VP and Sense_VN, they're either HIGH or LOW.

| Sense_VP / GPIO36 | Sense/VN / GPIO39 | Hardware version |
|-------------------|-------------------|------------------|
| LOW | LOW | v1.x, v2.0b |
| LOW | HIGH | unused |
| HIGH | LOW | v2.0d |
| HIGH | HIGH | v2.0c |

The original intent was to also use Hi-Z as a detectable state by setting internal pull-ups and pull-downs, but the Sensor pins don't have output drive hardware.  So we're stuck with external drives.

The good news is, they are analog pins, so we can provide analog voltages with voltage dividers to provide more states going forward.  For now, we're just going to use HIGH and LOW.

SmittyHalibut, 2025-01-28:
Oh!  This also fixes the fact that squelch never closes on v2.0 hardware.  The squelch detect pin changed in v2.0; we need to detect the hardware version to make this software change.

SmittyHalibut, 2025-01-28:
Oops. This is a dupe of #122.

SmittyHalibut, 2025-01-28:
https://github.com/VanceVagell/kv4p-ht/pull/205 is the PR for this.

dkaukov, 2025-02-04:
Hi @SmittyHalibut @VanceVagell
On the `1.7b` board, I had to add pull-down resistors on `GPIO36` and `GPIO39` to ground. Without them, the hardware version detection was unreliable—sometimes reporting incorrect values. It seems like floating inputs are causing intermittent issues, though the occurrence is quite rare. It might be worth updating the documentation and release notes to mention this for others who might run into the same problem.

SmittyHalibut, 2025-04-17:
#205 is done. Resolving.

Closed 2025-04-17.

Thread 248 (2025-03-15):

[Android, ESP32] Significant audio quality issues on both rx and tx since recent changes

VanceVagell, 2025-03-15:
Behavior on HEAD:
- APRS rx and tx fail (cannot decode incoming APRS messages, and the messages it sends cannot be decoded by another device, I tested with kenwood TH-d74)
- Rx audio has a repetitive popping sound

I tested this on a kv4p HT PCB v2.0c.

These issues do not exist when I roll back to commit 99939fc29d64ab1112d909527cb6725ad51c33a7 (the last one that's in v1.7.3 release), and re-test with the same devices. Audio is fine, and APRS works fine in both directions.

This is a significant regression that will block the next release until we fix them. @dkaukov would you prefer I revert to that working commit and cherry-pick other new commits to give you time to fix this, or do you think you could get this working in the next week or so? This must be related to your recent re-work.

dkaukov, 2025-03-16:
I’ll take a look and update soon.

VanceVagell, 2025-03-16:
Yes, confirmed.

On Sat, Mar 15, 2025, 8:24 PM Dmitry Kaukov ***@***.***>
wrote:

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

VanceVagell, 2025-03-16:
I also just tested with PCB v1.7x and the same issue exists.

However, after several more tests, I've found that rx audio on the kv4p HT is the primary issue. It often has repeating pops/skips, and it cannot decode APRS messages. Reverting to the commit noted above fixes the issue.

Several tests sending APRS text to a nearby Kenwood TH-D74A worked OK. So I'm not sure if tx audio is a big issue (it's at least intermittent as an issue), but APRS rx is definitely broken.

dkaukov, 2025-03-16:
Hi @VanceVagell,

Please see the linked PR  https://github.com/VanceVagell/kv4p-ht/pull/249. I was able to reproduce and fix the APRS issues; however, I did not encounter the audio problems you've reported. My audio functions correctly, but currently, I don't have access to a board with the standard CP2102 to test under those conditions. If you could test on your end and provide feedback, it would be greatly appreciated. Should the audio issues persist, I can assemble test boards, though this would require an evening or two to complete.

VanceVagell, 2025-03-22:
Unfortunately, PR #249 did not resolve this. I merged it optimistically and retested at head.

See attached video:
https://github.com/user-attachments/assets/95b1ed9e-6001-4d5f-8193-e7be133cea7f

The first half of the video is a test with a v1.7b PCB, the second half of the video is with a v2.0c PCB. I'm just holding down PTT on another HT (Kenwood TH-D74A) and you can that the audio has some kind of pulsing distortion. Once in a while an APRS message will decode (you can see a message decode at the end of the video), but the vast majority I tested could not be decoded.

Tx audio is fine, outgoing APRS messages seem consistent.

It sounds like perhaps there are frequent buffer underruns?

dkaukov, 2025-03-23:
Hi @VanceVagell

Sounds like RSSI queries—these can be audible when RX is overloaded. Can you try:

Setting the RSSI period to 500ms

Reducing TX power (I use attenuators for this)

Let me know if that helps!

dkaukov, 2025-03-23:
Hi @VanceVagell,

I recreated your experiment and got similar results.

With a 40dB attenuator on TX:
🔗 https://www.youtube.com/shorts/5rpE91drHrQ

Without it:
🔗 https://www.youtube.com/shorts/mDFg2lJParQ

The clicking noise in the second video sounds a lot like what you're experiencing. What’s confusing me is that, in v1.7.3, I can also hear RSSI queries in this condition—clicking twice per second.

VanceVagell, 2025-03-29:
Thanks for the additional tests. I tested 1.7.3 and 1.7.2 and find that this is intermittently a problem at least that far back. Sometimes there's no clicking/skipping at all, othertimes there is. Closing this bug out for now since it's inaccurate as currently described, but we should keep an eye on this and see if we can reproduce it more readily so we can fix it.

VanceVagell, 2025-04-13:
I went back to 1.6.x releases before the audio changes and still hear this. So I'm not sure what's going on with it.

Closed 2025-03-29.

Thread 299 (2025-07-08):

NeoPixel glitches on 2.0c board when powered from laptop

dkaukov, 2025-07-08:
**What was found**:

* The NeoPixel data line has a 100 Ω resistor and a 2.2 nF cap (C13) to ground — meant as a low-pass filter.
* That filter cuts off around 723 kHz, which is too close to the NeoPixel’s 800 kHz signal.
* On top of that, ESP32 sends 3.3 V data, which is borderline.
* When plugged into a laptop, the USB voltage is a bit higher (5.1 V), which raises the NeoPixel’s threshold for "HIGH" — and now the signal sometimes doesn’t register.

**Fix**:
Removed C13 → NeoPixel works fine again even from the laptop.

I would suggest reducing C12/C13 to 100–220 pF — it’ll still help with high-frequency harmonics but won’t distort the NeoPixel timing.

SmittyHalibut, 2025-07-08:
Agreed.  100pF is a good choice.  This was on 2.0c?  I think I found and already fixed this on v2.1 actually; I ended up using a different neopixel chip that was much less tolerant of this problem.

SmittyHalibut, 2025-07-30:
Removed the filter entirely.  It's really not needed.

v2.0e PR incoming.  It mentions this ticket, so it should be linked soon. (I haven't submitted it yet, so I don't have a PR number.)

Resolving.

Closed 2025-07-30.

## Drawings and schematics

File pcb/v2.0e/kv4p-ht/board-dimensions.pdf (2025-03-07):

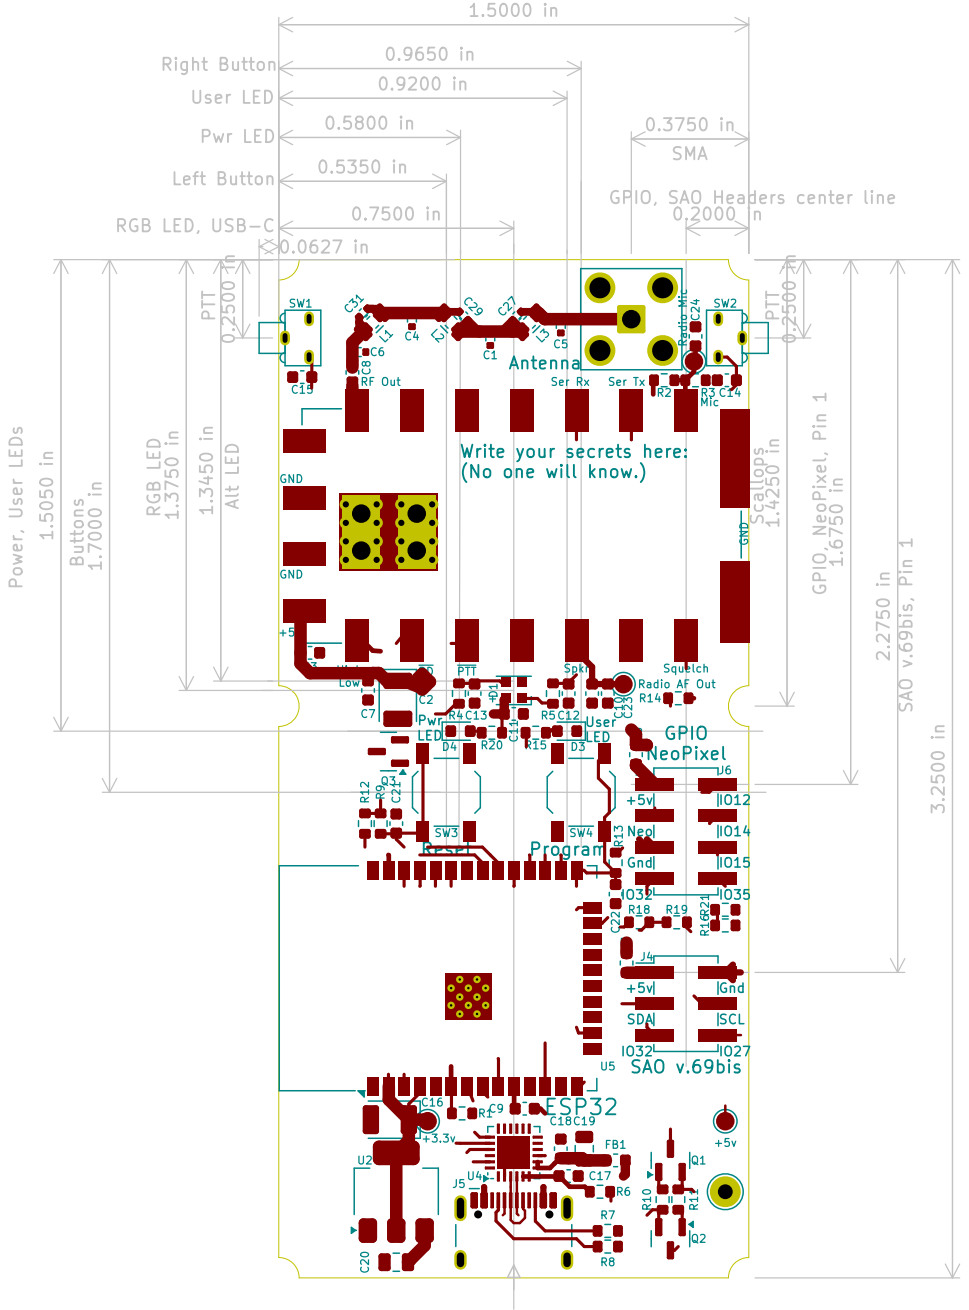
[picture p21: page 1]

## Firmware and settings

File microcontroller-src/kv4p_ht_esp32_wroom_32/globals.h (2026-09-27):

/*
KV4P-HT (see http://kv4p.com)
Copyright (C) 2026 Vance Vagell

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
You should have received a copy of the GNU General Public License
along with this program.  If not, see <http://www.gnu.org/licenses/>.
*/
#pragma once

#include <Arduino.h>
#include <driver/adc.h>

// RF module types
enum RfModuleType : uint8_t {
  RF_SA818_VHF = 0,
  RF_SA818_UHF = 1,
};

// Firmware audio hardware stays at 48 kHz. Audio frames on USB are 16 kHz 4-bit ADPCM.
#define AUDIO_SAMPLE_RATE 48000
#define AUDIO_WIRE_SAMPLE_RATE 16000
// IMA WAV ADPCM mono blocks contain an odd sample count. A 128-byte block decodes to 249 samples.
#define AUDIO_FRAME_SAMPLES_WIRE 249
#define AUDIO_FRAME_SAMPLES_48K 747
#define AUDIO_FRAME_BYTES 128
#define AUDIO_RESAMPLE_RATIO 3
#define AUDIO_DSP_ALIGN16 __attribute__((aligned(16)))

static constexpr uint16_t TX_AUDIO_TIMEOUT_FRAMES = 50;
static constexpr uint32_t TX_AUDIO_TIMEOUT_MS =
  (uint32_t)TX_AUDIO_TIMEOUT_FRAMES * AUDIO_FRAME_SAMPLES_WIRE * 1000 / AUDIO_WIRE_SAMPLE_RATE;

inline uint32_t bluetoothDeviceId() {
  uint64_t mac = ESP.getEfuseMac();
  return (uint32_t)((mac >> 24) & 0xFFFFFF);
}

inline void formatBluetoothDeviceName(char *out, size_t outSize) {
  snprintf(out, outSize, "kv4p-%06X", bluetoothDeviceId());
}

// AX.25 I2S tail lets the final samples drain from the six 512-sample DMA buffers.
static constexpr size_t TX_AFSK_BLOCK_SAMPLES = 256;
static constexpr float TX_AFSK_GAIN = 0.8f;
static constexpr float TX_AFSK_TAIL_SILENCE_MS = 70.0f;

// Maximum length of the frame
#define PROTO_MTU 2048

// KISS DATA carries an AX.25 frame without its on-air FCS.  APRS limits the
// AX.25 information field to 256 octets; the AX.25 address field permits a
// destination, source, and up to eight digipeaters.
static constexpr size_t AX25_MAX_ADDRESS_FIELDS = 10;
static constexpr size_t AX25_ADDRESS_FIELD_LEN = 7;
static constexpr size_t AX25_UI_HEADER_LEN = 2; // Control + PID
static constexpr size_t APRS_MAX_INFORMATION_FIELD_LEN = 256;
static constexpr size_t AX25_MAX_KISS_DATA_LEN =
  AX25_MAX_ADDRESS_FIELDS * AX25_ADDRESS_FIELD_LEN + AX25_UI_HEADER_LEN +
  APRS_MAX_INFORMATION_FIELD_LEN;

// Offset to make up for fact that sampling is slightly slower than requested, and we don't want underruns.
// But if this is set too high, then we get audio skips instead of underruns. So there's a sweet spot.
#define SAMPLING_RATE_OFFSET 0

// I2S audio sampling stuff
#define I2S_ADC_UNIT    ADC_UNIT_1
#define I2S_ADC_CHANNEL ADC1_CHANNEL_6

// Connections to radio module
#define DEFAULT_PIN_RF_RXD    16
#define DEFAULT_PIN_RF_TXD    17
#define DEFAULT_PIN_AUDIO_OUT 25  // This constant not used, just here for reference. GPIO 25 is implied by use of I2S_DAC_CHANNEL_RIGHT_EN.
#define DEFAULT_PIN_AUDIO_IN  34  // If this is changed, you may need to manually edit adc1_config_channel_atten() below too.
#define DEFAULT_PIN_PTT       18  // Keys up the radio module
#define DEFAULT_PIN_PD        19
#define DEFAULT_PIN_SQ        32  //
#define DEFAULT_PIN_PHYS_PTT1 5   // Optional. Buttons may be attached to either or both of this and next pin. They behave the same.
#define DEFAULT_PIN_PHYS_PTT2 33  // Optional. See above.
#define DEFAULT_PIN_LED        2  // Built in LED
#define DEFAULT_PIN_PIXELS    13  // NeoPixel data pin
#define DEFAULT_PIN_HL        -1  // High/Low pin for the radio module. -1 means not used.
#define DEFAULT_VOLUME         8  // Default SA8x8 module audio volume

#define DEFAULT_ADC_BIAS_VOLTAGE     1.75
#define DEFAULT_ADC_ATTENUATION      ADC_ATTEN_DB_12
#define DEFAULT_RF_MODULE_TYPE       RF_SA818_VHF
#define DEFAULT_VOLUME               8
#define DEFAULT_STOPPED_COLOR        {0, 32, 0}

// Mode of the app, which is essentially a state machine
enum Mode {
  MODE_TX,
  MODE_RX,
  MODE_STOPPED
};
Mode mode = MODE_STOPPED;

// Current SQ status
bool squelched = false;
float txAudioLevel = 0.0f;


// Forward declarations
void setMode(Mode newMode);
Mode rxIdleMode();
void sendCurrentDeviceState();
void markDeviceStateDirty();
bool freeDv2400bEnabled();

struct [[gnu::packed]] RGBColor {
  uint8_t red;
  uint8_t green;
  uint8_t blue;
};

struct [[gnu::packed]] PinConfig {
  int8_t pinSq;
  int8_t pinRfModuleRxd;
  int8_t pinRfModuleTxd;
  int8_t pinAudioOut;
  int8_t pinAudioIn;
  int8_t pinPtt;
  int8_t pinPd;
  int8_t pinPttPhys1;
  int8_t pinPttPhys2;
  int8_t pinLed;
  int8_t pinPixels;
  int8_t pinHl;
};

struct [[gnu::packed]] FeatureFlags {
  bool hasHL: 1; // High/Low pin
  bool hasPhysPTT: 1; // PTT pin
};

struct [[gnu::packed]] HWConfig {
  PinConfig pins;
  FeatureFlags features;
  float adcBias;
  adc_atten_t adcAttenuation;
  uint8_t volume;
  RGBColor stoppedColor;
  RfModuleType rfModuleType;
};

HWConfig hw = {
  .pins = {
    .pinSq = DEFAULT_PIN_SQ,
    .pinRfModuleRxd = DEFAULT_PIN_RF_RXD,
    .pinRfModuleTxd = DEFAULT_PIN_RF_TXD,
    .pinAudioOut = DEFAULT_PIN_AUDIO_OUT,
    .pinAudioIn = DEFAULT_PIN_AUDIO_IN,
    .pinPtt = DEFAULT_PIN_PTT,
    .pinPd = DEFAULT_PIN_PD,
    .pinPttPhys1 = DEFAULT_PIN_PHYS_PTT1,
    .pinPttPhys2 = DEFAULT_PIN_PHYS_PTT2,
    .pinLed = DEFAULT_PIN_LED,
    .pinPixels = DEFAULT_PIN_PIXELS,
    .pinHl = DEFAULT_PIN_HL,
  },
  .features = {
    .hasHL = (DEFAULT_PIN_HL != -1),
    .hasPhysPTT = (DEFAULT_PIN_PHYS_PTT1 != -1 || DEFAULT_PIN_PHYS_PTT2 != -1)
  },
  .adcBias = DEFAULT_ADC_BIAS_VOLTAGE,
  .adcAttenuation = DEFAULT_ADC_ATTENUATION,
  .volume = DEFAULT_VOLUME,
  .stoppedColor = DEFAULT_STOPPED_COLOR,
  .rfModuleType = DEFAULT_RF_MODULE_TYPE
};

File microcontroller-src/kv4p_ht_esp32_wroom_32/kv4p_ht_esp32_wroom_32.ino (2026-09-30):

/*
KV4P-HT (see http://kv4p.com)
Copyright (C) 2026 Vance Vagell

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
You should have received a copy of the GNU General Public License
along with this program.  If not, see <http://www.gnu.org/licenses/>.
*/

#include <Arduino.h>
#include <BluetoothSerial.h>
#include <DRA818.h>
#include <esp_system.h>
#include <esp_task_wdt.h>
#include "globals.h"
#include "debug.h"
#include "BluedroidBleKissGattStream.h"
#include "led.h"
#include "protocol.h"
#include "state.h"
#include "rxAudio.h"
#include "txAudio.h"
#include "ax25TxScheduler.h"
#include "buttons.h"
#include "utils.h"
#include "board.h"

const uint16_t FIRMWARE_VER = 17;

const uint32_t RSSI_REPORT_INTERVAL_MS = 100;
const uint32_t DEVICE_STATE_REPORT_INTERVAL_MS = 500;
const uint16_t USB_BUFFER_SIZE = 1024*2;
const uint16_t BLE_KISS_WINDOW_SIZE = 4096;

using Kv4pBleKissStream = BluedroidBleKissGattStream<4096, 512, 32>;

char bleKissDeviceName[12] = "kv4p";

Kv4pBleKissStream::Config bleKissConfig() {
  Kv4pBleKissStream::Config cfg;
  cfg.deviceName = bleKissDeviceName;
  cfg.preferredMtu = 247;
  cfg.requireNotifySubscription = true;
  cfg.maxNotifyChunksPerLoop = 4;
  cfg.minNotifyIntervalMs = 0;
  cfg.notifyFailureBackoffMs = 25;
  cfg.writeQueueWaitMs = 15;
  cfg.txPower = ESP_PWR_LVL_P7;
  return cfg;
}

DRA818 sa818_vhf(&Serial2, SA818_VHF);
DRA818 sa818_uhf(&Serial2, SA818_UHF);
DRA818 &sa818 = sa818_vhf;
BluetoothSerial SerialBT;
Kv4pBleKissStream bleKissStream(bleKissConfig());
bool bluetoothStarted = false;
bool bluetoothProtocolConnected = false;
bool bleKissProtocolConnected = false;
KissParser bluetoothParser(protocolBtSession, &handleCommands, &handleAx25Data,
  &handleKissParameter);
KissParser bleKissParser(protocolBleSession, &handleCommands, &handleAx25Data,
  &handleKissParameter);
Ax25TxScheduler ax25TxScheduler;
// SoftSQ needs its 250 ms close/open interval after a retune before its raw
// HF-noise carrier decision is reliable. Keep a small loop-timing margin.
static constexpr uint16_t AX25_OVERRIDE_RX_SETTLE_MS = 260;
bool ax25OverrideChannelPrepared = false;
uint32_t ax25OverrideChannelReadyAt = 0;

float moduleMinRadioFreq() {
  return hw.rfModuleType == RF_SA818_UHF ? 400.0f : 134.0f;
}

float moduleMaxRadioFreq() {
  return hw.rfModuleType == RF_SA818_UHF ? 480.0f : 174.0f;
}

float moduleDefaultRadioFreq() {
  return hw.rfModuleType == RF_SA818_UHF ? 435.0f : 144.0f;
}

float clampModuleRadioFreq(float freq) {
  return min(max(freq, moduleMinRadioFreq()), moduleMaxRadioFreq());
}

bool isModuleRadioFreq(float freq) {
  return freq >= moduleMinRadioFreq() && freq <= moduleMaxRadioFreq();
}

void loadPersistedRadioState() {
  prefs.begin("radio", true);
  uint16_t flags = desiredState.flags;
  flags &= ~(HOST_STATE_RADIO_CONFIG_VALID | HOST_STATE_HIGH_POWER | HOST_STATE_RSSI_ENABLED | HOST_STATE_FILTER_PRE | HOST_STATE_FILTER_HIGH | HOST_STATE_FILTER_LOW | HOST_STATE_TX_ALLOWED);
  flags |= HOST_STATE_RADIO_CONFIG_VALID;
  desiredState.bw = prefs.getUChar("bw", DRA818_25K);
  desiredState.freq_tx = prefs.getFloat("freq_tx", moduleDefaultRadioFreq());
  desiredState.freq_rx = prefs.getFloat("freq_rx", moduleDefaultRadioFreq());
  desiredState.ctcss_tx = prefs.getUChar("ctcss_tx", 0);
  desiredState.squelch = prefs.getUChar("squelch", 0);
  desiredState.ctcss_rx = prefs.getUChar("ctcss_rx", 0);
  desiredState.memoryId = prefs.getInt("memory_id", -1);
  if (!isModuleRadioFreq(desiredState.freq_tx) || !isModuleRadioFreq(desiredState.freq_rx)) {
    desiredState.freq_tx = clampModuleRadioFreq(desiredState.freq_tx);
    desiredState.freq_rx = clampModuleRadioFreq(desiredState.freq_rx);
    desiredState.memoryId = -1;
  }
  if (prefs.getBool("high", true)) {
    flags |= HOST_STATE_HIGH_POWER;
  }
  if (prefs.getBool("rssi", true)) {
    flags |= HOST_STATE_RSSI_ENABLED;
  }
  if (prefs.getBool("flt_pre", false)) {
    flags |= HOST_STATE_FILTER_PRE;
  }
  if (prefs.getBool("flt_high", false)) {
    flags |= HOST_STATE_FILTER_HIGH;
  }
  if (prefs.getBool("flt_low", false)) {
    flags |= HOST_STATE_FILTER_LOW;
  }
  if (prefs.getBool("tx_allowed", false)) {
    flags |= HOST_STATE_TX_ALLOWED;
  }
  desiredState.flags = flags;
  softSquelchEffect.setDeadbandLevel(desiredState.squelch);
  desiredState.sequence = 0;
  desiredState.flags &= ~(HOST_STATE_PTT_REQUESTED | HOST_STATE_SESSION_FLAG_MASK);
  appliedState.memoryId = desiredState.memoryId;
  persistedState = desiredState;
  prefs.end();
}

uint16_t persistedStateFlags(uint16_t flags) {
  return flags & (HOST_STATE_RADIO_CONFIG_VALID | HOST_STATE_HIGH_POWER | HOST_STATE_RSSI_ENABLED | HOST_STATE_FILTER_PRE | HOST_STATE_FILTER_HIGH | HOST_STATE_FILTER_LOW | HOST_STATE_TX_ALLOWED);
}

bool persistedRadioStateMatchesDesired() {
  return persistedState.bw == desiredState.bw
    && persistedState.freq_tx == desiredState.freq_tx
    && persistedState.freq_rx == desiredState.freq_rx
    && persistedState.ctcss_tx == desiredState.ctcss_tx
    && persistedState.squelch == desiredState.squelch
    && persistedState.ctcss_rx == desiredState.ctcss_rx
    && persistedState.memoryId == desiredState.memoryId
    && persistedStateFlags(persistedState.flags) == persistedStateFlags(desiredState.flags);
}

void savePersistedRadioStateIfChanged() {
  if (persistedRadioStateMatchesDesired()) {
    return;
  }
  prefs.begin("radio", false);
  prefs.putUChar("bw", desiredState.bw);
  prefs.putFloat("freq_tx", desiredState.freq_tx);
  prefs.putFloat("freq_rx", desiredState.freq_rx);
  prefs.putUChar("ctcss_tx", desiredState.ctcss_tx);
  prefs.putUChar("squelch", desiredState.squelch);
  prefs.putUChar("ctcss_rx", desiredState.ctcss_rx);
  prefs.putInt("memory_id", desiredState.memoryId);
  prefs.putBool("high", (desiredState.flags & HOST_STATE_HIGH_POWER) != 0);
  prefs.putBool("rssi", (desiredState.flags & HOST_STATE_RSSI_ENABLED) != 0);
  prefs.putBool("flt_pre", (desiredState.flags & HOST_STATE_FILTER_PRE) != 0);
  prefs.putBool("flt_high", (desiredState.flags & HOST_STATE_FILTER_HIGH) != 0);
  prefs.putBool("flt_low", (desiredState.flags & HOST_STATE_FILTER_LOW) != 0);
  prefs.putBool("tx_allowed", (desiredState.flags & HOST_STATE_TX_ALLOWED) != 0);
  prefs.end();
  persistedState = desiredState;
}

uint8_t getFirmwareFeatures() {
  return (hw.features.hasHL ? FEATURE_HAS_HL : 0)
    | (hw.features.hasPhysPTT ? FEATURE_HAS_PHY_PTT : 0)
    | FEATURE_HAS_ESP32_AFSK
    | FEATURE_HAS_FREEDV_2400B;
}

Mode rxIdleMode() {
  return protocolAnySessionFlag(HOST_STATE_RX_AUDIO_OPEN) ? MODE_RX : MODE_STOPPED;
}

uint16_t desiredFilterFlags() {
  return desiredState.flags & (HOST_STATE_FILTER_PRE | HOST_STATE_FILTER_HIGH | HOST_STATE_FILTER_LOW);
}

bool txAllowedByHost() {
  return desiredState.flags & HOST_STATE_TX_ALLOWED;
}

bool freeDv2400bEnabled() {
  return desiredState.flags & HOST_STATE_FREEDV_2400B;
}

uint16_t deviceStateFlags(uint16_t sessionFlags) {
  uint16_t flags = desiredState.flags;
  flags |= sessionFlags & HOST_STATE_SESSION_FLAG_MASK;
  if (isPhysPttDown) {
    flags |= DEVICE_STATE_PHYS_PTT_DOWN;
  }
  if (mode == MODE_TX) {
    flags |= DEVICE_STATE_TX_ACTIVE;
  }
  if (squelched) {
    flags |= DEVICE_STATE_SQUELCHED;
  }
  return flags;
}

uint8_t deviceMode() {
  switch (mode) {
    case MODE_TX:
      return DEVICE_MODE_TX;
    case MODE_RX:
      return DEVICE_MODE_RX;
    case MODE_STOPPED:
    default:
      return DEVICE_MODE_STOPPED;
  }
}

DeviceState currentDeviceState(uint16_t sessionFlags = 0) {
  return {
    .appliedSequence = desiredState.sequence,
    .memoryId = appliedState.memoryId,
    .flags = deviceStateFlags(sessionFlags),
    .bw = appliedState.bw,
    .freq_tx = appliedState.freq_tx,
    .freq_rx = appliedState.freq_rx,
    .ctcss_tx = appliedState.ctcss_tx,
    .squelch = appliedState.squelch,
    .ctcss_rx = appliedState.ctcss_rx,
    .radioModuleStatus = radioModuleStatus,
    .mode = deviceMode(),
    .lastError = lastDeviceStateError,
    .latestRssi = latestRssi,
  };
}

void sendCurrentDeviceState() {
  bool sent = false;
  if (protocolSessionConnected(protocolUsbSession) && (protocolUsbSession.flags & HOST_STATE_ENABLE_STATUS_REPORTS)) {
    sendDeviceState(*protocolUsbSession.stream, currentDeviceState(protocolUsbSession.flags));
    sent = true;
  }
  if (protocolHasBtSession() && (protocolBtSession.flags & HOST_STATE_ENABLE_STATUS_REPORTS)) {
    sendDeviceState(*protocolBtSession.stream, currentDeviceState(protocolBtSession.flags));
    sent = true;
  }
  if (protocolHasBleSession() && (protocolBleSession.flags & HOST_STATE_ENABLE_STATUS_REPORTS)) {
    sendDeviceState(*protocolBleSession.stream, currentDeviceState(protocolBleSession.flags));
    sent = true;
  }
  if (sent) {
    deviceStateDirty = false;
  }
}

void markDeviceStateDirty() {
  deviceStateDirty = true;
}

bool radioConfigChanged() {
  return !radioConfigApplied
    || appliedState.bw != desiredState.bw
    || appliedState.freq_tx != desiredState.freq_tx
    || appliedState.freq_rx != desiredState.freq_rx
    || appliedState.ctcss_tx != desiredState.ctcss_tx
    || appliedState.squelch != desiredState.squelch
    || appliedState.ctcss_rx != desiredState.ctcss_rx
    || appliedState.memoryId != desiredState.memoryId;
}

void drainRadioSerial() {
  while (Serial2.available()) {
    Serial2.read();
  }
}

void reconcileDesiredState(bool sendReport = true) {
  lastDeviceStateError = DEVICE_STATE_ERROR_NONE;
  bool wantHigh = desiredState.flags & HOST_STATE_HIGH_POWER;
  if (hw.features.hasHL) {
    digitalWrite(hw.pins.pinHl, wantHigh ? LOW : HIGH);
  }
  rssiOn = desiredState.flags & HOST_STATE_RSSI_ENABLED;

  uint16_t filterFlags = desiredFilterFlags();
  uint16_t appliedFilterFlags = appliedState.flags & (HOST_STATE_FILTER_PRE | HOST_STATE_FILTER_HIGH | HOST_STATE_FILTER_LOW);
  if (!filtersApplied || filterFlags != appliedFilterFlags) {
    drainRadioSerial();
    while (!sa818.filters((filterFlags & HOST_STATE_FILTER_PRE), false, false)) {
      lastDeviceStateError = DEVICE_STATE_ERROR_FILTERS_FAILED;
      esp_task_wdt_reset();
    }
    rxDownsample.setFilters((filterFlags & HOST_STATE_FILTER_HIGH) != 0,
                            (filterFlags & HOST_STATE_FILTER_LOW) != 0);
    appliedState.flags = (appliedState.flags & ~(HOST_STATE_FILTER_PRE | HOST_STATE_FILTER_HIGH | HOST_STATE_FILTER_LOW)) | filterFlags;
    filtersApplied = true;
  }

  if ((desiredState.flags & HOST_STATE_RADIO_CONFIG_VALID) && radioConfigChanged()) {
    drainRadioSerial();
    while (!sa818.group(desiredState.bw, desiredState.freq_tx, desiredState.freq_rx, desiredState.ctcss_tx, 0, 0)) {
      lastDeviceStateError = DEVICE_STATE_ERROR_RADIO_CONFIG_FAILED;
      esp_task_wdt_reset();
    }
    appliedState.bw = desiredState.bw;
    appliedState.freq_tx = desiredState.freq_tx;
    appliedState.freq_rx = desiredState.freq_rx;
    appliedState.ctcss_tx = desiredState.ctcss_tx;
    appliedState.squelch = desiredState.squelch;
    softSquelchEffect.setDeadbandLevel(appliedState.squelch);
    freeDvSquelch.setLevel(appliedState.squelch);
    if (freeDv2400bEnabled()) squelched = !freeDvSquelch.open();
    softSquelchEffect.setCtcssTone(desiredState.ctcss_rx);
    appliedState.ctcss_rx = desiredState.ctcss_rx;
    appliedState.memoryId = desiredState.memoryId;
    appliedState.flags |= HOST_STATE_RADIO_CONFIG_VALID;
    radioConfigApplied = true;
  }

  if ((desiredState.flags & HOST_STATE_PTT_REQUESTED) && txAllowedByHost()) {
    setMode(MODE_TX);
  } else {
    setMode(rxIdleMode());
  }
  savePersistedRadioStateIfChanged();
  if (sendReport) {
    markDeviceStateDirty();
  }
}

void setMode(Mode newMode) {
  if (mode == newMode) {
    return;
  }
  freeDvRx.reset();
  freeDvTx.reset();
  mode = newMode;
  markDeviceStateDirty();
  switch (mode) {
    case MODE_STOPPED:
      _LOGI("MODE_STOPPED");
      digitalWrite(hw.pins.pinPtt, HIGH);
      endI2STx();
      initI2SRx();
    break;
    case MODE_RX:
      _LOGI("MODE_RX");
      digitalWrite(hw.pins.pinPtt, HIGH);
      endI2STx();
      initI2SRx();
    break;
    case MODE_TX:
      _LOGI("MODE_TX");
      txStartTime = millis();
      txWatchDog.reset(txStartTime);
      digitalWrite(hw.pins.pinPtt, LOW);
      endI2SRx();
      initI2STx();
    break;
  }
}

void setup() {
  boardSetup();
  loadPersistedRadioState();
  // Communication with Android via USB cable
  Serial.setRxBufferSize(USB_BUFFER_SIZE);
  Serial.setTxBufferSize(USB_BUFFER_SIZE);
  protocolUsbSession.windowSize = USB_BUFFER_SIZE;
  Serial.begin(115200);
  Serial.println();
  Serial.println("===== kv4p serial output =====");
  Serial.println("This port will emit binary data using the kv4p protocol.");
  Serial.println("You will see watchdog resets — this is expected behavior.");
  Serial.println("Use `logcat` or a kv4p decoder to view readable logs.");
  Serial.println("More info: https://github.com/VanceVagell/kv4p-ht/blob/main/microcontroller-src/kv4p_ht_esp32_wroom_32/readme.md");
  Serial.println("==============================");
  char bluetoothDeviceName[12];
  formatBluetoothDeviceName(bluetoothDeviceName, sizeof(bluetoothDeviceName));
  bluetoothStarted = SerialBT.begin(bluetoothDeviceName);
  if (bluetoothStarted) {
    protocolBtSession.stream = &SerialBT;
    protocolBtSession.windowSize = USB_BUFFER_SIZE;
  } else {
    Serial.println("Classic Bluetooth init failed");
  }
  formatBluetoothDeviceName(bleKissDeviceName, sizeof(bleKissDeviceName));
  protocolBleSession.stream = &bleKissStream;
  protocolBleSession.windowSize = BLE_KISS_WINDOW_SIZE;
  if (!bleKissStream.begin()) {
    Serial.println("BLE KISS init failed");
  } else {
    Serial.print("BLE KISS advertising as ");
    Serial.println(bleKissDeviceName);
  }
  // Configure watch dog timer (WDT), which will reset the system if it gets stuck somehow.
  esp_task_wdt_init(10, true);  // Reboot if locked up for a bit
  esp_task_wdt_add(NULL);       // Add the current task to WDT watch
  buttonsSetup();
  // Set up radio module defaults
  pinMode(hw.pins.pinPd, OUTPUT);
  digitalWrite(hw.pins.pinPd, HIGH);  // Power on
  pinMode(hw.pins.pinPtt, OUTPUT);
  digitalWrite(hw.pins.pinPtt, HIGH);  // Rx
  pinMode(hw.pins.pinSq, INPUT);
  if (hw.features.hasHL) {
    pinMode(hw.pins.pinHl, OUTPUT);
    digitalWrite(hw.pins.pinHl, LOW);  // High power
  }
  // Communication with DRA818V radio module via GPIO pins
  Serial2.begin(9600, SERIAL_8N1, hw.pins.pinRfModuleRxd, hw.pins.pinRfModuleTxd);
  Serial2.setTimeout(10);  // Very short so we don't tie up rx audio while reading from radio module (responses are tiny so this is ok)
  //
  debugSetup();
  // Begin in STOPPED mode
  squelched = true;
  setMode(MODE_STOPPED);
  initI2SRx();
  ledSetup();
  initRadio((desiredState.flags & HOST_STATE_HIGH_POWER) != 0);
  if (radioModuleStatus == RADIO_MODULE_FOUND) {
    reconcileDesiredState(false);
  }
  sendHello(protocolUsbSession, FIRMWARE_VER, radioModuleStatus, hw.rfModuleType, moduleMinRadioFreq(), moduleMaxRadioFreq(), getFirmwareFeatures(), currentDeviceState(protocolUsbSession.flags));
  _LOGI("Setup is finished");
}

void initRadio(bool isHigh) {
  if (hw.rfModuleType == RF_SA818_UHF) {
    sa818 = sa818_uhf;
  } else {
    sa818 = sa818_vhf;
  }
  if (hw.features.hasHL) {
    digitalWrite(hw.pins.pinHl, isHigh ? LOW : HIGH);
  }
  radioModuleStatus = RADIO_MODULE_NOT_FOUND;
  // The sa818.handshake() has 3 retries internally with 2 seconds between each attempt.
  // We have 3 retries on top of that, so total wait time is up to 20 seconds.
  // This should allow the radio module to power up and respond.
  for (int i = 0; i < 3; i++) {
    esp_task_wdt_reset();
    if (sa818.handshake()) { //Check if radio responded to handshake attempt
      radioModuleStatus = RADIO_MODULE_FOUND;
      sa818.volume(hw.volume);
      sa818.filters(false, false, false);
      break;
    }
  }
}

void handleCommands(ProtocolSession &session, RcvCommand command, uint8_t *params, size_t param_len) {
  switch (command) {
    case COMMAND_HOST_TX_AUDIO:
      if (mode == MODE_TX && !freeDv2400bEnabled()) {
        processTxAudio(params, param_len);
        esp_task_wdt_reset();
      }
      break;
    case COMMAND_HOST_TX_DIGITAL:
      // The command ID unambiguously selects the digital path. Do not also
      // gate it on the session flag: PTT and session-state snapshots travel
      // independently and the first voice frame can win that race.
      if (mode == MODE_TX && freeDv2400bEnabled()) {
        processTxDigital(params, param_len);
        esp_task_wdt_reset();
      }
      break;
    case COMMAND_HOST_DESIRED_STATE:
      if (param_len == sizeof(HostDesiredState)) {
        HostDesiredState incomingState;
        memcpy(&incomingState, params, sizeof(HostDesiredState));
        uint16_t oldSessionFlags = session.flags;
        session.flags = incomingState.flags & HOST_STATE_SESSION_FLAG_MASK;
        bool sessionFlagsChanged = oldSessionFlags != session.flags;
        // Desired-state sequence is global across transports; hosts must sync from
        // DeviceState.appliedSequence before sending their next update.
        bool globalStateChanged = incomingState.sequence > desiredState.sequence;
        if (globalStateChanged) {
          const bool freeDvModeChanged =
              ((incomingState.flags ^ desiredState.flags) &
               HOST_STATE_FREEDV_2400B) != 0;
          desiredState = incomingState;
          desiredState.flags &= HOST_STATE_GLOBAL_FLAG_MASK;
          if (freeDvModeChanged) {
            latestRssi = 0;
            freeDvSquelch.reset();
            squelched = freeDv2400bEnabled()
                ? !freeDvSquelch.open()
                : !softSquelchEffect.isSoftOpen();
          }
        }
        if (sessionFlagsChanged || globalStateChanged) {
          reconcileDesiredState();
        }
        esp_task_wdt_reset();
      }
      break;
    case COMMAND_HOST_TX_AX25:
      if (param_len > sizeof(Ax25TxOverride) && txAllowedByHost()) {
        Ax25TxOverride txOverride;
        memcpy(&txOverride, params, sizeof(txOverride));
        size_t ax25Len = param_len - sizeof(txOverride);
        if (isModuleRadioFreq(txOverride.freqTx) && ax25Len <= AX25_MAX_KISS_DATA_LEN
            && !ax25TxScheduler.enqueue(params + sizeof(txOverride), ax25Len, &txOverride)) {
          _LOGW("AX.25 TX queue full; dropped frequency-override job");
        }
      }
      break;
  }
}

void handleAx25Data(uint8_t *ax25, size_t ax25_len) {
  if (ax25_len > 0 && ax25_len <= AX25_MAX_KISS_DATA_LEN && txAllowedByHost()) {
    if (!ax25TxScheduler.enqueue(ax25, ax25_len)) {
      _LOGW("AX.25 TX queue full; dropped KISS DATA frame");
    }
  }
}

void handleKissParameter(uint8_t command, uint8_t value) {
  if (command == KISS_CMD_TXDELAY) ax25TxScheduler.setTxDelay(value);
  else if (command == KISS_CMD_PERSIST) ax25TxScheduler.setPersist(value);
  else if (command == KISS_CMD_SLOTTIME) ax25TxScheduler.setSlotTime(value);
}

void prepareAx25TxOverrideChannel(const Ax25TxOverride &txOverride) {
  drainRadioSerial();
  // Tune RX to the packet's target before carrier sense. The normal radio
  // configuration is deliberately marked stale so it is restored after TX.
  while (!sa818.group(txOverride.bw, txOverride.freqTx, txOverride.freqTx, txOverride.ctcssTx, 0, 0)) {
    lastDeviceStateError = DEVICE_STATE_ERROR_RADIO_CONFIG_FAILED;
    esp_task_wdt_reset();
  }
  radioConfigApplied = false;
  ax25OverrideChannelPrepared = true;
  ax25OverrideChannelReadyAt = millis() + AX25_OVERRIDE_RX_SETTLE_MS;
}

// Android sends COMMAND_HOST_TX_AX25 for every APRS packet, including a
// beacon on the channel that is already configured. Avoid an unnecessary
// SA818 group command in that case: it would otherwise also force a second
// group command immediately after PTT is released.
bool ax25OverrideMatchesActiveChannel(const Ax25TxOverride &txOverride) {
  static constexpr float FREQ_MATCH_EPSILON_MHZ = 0.0001f;
  return radioConfigApplied
    && (desiredState.flags & HOST_STATE_RADIO_CONFIG_VALID)
    && txOverride.bw == desiredState.bw
    && txOverride.ctcssTx == desiredState.ctcss_tx
    && fabsf(txOverride.freqTx - desiredState.freq_tx) < FREQ_MATCH_EPSILON_MHZ
    && fabsf(txOverride.freqTx - desiredState.freq_rx) < FREQ_MATCH_EPSILON_MHZ;
}
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
void loop() {
  squelchLoop();
  debugLoop();
  ledLoop();
  buttonsLoop();
  protocolLoop();
  bluetoothLoop();
  bleKissLoop();
  rxAudioLoop();
  ax25TxLoop();
  txAudioLoop();
  rssiLoop();
  deviceStateLoop();
}

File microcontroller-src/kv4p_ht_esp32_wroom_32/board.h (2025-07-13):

/*
KV4P-HT (see http://kv4p.com)
Copyright (C) 2025 Vance Vagell

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
You should have received a copy of the GNU General Public License
along with this program.  If not, see <http://www.gnu.org/licenses/>.
*/
#pragma once

#include <Arduino.h>
#include <Preferences.h>
#include "globals.h"
#include "debug.h"

// Legacy Hardware version detection
#define HW_VER_PIN_0  39  // 0xF0
#define HW_VER_PIN_1  36  // 0x0F

//  Hardware Version Summary (Legacy):
//  +-------------+------------+-----------------+-------------------------------------------------------------------+
//  | Version     | Squelch Pin| ADC Attenuation | Notes                                                             |
//  +-------------+------------+-----------------+-------------------------------------------------------------------+
//  | HW_VER_V1   | GPIO32     | 12dB            | Original version, full feature set                                |
//  | HW_VER_V2_0C| GPIO4      | 0dB             | Switched to GPIO4 for squelch and lower ADC input range (0–1.1V). |
//  | HW_VER_V2_0D| GPIO4      | 12dB            | Same squelch pin as V2.0C; ADC range restored to normal (~3.3V).  |
//  +-------------+------------+-----------------+-------------------------------------------------------------------+
#define HW_VER_V1     (0x00)
#define HW_VER_V2_0C  (0xFF)
#define HW_VER_V2_0D  (0xF0)
#define STRINGIFY(x) #x
#define TOSTRING(x) STRINGIFY(x)

typedef uint8_t hw_ver_t;  // This allows us to do a lot more in the future if we want.

Preferences prefs;

bool isHardwareConfigExists() {
  prefs.begin("hwconfig", true); // read-only
  bool exists = prefs.isKey("HWCONFIG");
  prefs.end();
  return exists;
} 

void loadHardwareConfig() {
  prefs.begin("hwconfig", true); // read-only
  hw.pins.pinRfModuleRxd   = prefs.getChar("PIN_RF_RXD",   DEFAULT_PIN_RF_RXD);
  hw.pins.pinRfModuleTxd   = prefs.getChar("PIN_RF_TXD",   DEFAULT_PIN_RF_TXD);
  hw.pins.pinAudioOut      = prefs.getChar("PIN_AUDIO_OUT",DEFAULT_PIN_AUDIO_OUT);
  hw.pins.pinAudioIn           = prefs.getChar("PIN_AUDIO_IN", DEFAULT_PIN_AUDIO_IN);
  hw.pins.pinPtt           = prefs.getChar("PIN_PTT",      DEFAULT_PIN_PTT);
  hw.pins.pinPd            = prefs.getChar("PIN_PD",       DEFAULT_PIN_PD);
  hw.pins.pinSq            = prefs.getChar("PIN_SQ",       DEFAULT_PIN_SQ);
  hw.pins.pinPttPhys1      = prefs.getChar("PIN_PHYS_PTT1",DEFAULT_PIN_PHYS_PTT1);
  hw.pins.pinPttPhys2      = prefs.getChar("PIN_PHYS_PTT2",DEFAULT_PIN_PHYS_PTT2);
  hw.pins.pinPixels        = prefs.getChar("PIN_PIXELS",   DEFAULT_PIN_PIXELS);
  hw.pins.pinLed           = prefs.getChar("PIN_LED",      DEFAULT_PIN_LED);
  hw.pins.pinHl            = prefs.getChar("PIN_HL",       DEFAULT_PIN_HL);
  hw.adcAttenuation        = (adc_atten_t) prefs.getChar("ADC_ATTEN",DEFAULT_ADC_ATTENUATION);
  hw.adcBias               = prefs.getString("ADC_BIAS", TOSTRING(DEFAULT_ADC_BIAS_VOLTAGE)).toFloat();
  prefs.getBytes("STOPPED_COLOR", &hw.stoppedColor, sizeof(RGBColor));
  hw.volume                = prefs.getUChar("VOLUME",       DEFAULT_VOLUME);
  hw.rfModuleType          = (RfModuleType) prefs.getUChar("RF_MODULE_TYPE", DEFAULT_RF_MODULE_TYPE);
  prefs.end();
}

void saveHardwareConfig() {
  prefs.begin("hwconfig", false); // read-write mode
  prefs.putBool("HWCONFIG",        true);
  prefs.putChar("PIN_RF_RXD",      hw.pins.pinRfModuleRxd);
  prefs.putChar("PIN_RF_TXD",      hw.pins.pinRfModuleTxd);
  prefs.putChar("PIN_AUDIO_OUT",   hw.pins.pinAudioOut);
  prefs.putChar("PIN_AUDIO_IN",    hw.pins.pinAudioIn);
  prefs.putChar("PIN_PTT",         hw.pins.pinPtt);
  prefs.putChar("PIN_PD",          hw.pins.pinPd);
  prefs.putChar("PIN_SQ",          hw.pins.pinSq);
  prefs.putChar("PIN_PHYS_PTT1",   hw.pins.pinPttPhys1);
  prefs.putChar("PIN_PHYS_PTT2",   hw.pins.pinPttPhys2);
  prefs.putChar("PIN_PIXELS",      hw.pins.pinPixels);
  prefs.putChar("PIN_LED",         hw.pins.pinLed);
  prefs.putChar("PIN_HL",          hw.pins.pinHl);
  prefs.putChar("ADC_ATTEN",       hw.adcAttenuation);
  prefs.putString("ADC_BIAS",String(hw.adcBias, 6));
  prefs.putBytes("STOPPED_COLOR",  &hw.stoppedColor, sizeof(RGBColor));
  prefs.putUChar("VOLUME",         hw.volume);
  prefs.putUChar("RF_MODULE_TYPE", hw.rfModuleType);
  prefs.end();
}

hw_ver_t getHardwareVersion() {
  pinMode(HW_VER_PIN_0, INPUT);
  pinMode(HW_VER_PIN_1, INPUT);
  hw_ver_t ver = 0x00;
  ver |= (digitalRead(HW_VER_PIN_0) == HIGH ? 0x0F : 0x00);
  ver |= (digitalRead(HW_VER_PIN_1) == HIGH ? 0xF0 : 0x00);
  return ver;
}
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

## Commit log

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2024-03-17 Remove need to ask for USB permission, no longer required now that we've indicated in the manifest that we use USB and which devices
2024-03-17 Fix out of bounds exception when there's a large incoming buffer in ESP32 app.
2024-03-30 Updates to try to improve stability of serial connection between devices, to make scanning work better. Still a WIP.
2024-04-07 Rewrite rx audio buffer and command handling to prevent microcontoller freeze-ups, presumably because of USB tx/rx contention with software-based CDC USB handler on single-thread.
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2024-04-09 Fix a couple bugs where MCU wouldn't update keepalive timer, and made the Android app prompt MCU immediately on start rather than waiting for bytes which may not come if MCU is waiting.
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2024-05-11 Fix incorrect naming on STL file, and add a missing one.
    [KV4P HT Case v1.5 - TOP.stl, KV4P HT Case v1.5 - USB CONNECTOR HOLDER.stl]
2024-06-10 First attempt at implementing I2S-based tx audio handling, only partially functional. Crashes when audio is received in ESP32 app from Android.
    [kv4p_ht_esp32_wroom_32.ino]
2024-06-12 Try reducing audio sampling rate to fix stutter on Android playback, it could be that the 921600 baud serial connection can't quite push through the data fast enough at 44kHz audio.
    [kv4p_ht_esp32_wroom_32.ino]
2024-06-13 The audio stuttering was harder to resolve than expected. I THINK it's finally resolved by sampling audio on ESP32 slightly faster than needed, I suspect it wasn't actually sampling at full 44.1kHz t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
    [kv4p_ht_esp32_wroom_32.ino]
2024-06-14 Pull the audio sampling rate offset out to a constant, and reduce it to the lowest value where we don't get pops or skips.
    [kv4p_ht_esp32_wroom_32.ino]
2024-06-16 Fix tx code for using I2S. It works! Still known bug where sometimes PTT down command isn't received.
    [kv4p_ht_esp32_wroom_32.ino]
2024-06-17 fix scanning, and further adjust SAMPLING_RATE_OFFSET in the ESP32 app to try to dial in audio sampling rate.
    [kv4p_ht_esp32_wroom_32.ino]
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2024-09-02 Somewhat broken checkpoint before making more data transmit changes, in case I need an intermediate rollback
    [kv4p_ht_esp32_wroom_32.ino]
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2024-09-15 Workaround to avoid having to do the massive Service refactoring right now. Instead, more gracefully stop/start important objects in onResume/onPause in each Activity. This fixes all the various race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
    [SettingsActivity.java]
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2024-09-21 Add version checking between Android app and ESP32 firmware to ensure compatibility. Also remove a few old directories in the Git repo to avoid people using incorrect old code or designs.
    [kv4p_ht_esp32_wroom_32.ino]
2024-09-22 Fix a bug where frequency wasn't properly tuned after app restart, and updated occurences of KV4P-HT to kv4p HT (just to match the logo style).
    [SettingsActivity.java]
2024-09-22 Rename app to match lowercase branding, and add a few guard conditions for thread executor null checks that could cause crash shortly after app starts.
    [SettingsActivity.java]
2024-09-29 Update app version in preparation for beta, and replace bgcode 3D file with STL (was a mistake).
    [Sleek KV4P HT stand.stl]
2024-10-01 Speculative fixes for a couple bugs found by Play Store automated testing on devices I don't have access to.
    [SettingsActivity.java]
2024-10-01 Another platform-specific bug fix, apparently the View wasn't available to show the snackbar from the previous bug fix, so I'm using a higher level context.
    [SettingsActivity.java]
2024-10-01 Trying to fix that platform specific snackbar bug again.
    [SettingsActivity.java]
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2024-10-17 Removing v1.6 PCB design which had very poor harmonic supression, and adding tentative v1.7 PCB design which attempts to resolve that issue.
    [BOM_kv4p-HT-ESP-WROOM-32_2024-10-08 (1).csv, BOM_kv4p-HT-ESP-WROOM-32_2024-10-16.csv, PickAndPlace_(New-filter)-PCB_KV4P-HT-ESP-WROOM-32_2024-10-08 (1).csv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]
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2024-10-27 Fix issue #64, where the tx and rx frequencies may be off by 100Hz because of an off-by-one error in string processing.
    [kv4p_ht_esp32_wroom_32.ino]
2024-10-28 New Thicker base (#65)
    Increased the base by .408 and depth of text and exported as single STL to avoid potential rejection from JCLP and other print farms.
    [KV4P HT Case Thicker Body.stl]
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2024-11-07 v2.0 hardware design (#86)
    * https://github.com/VanceVagell/kv4p-ht/issues/63 Work in Progress.
    * https://github.com/VanceVagell/kv4p-ht/issues/63 Work in progress.
    * Replacing dev board with native ESP32 module. WIP.
    * More work in progress. #63 Schematic is mostly done. Lots more on PCB.
    * More work on #63. Lots of changes.
    * Added GPIO header, buttons, power/gpio2 LEDs. #63
    * Ignoring KiCAD backup files that just keep piling up.
    * Almost ready to order prototypes! #63
    * Check-in all the production files, including csv's #63
    * Files as ordered by me from JLCPCB. #63
    * Source files for gerbers and csv I ordered, but I cahnged parameters from v1.8 to v2.0. #63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
    [bom.csv, designators.csv, kv4p-ht.kicad_pcb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]
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2024-11-09 v2.0b Fixes for manufacturing: via sizes, added SMA socket LCSC number. (#91)
    * Bumping to v2.0a, new gerber files. #63
    * v2.0b AS ORDERED. Increased via size for JLCPCB manufacturing. Added SMA socket to assembly. #63
    [bom.csv, kv4p-ht.kicad_pcb, kv4p-ht.kicad_sch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]
2024-11-09 Fix one of the 3d printer files which was just a URL, downloaded it and added a folder for it.
    [KV4P-HT Quad Lock Add-Ons.stl]
2024-11-16 Add support for extra precision in frequencies, like xxx.xxxx. Fixes issue #74. This requires a new firmware version be installed on the ESP32.
    [kv4p_ht_esp32_wroom_32.ino]
2024-11-16 Add new setting to let people choose a maximum frequencies, for regions where they have a 146MHz max. Fixes issue #18.
    [SettingsActivity.java]
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2024-12-03 Make screen stay on while using the app (user can always hit their power button to turn it off manually). Addresses issue #76.
    [SettingsActivity.java]
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2024-12-05 Fix bug in hiding and showing PTT button depending on frequency.
    [kv4p_ht_esp32_wroom_32.ino]
2024-12-05 Fix for a few crash bugs seen in the wild (via Play Console).
    [SettingsActivity.java]
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2024-12-06 [PCB] v2.0c (#129)
    * Small test program to validate v2 hardware. #88
    * v2.1 work. I think I'm done, waiting for comments from Vance. #88
    * Panelizing to meet JLCPCB's minimum 70x70mm dimensions. #88
    * A small board to test the LPF design. #88
    * Moved from Filter\ Test, so I can also make a UHF filter test. #22
    * Split Filter\ Test into VHF and UHF versions. Order VHF yesterday, UHF today. #22
    * De-bumping to v2.1. Sticking with v2.0c instead. #88
    * v2.0c release candidate. I'm about to order this.
    * Panelized for JLCPCB production. (They need 70x70mm.) #88
    * VNA measurements of LPF test boards. #88 and #22
    * Thanks to @jh4vsm for finding this bug. https://git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
    [UHF-Filter Test.kicad_pcb, UHF-Filter Test.kicad_sch, VHF-Filter Test.kicad_pcb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]
2024-12-10 Fix inductor sizes, more sturdy PTT switches, clarify silk screen around NeoPixel, split Panel out into its own production/ directory. (#131)
    * Panelized for JLCPCB production. (They need 70x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
    [bom.csv, designators.csv, kv4p-ht-PANEL.kicad_pcb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]
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2024-12-14 Add new mic gain option to settings. Resolves issue #82.
    [SettingsActivity.java]
2024-12-14 Add new settings to control rx and tx sampling rates, as well as an rx multipler (to account for varying ESP32 dev module ADC performance / clocks). Implements issue #138.
    [SettingsActivity.java, kv4p_ht_esp32_wroom_32.ino]
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2024-12-14 Add setting to change bandwidth narrow or wide. Implements issue #126.
    [SettingsActivity.java, kv4p_ht_esp32_wroom_32.ino]
2024-12-25 Revert "Add new settings to control rx and tx sampling rates, as well as an rx multipler (to account for varying ESP32 dev module ADC performance / clocks). Implements issue #138."
    This reverts commit b3433b7f3c6e2989ec6f5d87bb5c0f30d1006a25.
    [SettingsActivity.java, kv4p_ht_esp32_wroom_32.ino]
2024-12-25 Fix the bad audio bug on many ESP32s. The issue was caused by inferior USB chips on some ESP32s, and the fix was to use a lower baud and sampling rate, and some other minor USB and buffer tweaks. Thi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
    [kv4p_ht_esp32_wroom_32.ino]
2024-12-25 Reapply a few bug fixes that got clobbered in the prior rollback and changes.
    [kv4p_ht_esp32_wroom_32.ino]
2024-12-25 Forgot to update the firmware version to 4! fixed.
    [kv4p_ht_esp32_wroom_32.ino]
2024-12-26 fix function tuneTo, add string bandwitdth (#153)
    fix function tuneTo, add string bandwitdth
    I meet bug when build it on PlatformIO
    [kv4p_ht_esp32_wroom_32.ino]
2024-12-27 Adding 3 candidate board designs for PCB v1.8x, which include the new filter design suggested in issue #146, and a layout variant for 38-pin wide, 38-pin narrow, and 30-pin as in issue #59. These hav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
    [BOM_kv4p-HT-PCB-v1.8a_2024-12-26.csv, BOM_kv4p-HT-PCB-v1.8b_2024-12-26.csv, BOM_kv4p-HT-PCB-v1.8c_2024-12-26.csv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]
2024-12-29 Intermediate commit while working on adding S-meter. This has somewhat broken audio, as I'm not properly filtering RSSI data out of the audio stream.
    [kv4p_ht_esp32_wroom_32.ino]
2024-12-29 Candidate for complete S-meter implementation. Need to test on more kv4p HT builds to be sure it doesn't cause issues on other ESP32s, DRA vs. SA radios, or older Android phones.
    [kv4p_ht_esp32_wroom_32.ino]
2024-12-30 Complete implementation of APRS beaconing, as well as fixing chat message ack, and improving APRS decode success rate. Resolves issue #5.
    [SettingsActivity.java, kv4p_ht_esp32_wroom_32.ino]
2024-12-30 Increment version numbers in prep for release. Also add one more small check to prevent out-of-band AX.25 tx.
    [kv4p_ht_esp32_wroom_32.ino]
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2025-01-10 Small tweak to ensure that we don't try to read s-meter too aggressively in a failure scenario.
    [kv4p_ht_esp32_wroom_32.ino]
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2025-01-12 Fix for Rx mode stream parser
    [kv4p_ht_esp32_wroom_32.ino]
2025-01-12 Tweaks to PR to fix a couple small issues.
    [kv4p_ht_esp32_wroom_32.ino]
2025-01-12 Fix for Serial Command Parser in RX mode (#171)
    * Fix for Rx mode stream parser
    * Fixed comments
    [kv4p_ht_esp32_wroom_32.ino]
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2025-01-12 Fixes bug #172 by waiting for DRA818 to confirm it has applied squelch and/or filters before continuing.
    [kv4p_ht_esp32_wroom_32.ino]
2025-01-12 Increment version to v1.6.7 and firmware v8 so we can launch the bug fix to beta.
    [kv4p_ht_esp32_wroom_32.ino]
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2025-01-19 ADC auto DC removal (#168)
    * ADC bias injection
    * ADC auto DC removal
    1) deals with ESP32 ADC reference voltage variation
    2) 16 bit i2s transfers
    * DRA module retries.
    * Cleanup
    * Fixed merge confilict
    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
    [kv4p_ht_esp32_wroom_32.ino]
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2025-01-19 Fix bug #151 by returning the module type v/u/x where x means the radio module didn't respond. The Android app shows a more informative message rather than asking the user to flash the ESP32 again.
    [kv4p_ht_esp32_wroom_32.ino]
2025-01-20 Implements feature requests #87, #173, and #132. Adds 3 new advanced settings to every memory, rx tone, custom offset khz, and skip during scan. This required firmware changes that break the communic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
    [kv4p_ht_esp32_wroom_32.ino]
2025-01-21 Bug fix for UHF implementation, where app restart would sometimes fail to apply the saved UHF/VHF setting properly, and it would think the firmware is not responding.
    [kv4p_ht_esp32_wroom_32.ino]
2025-01-22 Android: Switch AudioTrack to the AudioFormat.ENCODING_PCM_16BIT (#179)
    * Android: Switch AudioTrack to the AudioFormat.ENCODING_PCM_16BIT
    As some devices have broken PCM8 support
    * signed pcm8 on wire
    * Fix for afskDemodulator
    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
    [kv4p_ht_esp32_wroom_32.ino]
2025-01-25 More robust command extractor state machine (#187)
    * More robust command extractor state machine
    Old one was loosing data
    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
    [kv4p_ht_esp32_wroom_32.ino]
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2025-01-25 Fix a bug with how last active frequency was being stored in DB and loaded on app start.
    [kv4p_ht_esp32_wroom_32.ino]
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2025-01-26 USB Serial driver patch (#192)
    * USB driver patch
    Refactored SerialInputOutputManager:
    - Implemented multiple read buffers to improve USB reading efficiency and reduce latency.
    - Used separate threads for reading and writing, enhancing concurrency and performance.
    - Removed read timeouts, as they are not necessary for event-driven data reading.
    These changes enhance the responsiveness, reliability, and robustness of USB communication.
    * fixed merge
    * fixed merge
    * cleanup.
    * Removed unused import
    [UsbSerialPort.java]
2025-01-26 Fix crash bug when opening settings without a radio connected.
    [kv4p_ht_esp32_wroom_32.ino]
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2025-01-28 Fix packaged firmware with the app, seems to have been old version by mistake.
    [kv4p_ht_esp32_wroom_32.ino]
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2025-01-30 Add hardware detection. Fix always-open squelch on v2 boards. (#205)
    * ADC_ATTEN_DB_12 is only defined in some versions? #198
    * Hardware version detection. Fix v2.0 always-open squelch. #203
    * Hardware version detection. Fix v2.0 always-open squelch. #203
    * Cleaning formating/indenting from merge wackiness. No symantic changes. #203
    [kv4p_ht_esp32_wroom_32.ino]
2025-01-30 Auto boot loader (#206)
    * Auto boot loader
    - extended serial port to be able to set DTR and RTS together
    - used this method to enter to the bootloader
    - fixed drain(). The current serial driver actually rejecting small buffers
    - cleaned up waiting for reply
    * AI feedback
    [Cp21xxSerialDriver.java, UsbSerialPort.java]
2025-02-02 Fix SA818 Module Definition and Improve Squelch Behavior (#216)
    * fix modile definition
    1) DRA818 -> SA818
    2) removed redundant code for Fade-in Fade-out SQ. Actually fixes loud bang after cold start.
    * PR feedback
    * PR feedback
    * PR feedback
    * Update arduino.yml
    [kv4p_ht_esp32_wroom_32.ino]
2025-02-05 Add NeoPixel support. (#208)
    * Added NeoPixel support. #207
    * Removed dependency on Adafruit NeoPixel. Added breathing. #207 #208
    * Cleanup proposal
    * Pedantic integer math changes. Explicit uint16_t cast, fix "color-1". #208
    * https://github.com/VanceVagell/kv4p-ht/pull/208#pullrequestreview-2595828045 #208
    ---------
    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
    [kv4p_ht_esp32_wroom_32.ino]
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2025-02-11 Small tweaks: (#221)
    * Small tweaks:
    1) Extracted debugging stuff to the "debug.h"
    2) "release" profile, which removes all debug information.
    3) pinned `espressif32 @ 6.10.0`
    4) removed warnings
    * fixed forward declaration
    * added headers
    * added header
    * Cosmetics
    * Cosmetics
    * Cosmetics
    [globals.h, kv4p_ht_esp32_wroom_32.ino, led.h]
2025-02-15 Improve Handshake Process with HELLO Message (#230)
    * Improve Handshake Process with HELLO Message
    * tweaks
    * tweaks
    * NPE
    * Tweaks:
    Ensured only one active timeout by clearing all pending callbacks before scheduling a new one, preventing stale events from affecting the connection state.
    * Increased timeout
    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
    [globals.h, kv4p_ht_esp32_wroom_32.ino]
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2025-03-04 Fixed race condition (#243)
    * Fixed race condition
    Do not process COMMAND_HOST_TX_AUDIO when mode not TX
    * Removed async processing:
    1) Delayed audio transmission is no longer needed; data can be pushed directly to the buffer.
    2) Delayed PttUp was likely introduced due to (1) and is now unnecessary since everything is properly ordered within the buffer.
    * Log failed "ESP_ERROR_CHECK"
    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
    [kv4p_ht_esp32_wroom_32.ino]
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2025-03-07 [pcb] Fixes for test firmware so it doesn't break flashing on first connect to the app (#245)
    * Prevent serial output in test code.
    * Making dimensions available without kicad.
    [kv4p-ht.kicad_pcb]
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2025-03-22 Fix APRS RX/TX (#249)
    * Fix APRS rx
    * Fix TX
    * .communication_format = I2S_COMM_FORMAT_STAND_I2S
    * Round the silence buffer sizes to the nearest multiple of PROTO_MTU
    This should reduce waste generated by multiple calls of the "sendAudioToESP32()"
    * Reduce serial blocking
    1) increased buffer
    2) removed SAMPLING_RATE_OFFSET
    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
    [globals.h, kv4p_ht_esp32_wroom_32.ino, txAudio.h]
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2025-04-07 Use Arduino Audio Tools for ADC/DAC and Transmit Compressed OPUS Audio over the wire (#252)
    * Switch to the audio-tools
    * OPUS -> RX
    * Flow control host->esp32
    * Workaround for corrupted "ConverterAutoCenter".
    * clanup
    * clanup
    * Pinned arduino-libopus
    * Added header
    * Merge branch 'audio-tools' into audio-tools-opus
    * Merge branch 'audio-tools' into audio-tools-opus
    * Merge branch 'audio-tools' into audio-tools-opus
    * Nicer transition of TX -> RX
    * AI feedback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
    [buttons.h, globals.h, kv4p_ht_esp32_wroom_32.ino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]
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2025-04-13 Update app version to v1.8.0 and firmware to v13, bundle them in preparation for a release. Also reverted the debounce change, since it didn't make any difference. That bug can't readily be reproduce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
    [kv4p_ht_esp32_wroom_32.ino]
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2025-04-16 Fix hardware test firmware, breaking initial Flash from the phone. (#259)
    * These are the old "filter test boards." No longer relevant.
    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
    [UHF-Filter Test.kicad_pcb, UHF-Filter Test.kicad_sch, VHF-Filter Test.kicad_pcb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]
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2025-04-19 v2.1b: VHF or UHF. Support 80x50x20mm metal case. (#262)
    * A version of v2 that fits in a 20x50x80mm extruded aluminum case.
    * Working on a different case version of kv4p board.
    * Minor changes.
    * Differentiating file names from ../KiCAD/
    * More work on v2.1: UHF support, USB CMCC, 80x50x20mm case. #22
    * v2.1b as ordered 2025-04-17. VHF and UHF #22. SAO headers. PTT buttons. User LED.
    * Remove duplicate PDF.
    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
    [bom.csv, designators.csv, kv4p-ht-metal-case.kicad_pcb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]
2025-04-27 Protocol: Exit loop after each frame. (#256)
    * Increased priority of the `buttonsLoop()`
    May fix https://github.com/VanceVagell/kv4p-ht/issues/254
    * Increased priority of the `buttonsLoop()`
    May fix https://github.com/VanceVagell/kv4p-ht/issues/254
    * Protocol: Exit loop after each frame
    Allows other subsystems a chance to run by giving up CPU time between frames.
    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
    [kv4p_ht_esp32_wroom_32.ino, protocol.h]
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2025-04-27 Documented quirks of hardware revisions (#265)
    To avoid confusions.
    [globals.h]
2025-05-18 Documentation of Hardware pins reversed (#286)
    Fixes: https://github.com/VanceVagell/kv4p-ht/issues/279
    [globals.h]
2025-05-18 Speculative fix for bug #287 which has been happening intermittently. This gives the radio 3 seconds to start instead of 2 seconds. If this doesn't resolve the issue we COULD try a little longer, but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
    [kv4p_ht_esp32_wroom_32.ino]
2025-05-18 Proposed approach to fix NPE's in future (#271)
    * Proposed approach to fix NPE's in future
    * AIfeedback
    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
    [SettingsActivity.java]
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2025-08-02 Switch from internal DAC to I2S PDM output (#308)
    * Use PDM for TX
    * Fixed click..
    [txAudio.h]
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2025-08-03 Fix bug #310 which was causing audio artifacts that made APRS decoding inconsistent. Turns out the way we were communicating with the radio module via Serial was blocking the audio read during that b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
    [kv4p_ht_esp32_wroom_32.ino]
2025-08-03 Re-fix #310, since the previous fix was not adequate. Also, beginnins of exception fixes for bug #294.
    [kv4p_ht_esp32_wroom_32.ino]
2025-08-03 Revert the RSSI changes meant to solve bug #310, which were ineffectual. A subsequent commit is expected to address this more holistically.
    [kv4p_ht_esp32_wroom_32.ino]
2025-08-03 Confirmed workaround for bug #310, which disable RSSI polling on v1.x PCBs only when on the APRS screen. It turns out v2.x PCBs do not have this issue because there's no cross-talk between the Serial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
    [kv4p_ht_esp32_wroom_32.ino, protocol.h]
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2026-02-28 Do not apply settings in .onResume()
    Apply them when returning from Settings via activity result instead. The original issue fixed in ea86d597 (https://github.com/VanceVagell/kv4p-ht/commit/ea86d597fbc899cf762d24d32c38227b4cce0cfa) ("Fix a small bug where if you open settings while scanning and close settings, there will be no audio until you tap a memory or enter a frequency.") does not appear to reproduce anymore, so use the standard return path instead.
    [SettingsActivity.java]
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2026-05-03 Replace serial framing with KISS transport
    [protocol.h]
2026-05-04 Fix for choppy audio.
    [protocol.h]
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2026-05-12 As we already have mode in state, we can use it.
    Plumbing to display TX state in UI for https://github.com/VanceVagell/kv4p-ht/issues/384
    [kv4p_ht_esp32_wroom_32.ino]
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2026-05-12 Fixed "skipped" group/filter
    Looks like sometimes we have "OK" in buffer from RSSI
    [kv4p_ht_esp32_wroom_32.ino]
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2026-05-17 Initialize firmware radio state from safe defaults
    - Introduce new state flag HOST_STATE_TX_ALLOWED
    - On firmware startup, load NVS values when present.
    - If NVS keys are missing, use safe module defaults:
    - VHF default frequency: 144.0000
    - UHF default frequency: 435.0000
    - bandwidth: 25k
    - tones: none
    - squelch: 0
    - memoryId: -1
    - Mark the radio config valid and initialize the SA818 from that state before sending HELLO.
    - Keep `HOST_STATE_TX_ALLOWED` false by default unless previously saved / explicitly allowed by Android, so receive works immediately but transmit remains guarded.
    [kv4p_ht_esp32_wroom_32.ino, protocol.h]
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2026-05-20 Quick and dirty fix for issue #405 where hosts using it as a KISS TNC were sometimes confused by the device state packets we send.
    [kv4p_ht_esp32_wroom_32.ino]
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2026-05-20 Implement ability to select an APRS position icon in settings for issue #174.
    [SettingsActivity.java]
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2026-05-26 Replace live voice codec with G.711 u-law
    [globals.h, kv4p_ht_esp32_wroom_32.ino, txAudio.h]
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2026-07-18 Fix soft squelch transition after TX
    Keep the reported soft squelch state cordoned while RX DSP warms after a transition, and bypass the detector entirely for SQ level 0 so the SQL indicator stays open when squelch is disabled.
    Fixes #434
    [softSquelchEffect.h]
2026-07-18 Use hardware SQ pin to freeze soft squelch after TX
    Sample the radio module SQ pin continuously and pass that state into
    SoftSquelchEffect. While hardware SQ is active, skip the soft squelch DSP so
    the detector preserves its last state instead of reacting to transition audio.
    Remove the previous synthetic transition cordon timer and init-time cordon
    hook, since the hardware SQ gate now provides the transition holdoff.
    [kv4p_ht_esp32_wroom_32.ino, softSquelchEffect.h]
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2026-09-27 Add missing official case designs to repo, move community designs to a standard location.
    [LEFT HANDED - Sleek KV4P HT case (for PCB 2.x).stl, LOGO INLAY - Sleek KV4P HT case (for PCB 2.x).stl, NO PTT - Sleek KV4P HT case (for PCB 2.x).stl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]
2026-09-28 PR feedback
    - Remove the APRS-IS server control and always use rotate.aprs2.net:14580.
    - Rename iGate and nearby APRS-IS settings and update Chinese translations.
    - Remove IS indicators while preserving source metadata.
    - Align object timestamps with other APRS cards.
    - Anchor startup feed scrolling at the actual last row without interrupting user scrolling.
    - Upgrade java-aprs to 0.2.5 and test automatic outgoing message/beacon APRS-IS copies.
    - Restore dedicated-frequency beaconing during scans using firmware TX override.
    - Schedule APRS housekeeping with fixed delay on the ordered worker, without queued catch-up ticks.
    - Remove the History UI control, retain filtering plumbing, and use al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
    [SettingsActivity.java]
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2026-09-30 Avoid redundant SA818 retune for current-channel APRS
    [kv4p_ht_esp32_wroom_32.ino]
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

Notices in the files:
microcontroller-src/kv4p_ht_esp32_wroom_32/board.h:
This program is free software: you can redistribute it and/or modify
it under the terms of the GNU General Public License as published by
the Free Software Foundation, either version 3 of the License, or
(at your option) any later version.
